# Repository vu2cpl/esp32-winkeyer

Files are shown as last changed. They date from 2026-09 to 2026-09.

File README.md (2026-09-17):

# VUKEYER

VUKEYER is a WinKeyer-protocol compatible CW keyer on an ESP32, reachable over WiFi. Iambic
paddle keying with local element generation, a K1EL-compatible host
protocol so logging software talks to it as a WinKeyer, and an optional
FlexRadio backend that keys a 6000/8000-series radio over the network.
Settings are edited from a front-panel OLED's companion web page at
`vukeyer.local` and persist across power cycles.

WinKeyer protocol by Steve K1EL. K3ng CW keyer by Anthony Good K3NG used
as a behavioural reference; the implementation here is original.

Formerly "ESP32 WinKeyer". Renamed 2026-09-17, because WinKeyer is K1EL's
product name: this is a compatible keyer, not a WinKeyer.

## Status

| Piece | State |
|---|---|
| Keyer core — iambic A/B, sidetone, PTT, pot, break-in | working, bench-verified |
| Speed pot on GPIO 34 | working, wired and tracking on hardware |
| WinKeyer protocol engine (WK 2.3 host mode) | working with RUMlogNG; **audited against a genuine K1EL WK3.1 on 2026-09-13; status byte, load-defaults order, admin table and pot byte fixed and re-verified the same night; echo now paced per letter on both backends, within ~60 ms (local) / ~150 ms (Flex) of the K1EL**; admin 0 (Calibrate) argument byte fixed the following morning — it had desynced RUMlogNG's session setup ([findings](docs/k1el-probe-2026-09-13/README.md)) |
| WiFi TCP transport + mDNS `vukeyer.local` | working, verified over WiFi |
| FlexRadio backend — **paddle keying over the network** | working, verified on a 6600. **Fixed 2026-09-17:** CW went out at 0 W after a GUI client (SmartSDR/Maestro/AetherSDR) restarted or changed; the keyer now follows the GUI client and no longer sends `client bind` |
| RUMlogNG over USB serial (1200 8N2) | working — memories, typed text, echo |
| Host bridge (`tools/wk-bridge.py`) | implemented, never driven by a real logger; macOS will not let a PTY appear as `/dev/cu.*`, so a logger cannot select it there |
| OLED status panel (SH1106/SSD1306 128x64) | working, SH1106 at 0x3C on hardware; sent CW scrolls on the bottom band while sending (approved on hardware 2026-09-17) |
| HD44780 LCD 16x2 / 20x4 | working; the slice warning on it is untested |
| Settings web page at `vukeyer.local` | working; one screen without scrolling from ~880x1150 upwards |
| SEND / STOP as one button on the page | working; per control — text, tune, each memory, FSK |
| Persisted settings (NVS) | working, verified across a hard reset |
| Message memories (6) with `%C` expansion | working from the web page and a logger |
| Practice mode — sidetone only, nothing transmitted | working on hardware (2026-09-17), Flex backend |
| RTTY FSK on GPIO27 | implemented, polarity unverified on air |
| MQTT status + heartbeat | working against the shack broker |
| Arduino core | **3.3.11 / IDF 5.5.5** (pioarduino); 2.0.17 crashes under load |

**Bluetooth keyboard: built in, off by default, parked — it does not fit
on a classic ESP32.** A BLE keyboard (Amkette Optimus) pairs and types
reliably in a standalone probe (`src/probes/ble_kbd_probe.cpp`,
`ENV=ble-kbd-probe ./flash.sh`), and the keyer has the full feature: a
BT KEYBOARD card with scan/pair/forget, F1–F6 memories, Esc, PgUp/PgDn
speed, `/bt` on the CLI. But with the whole keyer running, Bluedroid leaves
only ~26 KB of heap — too little for WiFi, so the board drops off the
network. A boot-time check now switches Bluetooth back off and restarts
when free heap is under 60 KB, and the page says why. Realistic routes are
an ESP32-S3 (lighter NimBLE stack) or a PSRAM board — see `HANDOVER.md`.
Classic-Bluetooth-only keyboards are not supported by the core either way.

**Enclosure:** a two-part 3D-printable case with OLED window, pot, KEY LED,
five RCA sockets for KEY/PTT/FSK, a 3.5 mm paddle jack, 5 V and USB-C, and
a bay for the opto board (5 × PC817, or an LTV847 quad + LTV817) —
parametric OpenSCAD with built-in fit checks, in
[`enclosure/`](enclosure/README.md). Dimensioned from measured
parts; not yet printed. Measure yours if they are a different make.

**One hardware caveat on a devkit.** The USB-serial chip's DTR/RTS lines
reach the ESP32's reset pin, so a logger holding that port can reset the
board or hold it in reset — mid-over, which leaves a networked radio
transmitting. Measured: `RTS` asserted with `DTR` not asserted holds it
down indefinitely. Either drive the keyer through a separate USB-serial
adapter wired to TX/RX/GND only, or cut the auto-reset link to EN. See
"Serial / USB" below.

## Quick start

```bash
python3 install.py     # detects the host, prompts for local settings, verifies the build
./flash.sh             # build + upload (picks the serial port)
./monitor.sh           # serial monitor, 1200 baud
```

**PlatformIO must run on Python 3.10 or newer.** This firmware builds
against Arduino core 3.x (the pioarduino platform), which refuses older
Python with a bare `ERROR: Python version must be 3.10 ...` that never says
which PlatformIO it means. `install.py` checks first and offers to create
one in `~/.pio-venv313`, leaving any existing install alone; `flash.sh` and
`monitor.sh` find it the same way (`PIO=/path/to/pio` overrides). Why the
newer core: 2.0.17's `WiFiClient` double-frees an lwIP buffer under heavy
inbound traffic, which crashed this keyer within minutes of sending
memories to a FlexRadio — see `HANDOVER.md`.

The app partition is the single 3 MB `huge_app` layout, because the newer
core filled 94.8% of the default one. Nothing here uses OTA. Flashing
rewrites the partition table, so an older board needs no special steps.

`install.py` detects macOS, Raspberry Pi, Linux or Windows (with a manual
override), then asks for your MQTT broker, mDNS name and setup-AP details.
Answers go to **`include/secrets.h`**, which is git-ignored and overrides
the defaults in `config.h` — so a clone stays clean and an upgrade never
collides with your local edits. Press Enter through it all to accept the
defaults; nothing here is required to key CW.

**If the first build fails with "Failed to install Python dependencies
into penv"**, the ESP32 platform could not build its own Python
environment — PlatformIO's problem, not this firmware's. In order: update
the core (`pip install -U platformio`); delete the half-installed
`~/.platformio/platforms/espressif32*` and
`~/.platformio/packages/tool-esp_install*` and re-run, because a partial
install never repairs itself; on Windows use Python from python.org rather
than the Microsoft Store build, whose sandboxed paths break virtualenv
creation; and check that antivirus or a proxy is not blocking pip. `pio run
-e esp32-vukeyer -v` shows the underlying pip error.

**On Windows** `flash.sh` / `monitor.sh` cannot run, so use the
cross-platform equivalents, which pick the port the same way:

```bash
python install.py flash            # build + upload
python install.py monitor          # 1200 baud
python install.py monitor 115200   # after /baud 115200
```

The port is never guessed when several boards are attached — some CP2102s
share factory serial `0001`, so the wrong board would be flashed silently.

1. First boot opens WiFi AP **`vu2cpl-vukeyer-setup`** (password
   `vu2cpl1234`). Join it from a laptop or phone; a captive portal opens
   where you pick **your own network** and enter its password. Creds
   persist in NVS. The portal does not time out, and the keyer keys
   normally while it is open — onboarding is non-blocking by design.

   Put the keyer on the **same subnet as the logging computer** (and the
   radio, if using the Flex backend): `vukeyer.local` and Flex discovery
   are both broadcast-based and do not cross subnets or VLANs. For the
   radio there is a way round it — **Find radio** on the web page (see
   FlexRadio below).

   `/wifi` shows the current network, `/wifi portal` reopens the portal,
   `/wifi reset` clears the saved credentials and reboots.

   **Security note:** the WinKeyer TCP port is unauthenticated — anyone on
   that network can key the transmitter. Use a trusted LAN, not a guest or
   open network.
2. Copy `include/secrets.h.example` → `include/secrets.h` and set
   `MQTT_HOST` plus the MQTT role account and password. `secrets.h` is
   git-ignored. Leave `MQTT_HOST` out and the build uses the placeholder
   in `config.h`, which is almost certainly not your broker.

## Wiring

**Schematic: [`docs/wiring.svg`](docs/wiring.svg)** — the whole station on
one page, including the second USB-serial adapter used as a listen-only
debug console and why it exists.

| Signal | GPIO | Notes |
|---|---|---|
| Paddle dit (tip) | 25 | internal pullup, paddle closes to GND |
| Paddle dah (ring) | 26 | internal pullup, paddle closes to GND |
| Key out | 33 | active high → opto (PC817 + 330 Ω, or LTV847 + 220 Ω) or NPN → rig KEY |
| PTT out | 32 | active high → opto (PC817 + 330 Ω, or LTV847 + 220 Ω) or NPN → rig PTT |
| Sidetone | 4 | passive piezo to GND |
| Speed pot | 34 | ADC1, 10 k **linear** pot across 3V3–GND, wiper to 34; **enable with `/pot on`** |
| Status LED | 2 | onboard — lit while the key is down |
| OLED SDA | 21 | 128x64 I²C panel, optional |
| OLED SCL | 22 | |
| KEY out 2 | 18 | radio 2 KEY, same drive as radio 1 |
| PTT out 2 | 19 | radio 2 PTT |
| FSK out | 27 | RTTY keying line, mark = idle (invertible) |

Paddles need no external parts.

**Debug console (optional, and very useful).** A second USB-serial adapter,
3.3 V, wired **RX ← GPIO1 (TXD)** and **GND ← GND**, with its **TX left
disconnected**. That last point matters twice: two transmitters on one RXD
line would fight, and with no TX wire nothing can be injected into a
logger's session. It gives a console to watch while a logger owns the
board's own USB port — which is how the crash backtrace that ended a day of
mystery resets was finally captured. The console is muted at 1200 baud, so
set `/baud 115200` from the web page when you want it to talk.

**Speed pot.** CW end to 3V3, wiper to GPIO 34, CCW end to GND, plus a
100 nF ceramic from wiper to GND at the pot — GPIO 34 is an unbuffered
ADC input and picks up sidetone PWM hash without it. Reversing the ends
just reverses the knob. Linear taper: a log pot wastes most of its travel.
Default range is 10–35 WPM (`/pot 10 35` to change). The knob is disabled
in firmware until `/pot on` is given, because GPIO 34 floats on a board
with no pot wired; that setting then persists.

Expect the top of the knob's travel to be a small dead zone: ADC_11db
saturates near 3.1 V rather than 3.3 V. Normal ESP32 behaviour.

The speed follows the knob through a **0.6 WPM hysteresis band**. A pot
parked on a step boundary otherwise alternates between two speeds forever,
and each flip is both a speed change and an unsolicited WinKeyer pot byte —
a stream that saturates a 1200-baud host link. Hysteresis is the right cure
rather than heavier smoothing or a settle delay: those fix the dither by
adding lag to every deliberate turn as well, which the operator feels at
once as a sluggish knob.

**OLED (optional).** VCC→3V3, GND→GND, SDA→21, SCL→22. Most breakouts
carry their own pull-ups; if yours does not, add 4.7 kΩ from each line to
3V3. The firmware probes 0x3C then 0x3D at boot and stays off if nothing
answers, so an un-wired board is unaffected.

**The I²C bus runs at 100 kHz by default**, and that is deliberate. An
earlier version tried 400 kHz and kept it if the panel answered its address
there — which proves nothing, because an address probe is one byte and a
frame is a thousand. A panel on breadboard leads passes the probe and
renders nothing, giving a display the firmware reports as present and
enabled while the glass stays dark. `/disp fast` opts into 400 kHz on
wiring that deserves it (~25 ms a frame against ~100 ms); the choice
persists, and `/disp slow` goes back.

**If the panel stays dark, run `/i2c`.** It scans the whole bus and prints
every address that answers, so "wired wrong" and "wrong address" stop
looking alike. It also adopts a panel wired up after boot — no reset
needed. Detection runs at 100 kHz on purpose: a panel on breadboard leads
answers reliably at 100 kHz but only intermittently at 400 kHz, which
otherwise shows up as a display that works on some boots and not others.
Rendering then moves to 400 kHz only after the panel proves it answers
there (a 128x64 frame is 1 KB — ~25 ms at 400 kHz, ~100 ms at 100 kHz, all
of it inside a blocking transaction). The boot line reports which speed
won; a 100 kHz fallback is your cue to add pull-ups or shorten leads.

**Four panel types are supported, all I²C on the same two pins:**

| Type | Address | Layout |
|---|---|---|
| OLED SH1106 128x64 (1.3") | 0x3C / 0x3D | large WPM digits, activity box, sent CW scrolling |
| OLED SSD1306 128x64 (0.96") | 0x3C / 0x3D | as above |
| LCD 20x4 via PCF8574 backpack | 0x27 / 0x3F | four text rows |
| LCD 16x2 via PCF8574 backpack | 0x27 / 0x3F | speed + one status row |

The **family is auto-detected** — OLEDs and LCD backpacks live at different
addresses — so one firmware runs whichever panel is plugged in. Swap the
panel and pick **Auto-detect** on the web page (or `/disp auto`) to re-probe;
no reflash.

What *cannot* be detected, because each pair shares an address:

- **SH1106 vs SSD1306** — wrong choice puts the image 2 px right with a
  garbage sliver down the left edge (SH1106 has 132 columns of RAM to the
  SSD1306's 128). Fix with `/disp ssd1306`.
- **16x2 vs 20x4** — same chip, so a wrong choice just truncates or leaves
  rows blank. Fix with `/disp lcd16x2`.

### Reading the display

**OLED, 128x64:**

```
VUKEYER             -52dBm     link quality, or "no wifi"
--------------------------
 28 WPM  POT        [ KEY ]    speed, where it came from, activity
--------------------------
FLX1   B  HOST+NET             backend+radio, iambic mode, host links
192.168.1.20                   address, or "join <setup AP>"
```

**While sending, the bottom two lines become the CW itself**, in large
letters (12 characters), newest on the right and scrolling left: paddle
and memories, typed text and a logger's text alike. They go back to the
backend line and the address once sending has stopped: no key-down in the
last 150 ms, no tune carrier, PTT off, and 3 s since the last character.
PTT counts, so on a long PTT tail the text stays up until the tail ends.
The LCDs switch back on the same rule.

```
VUKEYER             -52dBm
--------------------------
 28 WPM  POT        [ KEY ]
--------------------------
    CQ CQ VU2CPL               what is being sent, large
```

Paddle text is the keyer's own decode of your sending, so an odd letter
there means the decoder read your spacing differently, not a fault in the
radio. Buffered text appears as the keyer's sidetone copy finishes each
character, which on the Flex is held back to match the air.

In practice mode the title reads `PRACTICE NO TX`, ahead of any slice
warning.

**LCD 20x4** carries the same fields as text. Row 3 shows the last 20
characters sent while sending, and the address otherwise. Row 4 gives way
to `PRACTICE NO TX` or a slice warning:

```
28 WPM POT   KEY
FLX1   B HOST+NET
192.168.1.20
-52dBm  tail 400ms
```

**LCD 16x2** has room for two rows, so the iambic mode letter is dropped —
it changes once a year, whereas the live radio can change between overs.
Row 2 shows the last 16 characters sent while sending:

```
28WPM POT FLX1
192.168.1.20
```

Every indicator:

| Shown | Meaning |
|---|---|
| `28 WPM` | current speed |
| `POT` | speed is following the knob |
| `FIX` | speed was set by host, CLI or web — the knob is off |
| `KEY` | key is down right now |
| `TUNE` | continuous carrier, latched until you stop it |
| empty box | idle |
| `LOCAL` | keying the wire: KEY on GPIO33, PTT on GPIO32 |
| `FLX` | keying the radio over the network, slice ready |
| `FLX!` | radio connected but **the slice is not in CW mode** — it will transmit nothing |
| `FLX?` | **not connected** to the radio at all |
| `…1` `…2` `…B` | which radio the key line drives — 1, 2, or **both** |
| `A` / `B` | iambic mode (not shown on 16x2) |
| `HOST` | a WinKeyer host session is open (a logger is attached) |
| `----` | no host session — placeholder, so the field keeps its width |
| `+NET` | a TCP client is connected over WiFi as well |
| `-52dBm` | WiFi signal; `no wifi` if the link is down |
| `SLICE USB, NOT CW` | the Flex's slice is in another mode; `NO SLICE IN USE` if there is none. OLED: replaces the `VUKEYER` title. 20x4: replaces row 4 (dBm/tail). 16x2: alternates with the IP every 2 s when not sending, as `SLICE USB NOT CW` (`DIGU: NOT CW` for 4-letter modes) |

The radio number is attached to the backend as one token — `LOCAL1`,
`FLX2`, `FLXB` — rather than spaced, because the "both" letter `B` would
otherwise sit beside the iambic mode letter, which is also `A` or `B`.

`FLX!` is the one worth knowing on sight: everything looks connected and
the keyer reports no error, but SmartSDR has no slice in CW mode so nothing
reaches the air. Every panel also spells it out with the slice's mode (see
the table), and the web page shows an amber banner. Memories go to the
radio as `cwx` text, which it sends only
on a CW slice. The paddle's PTT still keys the radio in other modes, so
this can look like "paddle works, memories don't".

### LCD power — read this before blaming the firmware

**HD44780 LCDs want 5V, and the ESP32 is a 3.3V part.** Run one from 3V3
and the characters come out so faint they look absent, at any setting of
the contrast trimmer, with a dim backlight to match. Nothing in software
can help: contrast on an HD44780 is the analogue Vo pin, not a driver
setting. This is why the OLEDs are trouble-free — SSD1306 and SH1106
modules are native 3.3V.

Feed the LCD's **VCC from the devkit's 5V / VIN pin** (USB 5V). But note
the trap: the PCF8574 backpack's onboard pull-ups then tie SDA and SCL to
5V, and **ESP32 GPIOs are not 5V tolerant** — that is how GPIO21/22 get
damaged. Two safe ways:

1. **Move the pull-ups.** Remove the backpack's two pull-up resistors and
   fit 4.7 kΩ from SDA and SCL to **3V3** instead. I²C is open-drain — the
   chip only ever pulls the line low — so with the pull-ups on 3.3V the bus
   never exceeds 3.3V while the LCD still runs at 5V. Tidiest answer.
2. **A bidirectional level shifter** (BSS138-type) between the ESP32 and
   the backpack. No soldering on the module.

Before either, sweep the contrast trimmer through its full range with the
panel powered. Faint ghosting at one end confirms the voltage diagnosis; a
completely dead panel at every setting points at wiring or the address
instead — run `/i2c`.

See `include/pins.h`.

## Serial / USB — baud matters

**The firmware defaults to 1200 baud, 8N2.** That is the K1EL WinKeyer
serial standard, and loggers open the port that way without asking —
RUMlogNG was observed doing exactly this (`stty` reported
`speed 1200 baud; cs8 cstopb`). At any other rate a logger's handshake
arrives as noise and no session ever opens, which looks exactly like a
dead keyer.

The console shares that port, so at 1200 baud the boot log is trimmed to
one line and WiFiManager's chatter is silenced — every character printed
is one the host waits through before its Host Open is answered. Use the
web page or `/status` for detail.

```bash
/baud 115200     # readable console; a logger will NOT talk to it here
/baud 1200       # WinKeyer standard; what loggers expect
./monitor.sh          # defaults to 1200
./monitor.sh 115200   # when you have set the console rate
```

The **USB / WIFI** section of the SYSTEM card on the web page sets the same thing, and is the
escape hatch if you pick a rate you cannot monitor at — WiFi is unaffected
by the serial rate.

**Known limitation of this board, and it is worse than noise.** The USB
chip's DTR and RTS lines drive the ESP32's EN (reset) and GPIO0 through the
devkit's auto-reset transistors. Two consequences, both measured here:

- **Opening or closing the port resets the board.** The ROM then prints its
  banner at 115200 whatever the firmware's rate is, so a logger sitting at
  1200 sees a burst of garbage before the handshake. Noise, not a fault.
- **`RTS` asserted while `DTR` is not holds EN low — the board stays dead**
  until the lines change. Silent: no boot banner, no WiFi, no app. A logger
  that parks the lines that way stops the keyer mid-over, and on the Flex
  backend the radio is left transmitting because the key-up never goes out.
  Measured 2026-09-12 with all four combinations; only that one kills it.

A real K1EL WinKeyer ignores DTR/RTS, so loggers drive them freely — this
is a devkit problem, not a logger bug, and no firmware can defend against
its own reset pin. Fixes, in order of preference:

1. **Disable the auto-reset link to EN.** Find the two `J3Y` transistors by
   the USB chip, identify by continuity which one's top leg (collector)
   reaches the `EN` header pin, and lift that leg. Flashing then needs
   BOOT held while EN is tapped. Bring the cut ends to a jumper if you want
   auto-flash back for development.
2. **Give the logger a serial adapter with only TX/RX/GND wired** to the
   keyer, DTR/RTS unconnected. No soldering on the devkit, but a second lead.
3. **Move to the ESP32-S3 env**, whose native USB has no DTR-driven reset.
   The env builds (fixed 2026-09-13) but has not yet been run on an S3
   board, and a logger opening its native USB port is untested.

## Sharing the port with a logger

**At 1200 baud the console is silent by default**, because that rate means
a logger owns the port: every character the keyer prints lands in the
logger's CW window as text. That covers the boot log, the reset reason, the
watchdog line and the ESP core's own logger (`E (1816) task_wdt: ...`),
which writes to the UART without passing through `Log::` — muting one and
not the other is why an early attempt still leaked. `/log on` turns it back
on; `/baud 115200` means "a human is here" and leaves it on. One thing
firmware cannot suppress: the ROM's own boot banner is printed at 115200
before any of our code runs, so a port opened at 1200 sees a character or
two of noise after every reset.

The console and the WinKeyer protocol share one serial port, so **while a
host session is open the console goes silent** (`src/log.cpp`). A `[FLEX]`
line written during a session is not a log message to the logger — it is
protocol data, and it appears in the logger's CW window as garbage text.
The web page and MQTT report the same state and do not touch serial, so
use those while a logger is connected.

### Sidetone while the radio is keying

On the Flex backend the radio generates buffered CW itself, so the keyer
has no elements of its own to sound and is silent while the rig transmits.
The same text is therefore also run through the local keyer purely for
**monitor sidetone** at the same WPM (`/monitor on|off`, or the checkbox on
the web page).

Those monitored elements are withheld from the key hook
(`Keyer::setHookPaddleOnly`) — otherwise they would key the radio a second
time on top of `cwx send`. Paddle elements and `tune` still reach the hook.

### Echo

WinKeyer character echo is **host-controlled**: mode-register bit 2. If a
logger never sets it there is no echo, and that is the protocol, not a
fault. `/api/state` reports `echo` and `modereg` so you can see what the
host actually asked for rather than guessing — RUMlogNG sets `0x07`, so it
does want echo.

Echo exists so the host can highlight the character being **sent**, which
makes it a timing signal, not just a copy. On the Flex backend the whole
buffer is handed to the radio in one batch, so echoing as characters are
queued dumps the entire message instantly: the host's highlight runs ahead
of the air and desynchronises, and after the first message later echoes are
discarded. Echo is therefore paced against the radio's own `cwx sent=`
progress reports. Measured at 20 WPM, `TEST DE VU2CPL` echoes over 5.5 s
with the gaps matching each character's length.

### Paddle echo — capturing hand-sent text

Separate from character echo, and separate in the protocol too: **mode
register bit 6**. When active, characters you send on the paddle are echoed
to the host so a logger can capture what was keyed by hand.

RUMlogNG sets `0x07` — it asks for character echo but **not** this — so
`auto` leaves it silent. Force it if you want hand-sent text logged:

```bash
/pecho on      # regardless of what the host asks for
/pecho auto    # follow the mode register (default)
/pecho off
```

The web page has the same control with a live `active`/`inactive` readout.

The decode is exact rather than signal decoding: the keyer generated those
elements itself, so it knows precisely what they were and only has to judge
where a character ends — 2 dit-times of silence for a character, 5 for a
word, both scaling with WPM automatically. Buffered text is excluded; the
host already knows what it asked for.

Two limits worth knowing: characters not in the Morse table decode to
nothing and are dropped, and a prosign keyed as merged elements comes back
as whatever single pattern it forms, not as the letters you had in mind.
Forcing echo on when the host did not request it may also confuse a logger
that is not expecting unsolicited characters — hence the switch.

## Two radios

`/radio 1|2|both` selects which KEY/PTT pair the keyer drives — radio 1 on
GPIO33/32, radio 2 on GPIO18/19 — and persists. `both` is deliberate, for a
rig plus an amp or monitor, but it keys two transmitters at once so it is
never the default. Switching radios drops every line first, so a
transmission can never strand the outgoing radio keyed.

## Practice mode

Tick **Practice** at the top of the KEYER box on the web page, or
`/practice on|off`. The keyer then makes sidetone for everything (paddle,
memories, typed text, a logger's text, TUNE) but transmits nothing:
- no KEY or PTT line is driven, and the PTT lead-in is skipped;
- nothing goes to a FlexRadio, neither `cw key` nor `cwx send`;
- a logger's PTT command is ignored, and RTTY SEND is refused.

Text plays with your own weighting and Farnsworth, as on the local backend.

An amber banner on the web page says so, and the OLED title, row 4 of the
20x4 LCD and row 2 of the 16x2 LCD (taking turns with the address) read
`PRACTICE NO TX`. Switching on or off stops whatever is being sent. The
keyer task makes the switch between elements, so a key-down sent to the
radio is always followed by its key-up.

**Practice is not saved.** The keyer always boots ready to transmit, so a
practice session can't carry through a power cycle into a contest.
`practice` in `/api/state` shows the current state.

## Message memories

Six slots of canned text in flash, played through whichever backend is
current. `%C` expands to your callsign, so a memory survives a contest call
change.

```bash
/call VU2CPL
/mem 1 CQ TEST %C %C K
/mem 1              # play it
/mem                # list all six
```

The web page has a MEMORIES card with SAVE and PLAY per slot (Send and FSK / RTTY sit below them in the same card); the PLAY of
the slot that is going out turns into a red STOP, so the stop is on the row
you pressed rather than somewhere else on the page. No GPIO cost —
front-panel buttons can be wired to these later.

**Anything that originates text must go through `HostLink::sendText()`**,
not `Keyer::sendChar()`. On the Flex backend the radio generates the CW and
those local elements are deliberately withheld from the key hook, so a
direct send produces sidetone and no RF.

## RTTY / FSK

An FSK keying line on **GPIO27** for a rig's FSK input: Baudot (ITA2) at
45.45 baud, 1 start bit, 5 data bits LSB first, 1.5 stop bits, mark idle.

```bash
/fsk RYRY DE VU2CPL     # send
/fsk baud 45.45         # or 50, 75
/fsk invert on          # if the rig wants mark low
/fsk diddle on          # LTRS while idle, keeps the far end synchronised
/fsk stop
/fsk                    # status
```

The web page has an FSK panel with its own send box. Its button is SEND
while the line is idle and turns into a red STOP for as long as the over is
going out — the same one button, not two.

**Polarity is the one thing you must confirm on air.** Getting `invert`
wrong prints reversed-case gibberish at the far end rather than nothing, so
silence means a wiring fault and garbage means the wrong polarity.

Two implementation notes that matter if you touch this code. The bit timer
runs at the **half-bit** period, because the 1.5-bit stop is three
half-bits and a 22 ms bit cannot be timed from the 1 ms FreeRTOS tick
without ~4% jitter. And the far end's **LTRS/FIGS shift state is tracked
explicitly**: `Q` and `1` are the same five bits, so losing the shift
prints digits as letters for the rest of the over. Shift characters are
injected only when a character actually needs the other case, and space,
CR and LF are treated as neutral so they never force one.

Verified by timing, not by scope: `RYRY DE VU2CPL` takes 2.87 s at 45.45
baud against a theoretical 2.81 s, and 1.77 s at 75 baud against 1.70 s.
The 14-character message occupies 17 code times, which is the two shift
characters `2` forces.

## Power — read this if the keyer resets while you key

The ESP32 draws its heaviest current in short WiFi transmit bursts, and
paddle keying on the Flex backend sends a packet per key edge — roughly
twenty bursts a second at 25 WPM. On a marginal supply the 3.3 V rail sags
through those and the chip **browns out and restarts**.

It is **intermittent**, which is what makes it hard to pin: in testing the
same board and cable browned out within two characters of keying on one
run and survived minutes of heavy paddling on the next. It does not track
any one cable or power setting reliably — it tips over when several small
things happen to line up (connector contact resistance, other load on the
same USB bus or hub, how the cable is seated).

How to recognise it: **the web page footer, or `/api/state`, reports
`last reset: BROWNOUT (power)`.** That comes from the chip's own brownout
detector, so it is conclusive. (A plain `power-on` is not — opening the
serial port pulls EN on this devkit and reports the same.)

What to do about it, in order of robustness:

1. **Fit a 470–1000 µF capacitor across 3V3 and GND**, short leads, at the
   board. This is the real fix: it adds margin without needing to know
   which factor is marginal on a given day.
2. **Power from a decent 5 V supply on VIN** rather than USB. An external
   supply held full power through heavy keying in testing.
3. **Lower the WiFi transmit power** — `/txpower 11`, or *WiFi power* on the
   web page. That roughly halves the burst current. It costs range (it
   affects how well the access point hears you, not how well you hear it),
   so treat it as a workaround rather than a cure.

## Bench-testing the key and PTT lines

The four outputs are plain active-high 3.3 V GPIOs, so an LED and a
resistor to GND is enough to watch them:

| Line | GPIO |
|---|---|
| KEY / PTT, radio 1 | 33 / 32 |
| KEY / PTT, radio 2 | 18 / 19 |

Anode to the GPIO, cathode through **330 Ω** to GND — about 4 mA, bright
enough and well inside what an ESP32 pin should source. Do not go below
~150 Ω.

**On the Flex backend the KEY line is deliberately idle** (the radio is
keyed over the network instead, so the rig is not keyed twice) — a KEY LED
will stay dark however much you send. Use `/backend local` to test it. PTT
is live on both backends.

`/tune` is the easiest test: a continuous key-down with PTT asserted, so
both LEDs sit steady rather than flickering through elements. Sending text
afterwards shows the sequencing — PTT leads the first element by the
lead-in and holds for the tail after the last.

`/radio 2` moves keying to the second pair and `/radio both` drives all
four, which is also the quickest way to confirm the `LOCALB` / `FLXB`
indicator on the display.

**A PTT line that is up for 10 s with nothing keying it is forced down**
by a safety backstop, and the console says so
(`PTT was stuck with no keying`). That is deliberate — a lost transition
must never leave a transmitter keyed — and it does not apply to `/tune`,
which is a key-down, or to RTTY, which holds the line for a whole over on
purpose. If you see it during ordinary sending, it is a bug: report it
with what you were sending and how long the keyer had been quiet
beforehand.

## Connecting logging software

The keyer speaks the WinKeyer protocol over a TCP socket. Loggers want a
serial port, so run the bridge:

```bash
./tools/wk-bridge.py
```

That creates `/tmp/vukeyer` (a symlink to a PTY) and shuttles bytes to
`vukeyer.local:8088`. Point the logger at that path and choose WinKeyer
as the keyer type. Verified hosts: anything speaking WK2 — N1MM+, DXLog,
RUMlogNG, MacLoggerDX, SkookumLogger, fldigi.

**RUMlogNG: set the keyer type to K3NG, not K1EL.** Both send the same
set-up. With K1EL, RUMlogNG keeps repeating host-open and ignores the
keyer's version-23 reply for 18 s to 2 minutes. At 1200 baud the queued
opens take that long to drain, and the keyer has to answer every one.
K3NG's keyer also reports 23, and with that setting the session opens at
once (measured 2026-09-17). The one exception is the **first open after
flashing the keyer**: even on K3NG, RUMlogNG floods host-open and then
shows the wrong speed. Close and reopen the port once after a flash. A
power cycle or restart does not cause it.

For **N1MM+ in a VM**, map the VM's COM port to the host TCP socket with
the VM's serial-over-TCP option instead of using the bridge.

Network latency does not affect CW: every element is timed on the keyer
(or on the radio, in Flex mode). The socket only carries text and status.

Wired fallback: the USB serial port is a text CLI at 115200 that switches
itself into the WinKeyer binary protocol as soon as a host-open command
arrives, and back to the CLI on host close.

## FlexRadio

```
/flex on                 # enable the backend (off by default, persists in NVS)
/flex ip 192.168.1.50   # pin the radio's address
/flex auto               # or rely on discovery (same subnet only)
/backend flex            # route buffered text to the radio — this transmits
```

**Discovery only works on the radio's own subnet** — it is a raw UDP
broadcast, unlike mDNS. If the radio is on another segment, pin the IP.

**Find radio** on the web page does that for you. It tries every address
in one /24 for the SmartSDR API port (TCP 4992) — a plain TCP connection,
which a router forwards where a broadcast is dropped — and lists what
answers as `IP · model · nickname` buttons; click one to set Radio IP.
Leave its box blank to scan the keyer's own subnet, or type the radio's
first three octets (`192.168.1`). About 15 s per /24, in a background
task so keying is unaffected. It is read-only on the radio: connect, read
the `V<version>` greeting that marks a Flex, ask `info`, disconnect.
`POST /api/flexscan?net=192.168.1` starts one; `GET /api/flexscan`
reports progress and results.

**In Flex mode the paddle keys the radio over WiFi — no KEY or PTT wire.**
The keyer asserts PTT (`xmit 1`), sends each element as `cw key 1/0` with
a `time=` timestamp so the radio *schedules* the edge rather than keying
on arrival, and releases PTT after a tail. That timestamp is what keeps
the CW readable across a jittery link; it is the same mechanism Maestro
and MORCONI use.

Sidetone stays local and follows your own paddle timing, so your fist
sounds right in the ear whatever the network is doing. The local key
output is disabled in this mode so the rig is not keyed twice.

**Requirements — both fail silently, with no error from the radio:**

- SmartSDR must have **a slice in use, in CW mode**. With no slice the
  radio simply transmits nothing. `/status` reports readiness, the web
  page and OLED show a warning naming the slice's mode, and the console
  warns when you key without it. The keyer follows the last slice the
  radio reports, not specifically the TX slice, so with two slices open
  the warning can be wrong.
- SmartSDR (a GUI client) must be connected — with none the radio reports
  `tx_allowed=0` and nothing may transmit at all.

**The keyer keys on behalf of that GUI client** by putting the client's
handle on every `cw key`. It follows the client: when SmartSDR, Maestro or
AetherSDR restarts it comes back under a new handle, and the keyer picks
that up by itself (`flex.guihandle` in `/api/state` shows the one in use).
A `cw key` under a handle that has gone is accepted with no error and
silently dropped, so that is the first thing to compare when paddle keying
raises PTT but makes no power.

**`client bind` is off by default** (`/flex bind on|off`, web page "bind
GUI"). On a 6600 in September 2026, binding to a GUI client that had just
connected left the radio's CW generator stuck: paddle keying and memories
both keyed the transmitter at 0 W until a stalled `cwx clear` released it.
Unbound, both work. If a keyer upgraded from an older build still has bind
switched on in its saved settings, switch it off.

**Sidetone delay (`/mondelay`, default auto).** The radio generates
buffered CW itself, so it starts a few hundred ms after being handed the
text — the network hop plus its own CW start — while the local monitor copy
starts at once. The sidetone therefore runs AHEAD of the air, which sounds
like the radio unkeying early. The keyer times that gap itself (from
`cwx send` to the interlock reporting TRANSMITTING, smoothed, and only when
the radio was idle first) and holds the monitor copy by it: measured 229 ms
on a 6600 over WiFi here. `/mondelay 250` pins a value instead, `/mondelay 0`
disables it. The first transmission after a reset has nothing measured yet.
Auto lines the copy up with the **radio**. A client that plays the radio's
sidetone back as audio (AetherSDR here) adds its own network and audio delay
on top, which the keyer cannot measure. Matching that by ear took a manual
245 ms here, against 87 ms measured. To keep following the measurement and
still cover the client, leave it on auto and add an **extra** (`/monextra N`,
0–1000 ms, **Delay extra** on the web page, saved): about 160 for AetherSDR
here. The extra is ignored for a manual value.

**The sidetone copy also follows the radio's real timing, per speed.** A
Flex sends each CWX dit unit a little long: about 0.7–0.8 ms more than
1200/WPM at every speed (735 µs at 10 WPM, 779 µs at 35 WPM here). A copy
at the exact rate drifts ahead through a long message. Because the extra is
roughly fixed in milliseconds, a percentage learned at one speed is wrong at
others. So the keyer learns it **per WPM, 5–50**: it times the radio's
`cwx sent=` reports over any run of 40+ units of its own text sent without a
pause (a run stops where the radio may have waited for typed text), refines that
speed's entry (smoothed, weighted by run length: a 234-unit CQ moves it a
quarter, a short typed word far less, because the radio's reports wobble by
up to ~100 ms), interpolates for speeds not played yet (700 µs
before anything is learned), and adds it to each unit of the copy, carrying
the sub-millisecond remainder. The table and the start delay are kept in
flash (written when an entry is first learned or has moved more than 50 µs
from the saved value, at most once a minute), so they survive a reboot. `cwextra` in `/api/state` is the value in use at the current speed.
`GET /api/cwtable` lists all 46 speeds (`runs` 0 = interpolated), and
`POST /api/cwtable?reset=1` forgets it. In step from 10 to 50 WPM on
hardware.

The monitor copy also ignores weighting and Farnsworth, because the radio
has neither — it exposes speed, iambic, break_in and qsk, nothing else. A
logger that sets Farnsworth (RUMlogNG sets 20 every session) would otherwise
stretch the sidetone against an unstretched transmission.

**The radio's CWX speed is kept equal to the keyer's.** Anything else on the
API — SmartSDR's own CWX speed control, for one — can change it, and then
the radio sends at its speed while the sidetone runs at ours: PTT drops with
the radio while the sidetone carries on for seconds. The keyer reads the
radio's reported `cwx wpm=` and, whenever the radio is idle and differs,
sets it back (at most every 2 s; never mid-message, where a logger's
buffered speed change is allowed to differ).

Tuning knobs, should keying misbehave on a different radio or firmware:
`/flex cmd key|ptt` (which keying command), `/flex bind on|off` (default
off, see above),
`/flex ptt on|off` (whether we assert `xmit`). Defaults are what works on
a 6600 running SmartSDR 4.2.20.

The `backend` setting persists in NVS, so it survives a reboot.

Not used: `cwx send`. It sends *text* for the radio to key itself, which
cannot carry a fist, and this radio refuses CWX to a second client
anyway. Wiring GPIO 33 to the KEY jack still works and is the
lowest-latency option, but is no longer necessary.

Paddle keying deliberately stays on the local key output — real-time
element timing over WiFi would carry the jitter. For a Flex in the same
shack, wire the key output to the radio's KEY jack and use the network for
buffered text.

## Tools

```bash
./tools/wk-test.py --serial /dev/cu.usbserial-0001   # exercise the protocol
./tools/wk-test.py --host vukeyer.local             # ...over WiFi
./tools/wk-bridge.py                                 # TCP → serial port
./tools/wk-timing.py --text "CQ TEST"                # timestamped status
./tools/flex-check.py                                # why isn't it keying?
./tools/uptime-watch.py                              # restarts, outages, stalls
./tools/console-capture.py /dev/cu.usbserial-0001    # console, without resetting it
./tools/flex-check.py --key                          # ...and key it (TRANSMITS)
./tools/flex-ptt-watch.py --keyer <ip> --radio <ip>  # keyer + radio PTT on one clock
./tools/boot-listen.py /dev/cu.usbserial-0001        # is it boot-looping?
./tools/ptt-check.py --ip <ip>                       # PTT sequencing + every STOP
./tools/host-watch.py --ip <ip>                      # what is a logger changing?
KEYER=<ip> ./tools/wk-trace-view.py                  # logger bytes, open floods folded
KEYER=<ip> ./tools/wk-open-timing.py                 # time the logger open handshake
KEYER=<ip> ./tools/flex-trace-record.py out.log      # record radio trace + CW table
./tools/cw-runs.py out.log                           # time each CW run in a recording
```

**`wk-open-timing.py` answers "is the keyer slow to connect?"** It opens
the USB port as a logger does (1200 8N2), times one host-open at a time,
then floods opens without waiting and measures how long the backlog takes
to drain. Close the logger's port first. On 2026-09-17 it showed the keyer
answers within ~8 ms, and that a flood of 5224 opens takes 95.7 s to drain
at 1200 baud: the slow RUMlogNG open is a backlog, not the keyer.

**`flex-trace-record.py` + `cw-runs.py` check the sidetone timing
learner.** Record while operating, then `cw-runs.py` splits the radio's
`cwx sent=` reports into runs the same way the firmware does and prints
each run's µs-per-unit. Compare those with the table steps in the
recording. That is how short typed words were found to pull the 25 WPM
entry up.

**`ptt-check.py` needs no paddle, no logger and no radio.** It drives the
keyer through its own API on the local backend and polls `/api/state` at
10 Hz, which is the only way to see faults like a PTT line that comes up
and drops one millisecond into the lead-in. It restores the backend it
found, but it does key GPIO33/32 — run it into a dummy load or with
nothing attached.

**`host-watch.py` answers "what is my logger doing to my settings?"** —
including `pincfg` and `hostdef`, the raw bytes of the two host commands
whose bit layout is not obvious from outside. A logger sends its defaults
at session OPEN, so close and re-open the session before concluding
anything: a mid-session toggle of RUMlogNG's own PTT boxes sends nothing
at all.

**`flex-check.py` is the first thing to run when the Flex will not key.**
Every prerequisite fails silently — the radio reports no error for a
missing slice, a slice in the wrong mode, or a missing GUI client — so it
checks all of them at once.

**`wk-timing.py` timestamps every status byte** and times the BUSY span
against the text's predicted duration. It also checks that no KEYDOWN
arrives for text: a genuine K1EL reports KEYDOWN for tune only. Counting status bytes in fixed windows
gives false negatives when a delayed burst lands outside its window; this
tells "not sent" from "reported late".

## Serial CLI

`/wpm N` `/mode a|b` `/swap` `/tune` `/pot on|off` `/pot <min> <max>`
`/ptt on|off` `/st N|on|off` (pitch 300-1000 Hz, default 600)
`/disp on|off` `/disp sh1106|ssd1306`
`/weight N` `/ratio N` `/farns N` `/lead N` `/tail N`
`/mondelay auto|N` `/monextra N` (sidetone delay; extra ms on top of auto)
`/practice on|off` (sidetone only, no TX; not saved)
`/backend local|flex` `/flex on|off|ip <addr>|auto` `/wifi [portal|reset]`
`/bt on|off|scan|forget` (on/off takes a restart) `/i2c` `/net` `/status`.
Any other line is sent as CW.

## Settings web page

`http://vukeyer.local/` (or the IP — `/net` prints it). Every label with a
dotted underline carries **hover help** — ranges, what a setting actually
does, and which GPIO it drives — so the panel stays scannable. Speed, mode,
paddle swap, sidetone, **weighting, dah ratio, Farnsworth, PTT lead and
tail**, pot enable and range, display, backend (with a **Find radio**
LAN scan for the Flex), plus a send box and tune. The page is four cards: **KEYER** (with Timing, Speed pot and
PTT sections), **MEMORIES** (with Send and FSK / RTTY), **BACKEND** and
**SYSTEM** (Display, USB / WIFI, BT keyboard). The Flex keying internals
(key verb, bind GUI, xmit) sit in a collapsed **Advanced keying** section with
a warning, because a wrong value leaves the radio silent with no error. Its
**DEFAULTS** button puts back the working set: `cw key`, bind GUI off, xmit
on. Live status LEDs for
host, TCP, key, tune, pot, Flex, OLED and KBD, polled once a second.

The **BT KEYBOARD** section of the SYSTEM card (off by default) enables Bluetooth — with a RESTART
button, since the switch applies at boot — then SCAN lists keyboards in
pairing mode, one click pairs, and a passkey is shown large if the keyboard
asks for one. One keyboard is kept; FORGET drops it. `GET /api/bt` carries
the detail and scan list; `POST /api/bt?scan=1|connect=<addr>&type=<n>|
forget=1|restart=1` does the rest (restart is refused while transmitting).
**On a classic ESP32 it switches itself back off at boot** for want of heap —
see Status above.

**Every button that starts something is its own STOP.** SEND, TUNE, a
memory's PLAY and the FSK send all turn into a red STOP while that thing is
transmitting, and go back when it ends — so exactly one STOP is on screen at
a time, on the thing you started. Stopping text or a memory clears the
radio's buffer as well as the keyer's.

Timing settings, all persisted and all validated the same way from the
CLI and the page:

| Setting | Range | Nominal | What it does |
|---|---|---|---|
| Weight | 10–90 | 50 | mark/space balance, **without** changing WPM |
| Dah ratio | 33–66 | 50 | dah length (50 = the standard 3 dits) |
| Farnsworth | 0, or 5–60 | 0 (off) | stretches only the gaps, to this WPM |
| PTT lead-in | 0–2000 ms | 50 | delay before the first element (GPIO32) |
| PTT tail | 0–2000 ms | 250 | hold after the last element |

**The tail releases two transmitters.** It sets both the local PTT line
and, on the Flex backend, the radio itself (`xmit 0`) — these are separate
timers and setting only one makes the control appear dead on whichever you
are listening to. `/api/state` reports `flextail` next to `tail` so you can
see they agree.

On the Flex backend the **KEY line (GPIO33) is idle** so the rig is not
keyed twice, but the **PTT line (GPIO32) stays live** for an amp or
sequencer — that is what lead-in still drives. The radio handles its own
T/R, so there is no Flex lead-in.

Out-of-range values are refused with the accepted range and nothing is
changed — `farns 3` answers `farnsworth: 0 (off) or 5..60`.

Number boxes step with **↑/↓ by 1, Shift+↑/↓ by 10**, clamped to the
setting's range. The value is written once you pause, so holding a key
costs one save rather than one per key repeat — these go to NVS. A field
you are editing is also exempt from the 1 Hz status poll, which would
otherwise overwrite what you are part-way through typing.

Same trust posture as the WinKeyer TCP port: **no authentication**, so
keep it on a trusted LAN. Visual style is borrowed from soft-MORCONI
(`~/projects/Morconi`) — that project is a browser UI plus a Node bridge,
so the look carried over and none of the code did.

### Host overrides end with the session

A WinKeyer host may set speed, mode, weighting and PTT lead/tail for the
length of its session — that is the protocol working as intended. RUMlogNG,
for instance, sets lead and tail to zero. Those values are **restored from
NVS when the host closes or the transport drops**, so a logger can never
leave the keyer reconfigured: without that, a session that set the tail to
zero left it there until the next reboot.

The web page shows the *effective* values, so while a logger is connected
you are seeing the host's numbers, not your saved ones.

### FlexRadio and where keying goes

Enabling the FlexRadio backend switches keying **to the radio**; disabling
it hands keying back to the **local key line**. Either is overridable from
the Keying selector afterwards. The coupling exists because the two
half-states are traps: keying a switched-off backend sends CW nowhere
while the page still claims the radio.

With Flex disabled the page hides its settings and drops it from the
Keying choices altogether, so an unreachable backend cannot be selected.

### Checking the settings page without flashing

The page is a PROGMEM string inside the firmware, so it normally takes a
flash to look at. It doesn't have to:

```bash
python3 tools/web-preview.py     # http://127.0.0.1:8791/
```

That serves the real page out of `src/web.cpp` against a stubbed API — edit
and reload, no board involved. **Use it before flashing UI changes.** A
clean build says nothing about whether the JavaScript runs: one session put
three faults on hardware that a single page load would have caught — a line
in the wrong scope that blanked the page entirely, `hidden` on a `.row`
doing nothing because `.row{display:flex}` outranks it, and `hidden` on an
`<option>`, which Safari ignores.

### Which settings stick

The **operator's** panel settings persist in NVS: speed, mode, swap,
sidetone, PTT, weighting/ratio/Farnsworth, pot enable and range, display,
backend. **Practice mode is the exception** and is never saved: every boot
is ready to transmit. The **host's** session settings do not — a speed N1MM sets over
the WinKeyer protocol is gone at the next boot, so a contest never leaves
the keyer permanently reconfigured.

### What a logger may change, and what it may not

The line is: **anything that shapes the fist or the local monitor is the
operator's; anything the logger needs to drive a QSO or read back is the
host's.**

| The host still sets | The operator keeps |
|---|---|
| Speed (`0x02`, `0x1C`, `0x0F` b1) | Sidetone pitch (`0x01`, `0x0F` b2) |
| Serial echo, paddle echo (`0x0E` bits 2, 6; `0x0F` b0) | PTT lead-in and tail (`0x04`, `0x0F` b4/b5) |
| Speed pot range (`0x05`, `0x0F` b6/b7) | Farnsworth (`0x0D`, `0x0F` b10) |
| | PTT line enable (`0x09` bit 0, `0x0F` b13) |
| | Weighting (`0x03`, `0x0F` b3) |
| | Dit/dah ratio (`0x17`, `0x0F` b12) |
| | Iambic A/B and paddle swap (`0x0E` bits 5:4, 3) |

The right-hand column is parsed and **recorded** — the status dump still
reports what the host asked for, so nothing in the protocol breaks — and
then not applied. Speed stays the host's because a logger changes it per
QSO and per F-key, and the speed knob already overrides it the moment you
turn it. Speed **0** means "use the knob", as on a K1EL: the keyer takes
the knob's speed at once. RUMlogNG sends it at every session open, just
after asking for the knob position, so the two show the same speed.

This is not what a real K1EL WinKeyer does; it is a deliberate difference.
RUMlogNG sets PTT lead/tail to 0, Farnsworth to 20, the sidetone to 1000 Hz
and the pin configuration to 0x00 on every session open, which on this
station meant no PTT sequencing, stretched spacing, the wrong pitch and the
PTT output switched off for as long as the logger was attached. Its own PTT
and key-out checkboxes never reach the keyer at all — they drive its rig
control. `/api/state` carries `pincfg` and `hostdef` if you want to see what
your own logger sends. To hand any of it back, restore the setter named in the
comment on that case in `src/hostlink.cpp`. CLI and web page both go through
`Settings::apply()`, so they cannot disagree about ranges or names.

**`GET /api/wktrace` shows the wire itself** — the last 1024 bytes between
the logger and the keyer, both directions, millisecond-stamped
(`ms H>K|K>H hex char`; `?clear=1` empties it). The serial port cannot be
sniffed while a logger holds it, and "the logger did not show it" looks
exactly like "the keyer did not send it". `tools/wk-trace-check.py` reads
it and lists any character the logger sent that was never echoed. `tools/wk-trace-collect.py`
keeps a whole session (the trace is a ring), flagging drops as they happen;
`tools/wk-echo-repro.py` sends a message repeatedly over TCP and checks each
echo — it keys the radio and needs the logger closed.

**`GET /api/flextrace` does the same for the radio link on the Flex
backend.** It holds the last 128 lines, millisecond-stamped: `>` is every
command the keyer sent (`xmit`, `cw key` with its `time`, `index` and
`client_handle`, `cwx …`), and `<` is the radio's replies, messages and
interlock/cwx/client statuses. A reply other than `0` or `50001000` means
the radio refused the command. Every `cwx clear` is preceded by a `#` line
naming what asked for it (`web STOP`, `paddle break-in (dit|dah|element)`,
`host 0x0A clear buffer`, `Bluetooth keyboard Esc`, or one of the keyer's own
backstops), so a message cut short can be traced to its cause. `?clear=1`
empties it. Read it when the radio
keys up but sends nothing: that traffic goes over WiFi straight to the
radio, where no other machine can watch it.

## MQTT

- Broker: `MQTT_HOST` in `secrets.h` (`config.h` default `192.168.1.10` is a
  placeholder); auth required — role account in `secrets.h`. The account
  needs **write** on `shack/esp32-vukeyer/#`, or the broker accepts the
  login and silently drops every publish.
- A broker that is down or unreachable costs nothing: the connect is capped
  at 500 ms and never attempted while CW or PTT is active.
- Status: `shack/vukeyer/status` (retained; LWT `{"event":"offline"}`),
  heartbeat carries WPM, busy, backend, host/TCP/Flex connection state.

## Layout

```
platformio.ini        env:esp32-vukeyer (esp32dev) + env:esp32s3-vukeyer
include/config.h       broker, topics, ports, AP name (+ git-ignored secrets.h)
include/pins.h         GPIO map (I²C + OTRSP pins reserved)
src/keyer.cpp          iambic keyer engine (1 kHz task, core 1)
src/hostlink.cpp       K1EL WinKeyer protocol engine
src/flex.cpp           FlexRadio discovery + SmartSDR command API
src/net.cpp            WinKeyer-over-TCP server + mDNS
src/settings.cpp       validation + NVS, shared by the CLI and the web page
src/display.cpp        SH1106/SSD1306 status panel (own task, core 0)
src/web.cpp            settings web server (port 80)
src/main.cpp           wiring, WiFi, MQTT, serial CLI
src/bt.cpp             BLE keyboard host (off by default; S3 build = stubs)
src/probes/ble_kbd_probe.cpp  standalone BLE keyboard test (env ble-kbd-probe)
tools/wk-bridge.py     TCP → PTY bridge for logging software
tools/wk-test.py       protocol test harness
tools/wk-timing.py     timestamped status — "not sent" vs "reported late"
tools/flex-check.py    Flex prerequisite diagnostic + keying test
tools/web-preview.py   serve the settings page locally, before flashing
tools/flex-ptt-watch.py  keyer state + radio interlock/cwx, one timeline
tools/boot-listen.py   count ROM resets on the serial port (needs pyserial)
enclosure/             3D-printable case: OpenSCAD source, STLs, fit checks
flash.sh / monitor.sh  serial-port pickers (never pin the port)
install.py             toolchain bootstrap, macOS/Pi branch
```

See `HANDOVER.md` for design decisions and open items.

## Licence

MIT — see [LICENSE](LICENSE). Use it, change it, build one; just keep the
copyright notice.

The WinKeyer protocol is Steve K1EL's, and the K3ng CW keyer by Anthony
Good K3NG was used as a behavioural reference. The implementation here is
original and carries no upstream licence obligations.

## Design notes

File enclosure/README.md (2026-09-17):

# Enclosure — 3D-printable case

A two-part FDM case for the keyer: **tray** (floor + walls) and **lid**,
both printable without supports. Parametric OpenSCAD source in
[`vukeyer-case.scad`](vukeyer-case.scad); STLs in [`stl/`](stl/).

Outside about **145 × 89 × 45 mm**.

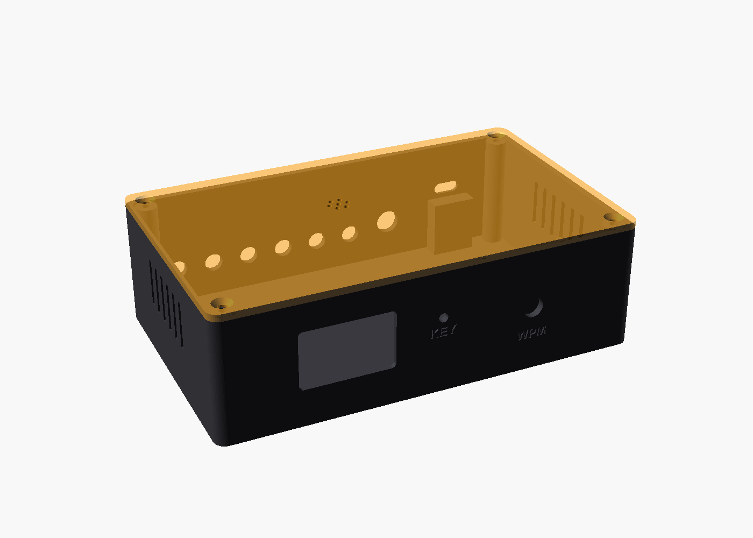
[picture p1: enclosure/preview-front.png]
Front: OLED window, key LED, speed pot

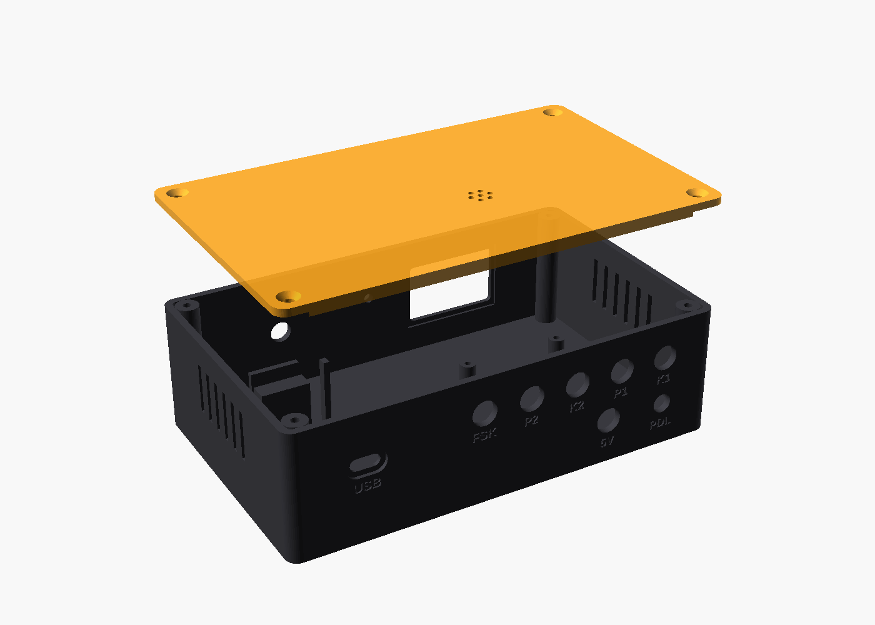
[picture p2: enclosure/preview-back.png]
Back, lid lifted: RCA row K1 P1 K2 P2 FSK, paddle and 5 V below, USB-C


| Panel | What is on it |
|---|---|
| Front | 1.3" OLED window, speed pot (engraved WPM), 3 mm key LED (KEY) |
| Back | upper row: 5 × RCA — K1, P1, K2, P2, FSK; lower row: PDL (3.5 mm stereo), 5 V DC; USB-C |
| Lid | sound holes over the piezo, which clips into a ring underneath |
| Sides | vent slots near the top |
| Inside | 30 × 40 mm opto perfboard on four posts, back-left, behind the RCA sockets |

## Measure before you print

Every part dimension is a named parameter at the top of the `.scad` file,
and the ones below vary between vendors — a jack hole 0.5 mm off wastes the
print. **For VU2CPL's build all of them were measured or confirmed on
2026-09-13** (marked below); if your parts differ, measure yours and re-run
the fit checks:

| Parameter | Default | Part |
|---|---|---|
| `jack_hole` | 6.3 mm | paddle 3.5 mm jack thread — **measured 6 mm** |
| `rca_hole` | 8.3 mm | RCA socket thread (KEY/PTT/FSK) — **measured 8 mm** |
| `dc_hole` | 8.3 mm | DC jack thread — **measured 8 mm** |
| `pot_hole` | 7.0 mm | pot bushing — **measured 6.7 mm** |
| `pot_tab_dz` | 8.0 mm | pot anti-rotation tab from the shaft — **measured ~8 mm**; recess is 3.6 mm so ±0.5 mm still seats |
| `oled_pcb_w/h` | 35 × 33 mm | OLED board — **measured** |
| `oled_glass_w/h` | 34 × 23 mm | OLED glass — **measured**; sits in a 0.8 mm pocket that lines the window up |
| `oled_win_w/h` | 32 × 20 mm | OLED window — **chosen** against that glass |
| `oled_hole_dx/dz` | 30.4 × 28.4 mm | only if you turn `oled_posts` on — not measured |
| `kit_l`, `kit_w`, `usb_dz` | 55.3 × 28.3, 1.6 mm | devkit PCB, USB-C centre above the PCB — **confirmed** |
| `piezo_d` | 12.4 mm | passive piezo body — **measured 12 mm** |

A quick check before the full print: set `part="tray"`, add a
`projection(cut=true)` or just print the back wall alone at 100% as a thin
test strip, and try the jacks and USB plug in it.

## Print

- PETG or PLA, 0.2 mm layers, 3 perimeters, 20% infill.
- **Tray**: open side up. **Lid**: outside face down (the STL is already
  oriented that way).
- No supports. The OLED window's top edge is a 30 mm bridge; the round
  holes in the walls are small enough to print without teardrops.

```bash
cd enclosure
openscad -o stl/tray.stl -D 'part="tray"' --backend Manifold vukeyer-case.scad
openscad -o stl/lid.stl  -D 'part="lid"'  --backend Manifold vukeyer-case.scad
```

## Fit checks — run these after changing any dimension

The `.scad` carries stand-ins for the real parts (devkit with its pin rows
and Dupont leads, OLED glass/PCB/header, pot, the paddle jack, RCA sockets and DC jack with
their nuts, the opto board, piezo). Three modes intersect them, and **each must render
empty** — OpenSCAD prints `Current top level object is empty.`:

```bash
for c in check_tray_lid check_parts_tray check_parts_lid; do
  openscad -o /tmp/$c.stl -D "part=\"$c\"" --backend Manifold vukeyer-case.scad 2>&1 | grep -E "empty|Vertices"
done
```

A `Vertices:` line instead means a collision. `part="ghost"` renders the
tray see-through with the stand-ins in green to find it. The first draft
failed all three: the paddle jack ran into a corner boss, the devkit's
corner into another, and the lid lip into the tray's rounded inside
corners — which is why the box is 140 mm inside rather than 130.

The stand-ins use typical part sizes. They catch layout mistakes; they do
not replace measuring your own parts.

## Hardware

- 4 × M3 × 10 countersunk screws. Default bosses (`boss_hole = 2.6`) take
  self-tapping M3 straight into the plastic; for repeated opening set
  `boss_hole = 4.0` and fit M3 heat-set inserts.
- 4 × 10 mm rubber feet (recesses on the underside).
- A small square of foam tape on the lid's hold-down post.
- 5 × panel RCA sockets (8 mm thread) for K1, P1, K2, P2, FSK; 1 × 3.5 mm
  stereo panel jack for the paddle; a 5.5/2.1 mm panel DC jack; a 3 mm LED
  + 330 Ω.
- 30 × 40 mm perfboard, 5 × PC817, 5 × 330 Ω, 4 × M2.5 × 6 self-tapping
  screws. Drill the board's corners 2.5 mm in from each edge to meet the
  posts. **Alternative:** 1 × LTV847 (quad) + 1 × LTV817 with 5 × 220 Ω —
  same circuit, two chips instead of five, more drive. See the opto board
  note under Assembly notes.

## Assembly notes

- **The devkit rests on two shelves under its short ends**, 20 mm off the
  floor so Dupont leads on the header pins fit underneath. The pin rows run
  along the long edges, which are left clear. It is held by its USB-C port
  in the back wall, fences at the antenna end, and the lid's post pressing
  on the WROOM shield through the foam. Lower it in, then slide it back so
  the USB-C shell enters the wall.
- **OLED**: drop the glass into its pocket on the inside of the front wall —
  that lines the window up — and hold the PCB with a few dots of hot glue
  on its edges (keep glue off the glass). The mounting posts are off
  (`oled_posts = false`): the hole spacing was never measured, and with
  23 mm glass their shoulders crowd it.
- **Opto board** (back-left, four posts): one PC817 per RCA socket.
  GPIO → 330 Ω → PC817 pin 1 (anode); pin 2 (cathode) → keyer GND; pin 4
  (collector) → RCA centre; pin 3 (emitter) → RCA shell. Keep every RCA
  shell off the keyer's ground — that isolation is the reason for the opto.
  GPIOs: K1 33, P1 32, K2 18, P2 19, FSK 27.
- **Opto board, LTV847 option** (undecided as of 2026-09-16; either build
  works). One **LTV847** quad optocoupler carries K1/P1/K2/P2 and one
  **LTV817** carries FSK — two chips instead of five, and with **220 Ω**
  input resistors about 9 mA per LED (≥4.5 mA out at the worst-case 50 %
  CTR, typically far more) against ~3 mA from PC817 + 330 Ω. Circuit is
  otherwise identical: GPIO → 220 Ω → anode, cathode → keyer GND, collector
  → RCA centre, emitter → that socket's shell, every shell still off keyer
  ground. LTV847 is a 16-pin DIP (~20 × 7.6 mm); channels 3 and 4 are
  mirrored, so check the pins:

  | Line | GPIO | 220 Ω → anode | Cathode → GND | Collector → RCA centre | Emitter → RCA shell |
  |---|---|---|---|---|---|
  | K1 | 33 | 1 | 2 | 4 | 3 |
  | P1 | 32 | 5 | 6 | 8 | 7 |
  | K2 | 18 | 12 | 11 | 9 | 10 |
  | P2 | 19 | 16 | 15 | 13 | 14 |
  | FSK | 27 | LTV817 1 | LTV817 2 | LTV817 4 | LTV817 3 |

  PC847 or EL847 substitute for the LTV847 pin for pin; confirm against the
  datasheet of the part that actually arrives before soldering. Ready-made
  opto modules (7Semi/SmartElex ILD213T breakouts, HW-399 TLP281-4, the
  generic green 4-channel PC817 boards) were all rejected: each buffers its
  outputs and needs a supply on the rig side (HV/HVCC), so no channel is the
  plain switch-to-ground a rig's KEY line wants.
- **Key LED**: 3 mm LED + 330 Ω from GPIO2 to GND, in parallel with the
  onboard LED. GPIO2 is a strapping pin, but an LED to GND keeps it low at
  boot, which is the state it needs.
- **DC jack: 5 V only**, into the devkit's 5V/VIN pin. The devkit's
  regulator runs hot well before 12 V, and the schematic notes a
  470–1000 µF capacitor at the board if it browns out on keying.
- The antenna end faces the front. Keep the jacks' metal and wiring from
  bunching over the WROOM antenna.

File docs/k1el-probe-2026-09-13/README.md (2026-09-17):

# Genuine K1EL WinKeyer probe — 2026-09-13

Device: K1EL WKUSB-type keyer, FT232R `usbserial-AI02BVHE`, 1200 8N2.
Admin host open returns **31 (0x1F) = WK3.1**. Reference: K1EL "WinKeyer3 IC
Interface & Operation Manual" Rev 1.3 (3/19/2019). Raw logs and the scripts that produced them: `k1el-probe1..6.{log,py}`
(probe 5 had Manoj on the pot and paddle).
The WinKeyer protocol and datasheet are Steve K1EL's; the datasheet is not
redistributed here — fetch it from k1elsystems.com (`WK3_Datasheet_v1.3.pdf`).
Every item below was measured on the hardware AND agrees with the datasheet
unless marked otherwise.

## Firmware defects found (src/hostlink.cpp)

1. **Status flags are all one bit too high** (`ST_*`, lines 33-37).
   Real: XOFF 0x01, BREAKIN 0x02, BUSY 0x04, KEYDOWN 0x08 (WK1 mode; in WK2
   mode bit 3 = pushbutton tag), WAIT 0x10. Ours: 0x02/0x04/0x08/0x10/0x20.
   Our WAIT gives 0xE0, not a status byte at all. A logger reads our BUSY as
   KEYDOWN/pushbutton and our BREAKIN as BUSY. `tools/wk-test.py` decode()
   carries the same wrong map, which is why self-tests passed.
2. **0x0F load-defaults field order wrong from byte 3.** Datasheet Table 13:
   mode, speed, sidetone, weight, lead, tail, minWPM, WPMrange, X2MODE,
   keycomp, farnsworth, paddle setpoint, ratio, pincfg, X1MODE.
   Ours: mode, speed, setpoint, potmin, range, farns, weight, lead, tail, -,
   ratio, comp, firstext — so the pot range is taken from weight/lead-in.
   (No hardware round-trip possible: admin 7 is unsupported in WK3.)
3. **Pot byte scaled wrong.** Real = WPM − MINWPM, unscaled (min 10 / range
   30 swept 0..30). Ours = (wpm−min)·31/range. Real sends one unsolicited
   byte per step.
4. **Admin parameter counts desync the parser** (`adminParams`). *Missed
   here and found on air the next morning:* 0x00 Calibrate takes 1 byte
   (`<00><00><nn>`); counted as 0 it turned RUMlogNG's `00 00 02 00 0B 00 0F
   00 01 08 …` into speed 0 plus a bogus 0x0F load-defaults, setting the pot
   range to 71..80 and the keyer to 60 WPM. Not probed on the K1EL — the
   framing of RUMlogNG's own setup is the evidence. 0x0D load
   EEPROM takes 256 bytes (ours 15); 0x13 set RTTY registers takes 2 (ours
   0, treated as mode select); 0x14 is Set WK3 Mode, 0 params (ours 1, as
   sidetone volume); 0x16 load X2MODE takes 1 (ours 0); 0x19 sidetone volume
   takes 1. Datasheet text for 25 says `<00><24><n>` — ambiguous, verify.
5. **Admin replies missing/wrong:** 0x09 = Get FW major rev (ours "get
   calibration", emits 0); 0x15 Vcc, 0x17 FW minor, 0x18 IC type each return
   one byte (ours nothing). Measured: 0x09 → 31, 0x17 → 2 (fw 31.02),
   0x18 → 1 (SMT), 0x15 → 62 (26214/62 = 4.22 V); echo test after each
   stayed in sync. Admin 7 Get Values: WK3 datasheet says "always
   returns 0"; this unit returned **nothing** (5 s, open and closed). Ours
   returns 15 bytes — correct for the WK2 we claim to be.
6. **Pause does not set WAIT** on the real keyer (status stayed 0xC4).
   Ours sets WAIT while paused. Real pause finishes the current character;
   Clear Buffer cancels pause (measured: text sent after 0x0A went out with
   pause never lifted). Ours does not clear `paused` on 0x0A.
7. **BREAKIN is a level, not a pulse.** Real: set at the first paddle
   element (0xC6) and held until paddle hang ends (word space after the last
   paddled letter, whose echo is a space sent with BREAKIN still high), then
   0xC4 → 0xC0 within ~16 ms. Ours (`Keyer::paddleBreakIn()`) is sticky-
   until-read, so the host sees it for one status byte only.
8. **Break-in discards serial text** — the buffer is cleared at break-in and
   text arriving while paddling is ignored (only immediate commands are
   processed). Measured twice (TEST sent at 126.1 s and 192.7 s, never
   echoed). Datasheet p.4 "Paddle Input Priority".
9. **XOFF threshold** = buffer > 2/3 full of a 160-character buffer
   (datasheet p.1), i.e. ~107; measured at ~120-128 queued with a few
   already sent. Ours: > 480 of 512.

10. **No WK2 status mode.** Admin 11 (Set WK2 Mode) — accepted while the
   host is OPEN — answers at once with 0xC8 (a pushbutton status byte, none
   pressed). From then on bit 3 tags pushbutton bytes and KEYDOWN is no
   longer reported: key immediate gives 0xD0, 0xD4 instead of 0xD8, 0xDC.
   Host open always returns to WK1 mode. Ours ignores 0x0A/0x0B.
11. **KEYDOWN is tune only.** Sending text (PARIS, EEE, TEST at 12-20 WPM)
   produced BUSY and idle bytes only — never a KEYDOWN per element. KEYDOWN
   appeared solely for key immediate (0x0B). Ours reports every key
   transition (`Keyer::keyIsDown()`), roughly two status bytes per element on
   a 1200-baud link; `tools/wk-timing.py` treats one KEYDOWN per element as
   correct and needs the same correction.

12. **Nothing after the version byte.** Host open returns the version and
   no status or pot byte (probe 1: 1 s of silence). Ours followed the version
   with a forced status byte and, on the next poll, a pot byte.

## Behaviour confirmed (reference for 12a echo work)

- Host speed commands (0x02) do not produce a pot byte; pot bytes report the
  knob only, one per step, 0..WPMrange.

- Echo is sent after the letter has been completely sent (end of its last
  element), for serial and paddle alike. Source is told apart by BREAKIN.
- Status is sent unsolicited on every change (idle→BUSY on text arrival,
  BUSY→idle ~110 ms after the last echo at 20 WPM, lead/tail 0).
- Key immediate: 0xD8 then 0xDC (WAIT|KEYDOWN(|BUSY)), 0xC0 on release.
- Clear buffer: 0xC0 at once, then one late echo for the character that
  was in progress.
- PTT on (0x18) sets no status bit.
- Paddle break-in: 0xC6 (BUSY|BREAKIN); after release 0xC4 then 0xC0 at the
  end of the word space.
- 0x04 lead/tail units are 10 ms; tail delay = 3 dits + tail×10 ms.
- 0x09 PINCFG: bit0 PTT enable, bit1 sidetone enable, bit2 KeyOut2,
  bit3 KeyOut1; bits 7-6 ultimatic priority, 5-4 paddle hang time.
- 0x01 sidetone: WK2 = low-nibble N table (4000/N); WK3 mode = 62500/Hz.

## After the fixes — our keyer, same probes (2026-09-13, 01:15)

`run-tcp.py` replays each probe unchanged against our keyer over WinKeyer
TCP 8088; results in `ours-probe{1,2,3,4,6}.log` (backend **flex**, radio
into a dummy load). Probe 5 needs an operator on our pot and paddle and has
not been run yet.

**Now matching the K1EL:** status bit layout; nothing after the version
byte; KEYDOWN (with WAIT) for key immediate only, none for text; Set WK2
Mode answers 0xC8 and switches bit 3; host open returns to WK1 mode; admin
9/21/23/24 answer (23, 79, 0, 1) and an echo test after each stays in sync;
Clear Buffer cancels pause. Get Values now answers in load-defaults order
(ours reports WK2, which has the command; the WK3.1 does not).

**Still different — all on the Flex backend**, where text is handed to the
radio in batches rather than keyed here:

- Echo arrives in bursts, not at the end of each letter: PARIS E echoed as
  seven bytes at once; 150 bytes of TEST echoed in 1.5 s; EE echoed before
  BUSY rose. This is HANDOVER 12a's echo-pacing problem, now with a
  reference for correct behaviour.
- Pause does not hold: the text is already on the radio.
- XOFF never asserts: the buffer drains straight to the radio.
- Clear Buffer: 0xC0, then a spurious 0xC4 for ~1 s, then 0xC0. The K1EL
  sends 0xC0 once.
- Key immediate goes straight to 0xDC (K1EL: 0xD8 then 0xDC) — cosmetic.

## Round 2 — probe 5 on ours, Flex echo fixed, local backend compared

**Probe 5 on our keyer** (`ours-probe5.log`, Manoj on our pot and paddle;
radio view in `ours-probe5-flex-watch.log`): pot bytes one per step 0..29,
none for host speed commands; BREAKIN held as a level through each paddle
session, closing space echoed, then idle — as the K1EL. The watcher shows
break-in erasing the radio's remaining text (`cwx erase=6830,6833`).

**Flex echo pacing — fixed in `flex.cpp`** (`flex-probe{3,4,6}.log`, radio
view `flex-probe-watch.log`). Two causes:
1. The `cwx send` reply gives the index of the block's FIRST character and
   `cwx sent=` counts one per character (TEST -> 6799..6803), so pending
   must run to index + length - 1. Taking the bare index as the end released
   every echo the moment the reply landed.
2. After a clear, a late `erase`/`sent=` report leaves `sentIdx` at the
   radio's absolute index while `queuedIdx` restarted at 0, so the next send
   read as already sent. The provisional count now starts from `sentIdx`.
Replies to sends made before a `cwx clear` are ignored (matched by sequence
number), which removed the ~1 s BUSY after Clear Buffer and break-in.
Result: PARIS E echoed per letter (ours P 4.51, A 5.00, R 5.59, I 5.98;
K1EL 4.37, 4.85, 5.46, 5.81 — ours trails by the radio's ~150 ms start),
and EEE / MMMM / E after clears arrive paced with BUSY first.

**Local backend** (`local-probe{3,4,6}.log`, backend switched over HTTP and
restored): status, clear and XOFF correct (XOFF at our 2/3-of-512).

**Local echo — fixed** (logs above are after the fix). Echo used to be sent
when a character entered the keyer's 3-character look-ahead, i.e. before it
was keyed. The keyer now reports each buffered character as it FINISHES
(`Keyer::sentRead()`, a space when a word gap ends) and the engine echoes a
host character only then. PARIS E, local vs K1EL: P 4.31/4.37, A 4.79/4.85,
R 5.39/5.46, I 5.76/5.81, S 6.23/6.30, space 6.60/6.65, E 6.72/6.78 — within
~60 ms, which is the USB/TCP difference. `flex-probe3.log` re-run afterwards:
the Flex path is unaffected.

**Remaining differences:** pause on the local backend still lets the
characters already in the keyer's look-ahead go out (the K1EL finishes only
the current one); on Flex, pause cannot hold what the radio already has and
XOFF never asserts; key immediate goes straight to 0xDC. Pin configuration
was never observed on hardware.

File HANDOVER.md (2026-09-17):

# VUKEYER — Project Handover
*For continuation in a new Claude session*

**Created:** 2026-08-26 · **Updated:** 2026-09-17 · **Type:** ESP firmware
(esp32dev, S3 env reserved) · **Status:** working keyer, **public repo**
(MIT). RUMlogNG drives it over USB and keys the Flex; OLED/LCD panel,
speed pot, settings web page, memories, second radio and RTTY FSK all on
hardware.

**Read this first if you are picking the project up after 2026-09-12:**

- **RENAMED 2026-09-17 (22:20): ESP32 WinKeyer → VUKEYER.** WinKeyer is
  K1EL's product name, and the repo is public. What changed:
  - GitHub repo `vu2cpl/vukeyer` (old URL redirects); local folder
    `~/projects/esp32-vukeyer`.
  - mDNS `vukeyer.local` (service `_vukeyer._tcp`); setup AP
    `vu2cpl-vukeyer-setup`; MQTT client `esp32-vukeyer` and topic
    `shack/vukeyer/status` (MQTT is not in use).
  - PlatformIO envs `esp32-vukeyer` / `esp32s3-vukeyer`.
  - The protocol engine is `src/hostlink.cpp` / `include/hostlink.h`,
    namespace `HostLink`.
  - The enclosure is `enclosure/vukeyer-case.scad`. OLED/LCD titles and
    the web page say VUKEYER.
  - Diagnostics from this session are now in `tools/`: `wk-open-timing.py`,
    `wk-trace-view.py`, `flex-trace-record.py` and `cw-runs.py`. Pass the
    keyer as `KEYER=<ip>` (default `vukeyer.local`); no shack IPs are in
    the repo. README "Tools" explains them.
  - Unchanged on purpose: wording that describes the **K1EL WinKeyer
    protocol** (loggers still pick "WinKeyer"), the `WK_` constants, and
    the K1EL / K3NG credits.
  - History entries below keep the old names where they describe what
    happened then.
- **Web page merged into cards (22:20):** KEYER (with Timing, Speed pot and
  PTT sections), MEMORIES (with Send and, since 22:40, FSK / RTTY),
  BACKEND and SYSTEM (Display, USB / WIFI, BT keyboard). Two columns:
  KEYER | MEMORIES, then BACKEND | SYSTEM. Three: KEYER | MEMORIES |
  SYSTEM, then BACKEND. Sections use `.sub` headings, and the
  old legend ids `legPtt` / `legSerial` moved onto them. At 3 columns the
  grid uses `grid-auto-flow: row dense`. Manoj reviewed it in the preview
  at 1024 px; flashed.

- **FIXED 2026-09-17: on the Flex backend, CW went out at 0 W after a GUI
  client restarted or changed.** There were two faults: the keyer kept a stale
  GUI client handle, and `client bind` wedged the radio's CW generator. The
  keyer now follows the GUI client, and `flexbind` defaults to off. Verified
  on hardware with an AetherSDR restart and no command: paddle first, then a
  memory, both 4.47 W. Open item 13 has the full investigation; the method
  (`/api/flextrace` + a meter watcher, one variable per test) is worth
  reusing.
- **Still open from 2026-09-17:** (a) the radio's CW got stuck at 0 W once
  more at ~15:06 with the keyer unbound, trigger unknown (index, reboot,
  `time=` jump and a Maestro restart all ruled out by meter). Recovery: let
  a memory stall, let the backstop or STOP clear it, then replay. (b) One
  memory at 14:44 was cut 233 ms in by a keyer-sent `cwx clear`, not
  reproduced; every clear now names its cause in `/api/flextrace`. (c) The
  Maestro gives no sidetone for paddle keying (by Flex design); the only
  route left is wiring KEY out into the Maestro's key jack. **Never judge CW
  working or dead without `flex_meters_watch.py` running.**
- **Fixed 2026-09-17 evening:** the learned sidetone timing had crept to
  1168 µs at 25 WPM (real ~760) and drifted behind the radio. See What
  changed 19:00. **RUMlogNG: use keyer type K3NG.** With K1EL it takes 18 s
  to ~2 min to open a session (it floods admin-open); with K3NG it opens at
  once (What changed 20:00), **except the first open after a flash: reopen
  the port once** (What changed 21:20). WK set-speed 0 now follows the knob.
- **New 2026-09-17 evening:** practice mode (sidetone only, no TX, not
  saved), `/practice on|off` or the web checkbox. Verified on hardware.
- **New 2026-09-17:** the sent CW scrolls on the display's bottom band while
  sending. `flexbind` now defaults to off.

- **Arduino core 3.3.11 / IDF 5.5.5** via the pioarduino platform, and
  **PlatformIO must run on Python 3.10+** — the Mac's system one is 3.9 and
  cannot build this. `~/.pio-venv313` holds a suitable one; `flash.sh`,
  `monitor.sh` and `install.py` find it themselves.
- **Wiring as of 2026-09-13 (this supersedes the 2026-09-12 two-adapter
  setup described further down):** the keyer's **own USB-C** is back in use
  (`usbserial-0001`, CP2102) and carries RUMlogNG. The FTDI
  `usbserial-A9M9DV3R` has **RX only** — a read-only console for
  monitoring; its TX was removed, so it **cannot flash**. Flash on the USB-C:
  `pio run -e esp32-vukeyer -t upload --upload-port /dev/cu.usbserial-0001`
  (auto-reset works). The devkit's USB chip can still hold the ESP32 in
  reset when a logger drives RTS/DTR — watch for it.
- **Hardware on order (2026-09-16):** 2 × ESP32-S3 N16R8 dual-USB-C
  boards and 2 × LTV-847. Nothing in firmware or the enclosure changes until
  a board is on the bench and measured — see open items 7, 9 and 10.
- Outstanding: FSK polarity and on-air fist quality unverified; the LCD
  slice warning never seen on a panel; the board mod that would end the
  reset problem for good is not done.
- **BLE keyboard: in the firmware, off by default, PARKED (2026-09-13
  evening)** — it does not fit a classic ESP32's heap with the full keyer
  (~26 KB left → no WiFi). A boot guard turns it back off automatically.
  Open item 9 has the routes forward (S3/NimBLE, PSRAM). If the console
  says `=== BLE keyboard probe`, the board is running the standalone probe:
  `./flash.sh` puts the keyer back.

---

## What this is

A WinKeyer-compatible CW keyer on ESP32, reachable over WiFi, with an
optional FlexRadio backend. WinKeyer protocol by Steve K1EL; K3ng keyer
(Anthony Good K3NG) used as a behavioural reference — implementation is
original.

**Hardware (decided 2026-08-26):** bench and likely final board is a classic
**ESP32-D0WD-V3** devkit behind a CP2102 (`env:esp32-vukeyer`, board
`esp32dev`) — dual core, WiFi + BT Classic. An **ESP32-S3** env
(`env:esp32s3-vukeyer`) is the upgrade path: native USB CDC with a custom
descriptor would fix the CP2102 `usbserial-0001` port-identity problem for
wired use. A friend of Manoj's is building one too, on a 38-pin DevKitC
clone — same chip family, same firmware, no changes needed.

**Why WiFi is the primary link:** every CW element is timed on the keyer
(or, in Flex mode, on the radio), so the network only carries text and
status. Link latency never reaches the air. The one exception is
real-time paddle keying over the network, which is deliberately not
implemented — see "Flex backend" below.

## Pin map (`include/pins.h`)

| Signal | GPIO | Notes |
|---|---|---|
| Paddle dit (tip) | 25 | INPUT_PULLUP, closes to GND |
| Paddle dah (ring) | 26 | INPUT_PULLUP, closes to GND |
| Key out | 33 | active high → opto (PC817 + 330 Ω, or LTV847 + 220 Ω) or NPN |
| PTT out | 32 | active high → opto (PC817 + 330 Ω, or LTV847 + 220 Ω) or NPN |
| Sidetone | 4 | LEDC PWM → passive piezo |
| Speed pot | 34 | ADC1_CH6 (input-only) — 10 k linear + 100 nF wiper→GND; **off until `/pot on`** (now persisted), pin floats otherwise |
| Display SDA / SCL | 21 / 22 | OLED (SH1106/SSD1306 0x3C-0x3D) or HD44780 LCD backpack (16x2/20x4, 0x27-0x3F); family auto-detected |
| Status LED | 2 | onboard — lit while the key is down |
| KEY / PTT out 2 | 18 / 19 | radio 2; `/radio 1\|2\|both` |
| FSK out | 27 | RTTY keying line, mark = idle, invertible |

**The OTRSP reservation is gone (2026-09-11).** Manoj: *"there is no plan
for so2r or otrsp"*. Six pins — 16, 17, 27, 14, 13, 5 — had been held
since the scaffold for a phase that was never going to start, and by the
time FSK, a second KEY/PTT pair and buttons were all wanted, that
reservation was the thing forcing real features onto a resistor ladder.
SO2R lives in `~/projects/SO2R box` as separate hardware.

Free now: **13, 14, 16, 17, 18, 19, 23**, plus 35/36/39 input-only (no
internal pull-ups there — a button needs an external one). Avoid 5, 12
and 15: strapping pins, pulsed at boot. 6-11 are the SPI flash.

Earlier in the same session `pins.h` was also found carrying a *stale*
reservation comment claiming 18/19/21/22/23, contradicting a 2026-09-10
revision that had moved OTRSP off the I²C pins for the display. Both are
now moot.

## Architecture

Seven modules, each transport- or backend-agnostic so they compose:

- **`src/keyer.cpp`** — 1 kHz FreeRTOS task, core 1, priority 10 (above
  loopTask; WiFi/BT live on core 0), so element timing is jitter-free
  regardless of network activity. Iambic A/B with Curtis semantics (both
  modes latch the opposite paddle during an element, B also during the
  space), squeeze alternation, 3 ms debounce, PARIS timing. Also:
  weighting, dit/dah ratio, Farnsworth, PTT lead/tail sequencing, tune,
  manual PTT hold, prosign merge (suppresses the inter-character gap),
  paddle break-in, 256-char queue, speed pot with WinKeyer override
  semantics (host speed rules until the pot moves).
- **`src/hostlink.cpp`** — K1EL host protocol, reports **version 23
  (WK 2.3)**. Every logger supports WK2; claiming WK3 buys nothing and
  narrows compatibility. Implements the command set loggers actually use;
  unknown commands still have their parameters consumed from a table, so
  an unrecognised command can never desync the stream. Emits unsolicited
  status (0xC0|flags) and pot (0x80|value) bytes on change.
- **`src/net.cpp`** — WinKeyer byte stream over TCP 8088, mDNS
  `vukeyer.local` (`_vukeyer._tcp`). One client at a time; a new
  connection displaces the old one and resets the host session.
- **`src/flex.cpp`** — FlexRadio discovery + SmartSDR command API.
- **`src/settings.cpp`** — validation + NVS (namespace `wk`), the single
  place that knows what a setting is called, what range it takes, and
  whether it persists. The CLI and the web page both call
  `Settings::apply()`, so they cannot drift apart. `applyBackend()` moved
  here from `main.cpp` because backend selection has three coupled side
  effects and every caller was at risk of doing two of them.
- **`src/display.cpp`** — optional SH1106/SSD1306 128x64 panel, rendered
  at 5 Hz from its own task at priority 1 on **core 0**. An I²C frame
  blocks ~25 ms, which must not sit in front of the keyer task (element
  timing) or `loop()` (the host link), so it gets neither.
- **`src/web.cpp`** — settings page + JSON API on port 80, serviced from
  `loop()`. Listening is deferred to `poll()` because WiFiManager is
  non-blocking and there is usually no IP at `setup()` time — same
  lazy-start pattern `net.cpp` already uses for mDNS.

Serial (115200) is a text CLI that **auto-switches** to the WinKeyer
binary protocol when a host-open arrives (0x00 is never valid CLI input)
and back to the CLI on host close.

## Flex backend

- Command API **TCP 4992**, line oriented: send `C<seq>|<cmd>`, receive
  `R<seq>|<hex>|<msg>` replies and `S<handle>|...` status.
- Discovery: firmware > v1.1.3 sends VITA-49 on **UDP 4991**, older sends
  a proprietary format on **UDP 4992**. Both carry the same ASCII
  `key=value` payload, so we listen on both and scan for fields rather
  than parsing two header formats.
- Keying is `cwx send <text>`; **a literal space does not survive the
  command parser — send ASCII 0x7F and the radio translates it back.**
  Also used: `cwx clear`, `cwx wpm <n>`. Subscribe with `sub cwx all`;
  progress arrives as `S<handle>|cwx sent=<index>`.
- In Flex mode the local key output is disabled (`Keyer::setKeyOutEnabled`)
  so the rig is not keyed twice; sidetone stays local. Slice must be in CW.
- **Deliberately not implemented:** real-time paddle keying over the
  network — element timing sent packet-by-packet inherits WiFi jitter.
  Paddles stay on the local key output.
- **Worth knowing:** SmartSDR CAT already provides a WinKeyer-emulation
  COM port, and N1MM+ uses that rather than CWX. So for a Flex owner this
  keyer's value is real paddles with local element generation, not
  replacing the built-in emulation. Prior art: the WKFlex community
  project.

### The radio in this shack (found 2026-09-10)

**Flex 6600 "6600", callsign VU2CPL, 192.168.1.50, SmartSDR API
1.4.0.0.** Connection and `sub cwx all` verified from the keyer.

#### On-air test 2026-09-10 (dummy load): blocked on the radio, twice

Keying could not be proven. Both blockers are on the radio side — the
keyer's commands reach it and are accepted at the protocol level.

1. **The slice must be in CW mode.** Slice A was `mode=LSB` on
   7.146 MHz. CWX cannot key CW on a non-CW slice: the command is
   accepted, nothing is transmitted, and no `cwx sent=` ever arrives.
   `slice set 0 mode=CW` works and was verified; the slice was restored
   to LSB afterwards.
2. **Something else holds the CW/CWX transmit path.** With the slice in
   CW, `cwx send` is still refused:

       R3|500000C2|Cannot transmit since another client is transmitting
                   or sending a CW/CWX message

   This happens from a **direct session on the Mac too**, not just from
   the keyer, so it is not the keyer's doing — and `interlock
   state=READY tx_allowed=1` at the same time, so the radio itself is
   not inhibited. Clearing the keyer's own CWX buffer did not help, so
   it is not a stale buffer from the failed first attempt.

   **Who was holding it:** SmartSDR on the PC was one client; closing it
   was not enough, because a second client stayed connected — handle
   `0x68A1B220`, `local_ptt=1`, owning a slice on **28.074 MHz DIGU with
   `tx=1`**. That is FT8 on 10 m (WSJT-X / MSHV / JTDX). Whatever owns
   the transmit slice owns the CW path, and CWX cannot have it.

   **Practical consequence for real operating:** this keyer's Flex
   backend cannot key while another client holds TX. That is a genuine
   constraint on the design, not a bug to fix — worth weighing against
   simply wiring the local key output to the radio's KEY jack, which has
   none of this contention and none of the latency.

#### RESOLVED 2026-09-10: paddle keying over the network works

**The keyer keys the radio over WiFi with no KEY or PTT wire.** This is
the headline feature and it is verified on the dummy load: the radio goes
`READY → PTT_REQUESTED → TRANSMITTING` under keyer control and releases
cleanly. Everything in the CWX section below is superseded — CWX was
never the right mechanism.

**How it works** (`pumpKeying()` in `src/flex.cpp`):

1. `xmit 1` on the first element. A bare keying command does nothing,
   because the radio only keys for whichever client holds the
   transmitter, and `interlock.tx_client_handle` stays `0x00000000`
   until one asks.
2. Per element:

       cw key <1|0> time=0x<16-bit ms> index=<decimal> client_handle=<GUI handle>

   `time` is milliseconds as **16-bit** hex (rolls at 0xFFFF), `index` a
   decimal counter, and `client_handle` the **GUI client's** handle — the
   keying happens in that client's transmit context. The timestamps let
   the radio schedule the edge rather than key on arrival, which is what
   keeps CW readable over a jittery link. Same mechanism as Maestro and
   MORCONI.
3. `xmit 0` after a 400 ms tail — suppressed while the key is down, or a
   long element (or tune) drops PTT out from under itself.

**Prerequisites, all of which fail silently:**

- **A slice must be in use AND in CW mode.** With no slice the radio
  transmits nothing and reports *no error at all*. This was the final
  blocker and cost hours. The keyer now subscribes to slice status and
  warns; `/status` shows readiness.
- SmartSDR (a GUI client) must be connected — with none, the radio
  reports `tx_allowed=0` and nothing may transmit.

**`cw key` vs `cw ptt`:** FlexRadio's wiki documents `cw ptt [1|0] time=
index=` as the keying command, and the radio accepts it without error —
but it did **not** produce RF here. Only `cw key` did (6600, SmartSDR
4.2.20). Both are switchable with `/flex cmd key|ptt`; `/flex bind` and
`/flex ptt` toggle the other two variables. Those switches exist because
only a power meter can settle which combination keys, and reflashing per
guess is what made this slow.

Sidetone stays local and is generated from the operator's own paddle
timing, so the fist sounds right in the ear regardless of the link.

The keyer task must never block on the network, so `Flex::keyEvent()`
only enqueues (`xQueueSend`, zero tick) and `poll()` does the socket
write.

**Three traps, all of which cost hours:**

- **`0x50001000` is not an error.** Per FlexRadio it means the command
  ran but the handler did not set a result, so the processor substitutes
  that code. Treating it as a failure made `cw key` look unsupported when
  it had worked from the first probe. **Check this before concluding any
  Flex command is unavailable.**
- **`xQueueSendFromISR` from the keyer task is wrong** — it is a task,
  not an ISR. Events silently never reached the socket.
- **`backend` is not the same as `flex enabled`.** The backend selects
  where keying goes and now persists in NVS (`wk`/`flexbe`); before that
  it silently reverted to local on every flash, which repeatedly made a
  working build look broken.
- **No slice in use = no RF, no error.** Check `/status` first when
  keying does nothing. Also check that a log line reports what was
  actually sent: the keying log printed `cw key` regardless of the verb
  in use for a while, which hid the one distinction that mattered.
- **Only a power meter can confirm keying.** Interlock state moves for
  PTT but is not proof of a carrier, and there is no RF reading over the
  TCP API. Every "is it working" question in this session needed the
  operator. Build the runtime toggles first next time.

#### Superseded: earlier verdict on CWX as a second client

Every configuration was tried on 2026-09-10, into a dummy load, and
`cwx send` was refused with `500000C2` in all of them:

| Configuration | Result |
|---|---|
| SmartSDR open, keyer unbound | `500000C2` refused |
| SmartSDR open, **bound to the GUI client**, slice in CW, `tx_allowed=1` | `500000C2` refused |
| Everything closed, fresh CW slice created by us | `tx_allowed=0` — nothing may transmit |
| Direct session from the Mac (keyer uninvolved) | `500000C2` refused |

At the point of refusal the radio also reported
`tx_client_handle=0x00000000` — nobody held the transmitter — so the
error text is not describing the actual state.

**Conclusion: CWX behaves as exclusively owned by the GUI client.** With
SmartSDR running it holds CWX; with SmartSDR closed there is no transmit
context at all. Binding (`client bind client_id=…`) is implemented and
demonstrably works — the keyer logs the bind and the radio accepts it —
but it does not unlock CWX. This matches community reports of CWX
conflicting with third-party programs.

This is a limitation of the approach, not a defect in the keyer: every
layer the keyer owns is verified working, and the refusal is identical
when the keyer is taken out of the loop entirely.

CWX remains unavailable to a second client, and that is fine — it is the
wrong mechanism for a keyer. It sends *text* for the radio to key itself,
which cannot carry a fist. Direct `cw key` keying (above) is the right
answer and works. CWX would only matter if buffered text from a logger
should be keyed by the radio rather than by us; the local keyer handles
that case already.

Wiring GPIO 33 to the KEY jack also still works and remains the
lowest-latency option, but it is no longer necessary.

#### Gotcha: slice indices are not stable

`slice set 0 …` failed with `5000000D` after SmartSDR closed, because
**slice 0 no longer existed** — the remaining client's slice was index 1.
Slices belong to clients and come and go with them. Never assume slice 0;
read `sub slice all` and use whatever index reports `in_use=1`.

Also learned: `sub interlock all` is rejected with `500000A3 Invalid
subscription object name` — interlock status arrives unsolicited anyway,
so do not subscribe to it.

- **Discovery does not reach it.** The radio is on the 192.168.1.x
  segment, the keyer is on 192.168.10.x, and discovery is a raw UDP
  broadcast. It will never be auto-found from where the keyer sits — set
  it explicitly: `/flex ip 192.168.1.50`, or use **Find radio** on the
  web page (added 2026-09-11), which TCP-scans a /24 from the keyer
  itself. The setting persists in NVS and reconnects across reboots.
- **`client program <name>` is rejected** by 1.4.0.0 with error
  `10000002 unknown client program`. Removed — the subscription is what
  matters and it succeeds.
- Finding it: nothing broadcast, so the radio was located by TCP-scanning
  the shack subnets for port 4992. A Flex answers immediately with
  `V<version>` / `H<handle>`, which makes it unmistakable. That manual
  scan is now built in (Find radio, `Flex::scanStart()`).
- **Not yet tested: actually sending CW.** `cwx send` keys the
  transmitter and puts a signal on the air under Manoj's callsign, so
  that test needs him present and the radio set up deliberately (dummy
  load or a clear frequency). Requires `/backend flex`.

## Testing

`tools/wk-test.py` acts as a WinKeyer host over TCP or serial;
`tools/wk-bridge.py` creates a PTY (default `/tmp/vukeyer`) bridged to
the keyer's TCP port so logging software sees a serial device.

**`tools/flex-check.py` — run this first when the Flex will not key.**
It reports every silent prerequisite in one pass (slice in use, slice
mode, GUI client, interlock, break-in) and with `--key` drives a keying
test and watches interlock for proof of transmission. Written after a
session lost hours to "no slice in use", which the radio never mentions.

**`tools/flex-ptt-watch.py` — use it for any stuck or late PTT report.**
It polls the keyer's `/api/state` at 5 Hz and holds a read-only API
session on the radio (subscriptions only — it cannot key), printing both
on one clock: `busy`/`key`/`ptton`/`xmit` changes against interlock state
and `cwx sent=` progress. It is what showed, 2026-09-11, that the radio
unkeys 0.67 s after its last character on every memory (its own CWX
break-in delay). A run of `err TimeoutError` on the KEYER side is loop()
stalling, not the network.

**`tools/ptt-check.py`** drives the keyer through its own API on the local
backend and polls `/api/state` at 10 Hz: the lead-in over after a long
idle, a message stopped mid-flight, tune stopped, a memory reporting itself
in `memplay`. Every one of those was a fault that looked like "the LED
flickered" or "the STOP worked" from outside (items 12c, 12d). No paddle,
no logger, no radio; it restores the backend it found, but it does key
GPIO33/32.

**`tools/host-watch.py`** prints every setting a host can reach as it
changes, including `pincfg` and `hostdef` — the raw bytes of the two
commands whose bit layout is not obvious from outside. It is what found
that RUMlogNG zeroes PTT timing and the pin configuration at session open
(12e, 12f). **Close and RE-OPEN the session** when using it: that is when a
logger sends its defaults, and a mid-session toggle can send nothing at all.

**`GET /api/wktrace`** (2026-09-13) is the host wire: last 1024 bytes both
ways, ms-stamped, `?clear=1` to reset. **`tools/wk-trace-check.py`** parses
it as WinKeyer commands and lists text the host sent that never came back as
echo. **`tools/wk-trace-collect.py`** polls it every 3 s for a whole session
and writes `drop-N.txt` when an echo goes missing (read-only, runs beside
RUMlogNG). **`tools/wk-echo-repro.py`** replays a message over TCP and checks
every echo (keys the radio; close the logger).

**`GET /api/flextrace`** (2026-09-17) is the radio wire: the last 128 lines,
ms-stamped. `>` lines are every command the keyer sends (`xmit`, `cw key`
with `time`/`index`/`client_handle`, `cwx …`, `sub …`). `<` lines are the
radio's replies (`R<seq>|<code>|`, so a refused command is visible), its
messages, and its interlock, cwx and client statuses. Slice statuses are
left out because they flood the ring when the radio is tuned. Lines are
cut at 119 characters, so the end of a long interlock status is lost.
`?clear=1` empties it. It is streamed in 1 KB chunks. Since 14:55 each
`cwx clear` is preceded by a `# clear: <cause>` line. This is the only way
to see the keyer↔radio traffic: the Mac cannot sniff it (item 13), and the
console is muted during a logger session.

**`tools/uptime-watch.py`** polls `/api/state` and prints only events —
restarts (with the reset reason), outages and their length, stalls. "The
board died" is useless; "uptime 225 -> 2 at 12:31:35, reason PANIC" is not.

**`tools/console-capture.py`** timestamps the console to a file WITHOUT
touching DTR/RTS, so opening the port does not reset the board — and holds
it through a reproduction attempt, which is how the lwIP backtrace was
caught. Decode with `xtensa-esp32-elf-addr2line -pfiaC -e …/firmware.elf`.

**`tools/boot-listen.py`** counts `rst:` lines at 115200 without driving
DTR/RTS. Repeating `POWERON_RESET` points at the supply; repeating
`SW_RESET` with no app output points at stale flash — **erase and reflash
before retiring the board**. Needs pyserial (not in PlatformIO's penv).

**`tools/wk-timing.py`** timestamps each status byte and counts KEYDOWN
against the text's real element count. Fixed drain windows produce false
negatives when a delayed burst lands outside its window — this was
mistaken once for "only one element was keyed" when the CW was correct.

**Verified on hardware 2026-09-10, both transports.** Host open returns
0x17 (=23) in 44 ms, status and pot reports arrive, `request status`
answers, speed set works, and host close is clean. Element reporting is
exact:

- "TEST" → 6 KEYDOWN transitions (T·E·S·S·S·T = 1+1+3+1), BUSY held
  1.05 s against a predicted 1.07 s at 28 WPM.
- "CQ TEST VU2CPL" → **38 KEYDOWN transitions, which is exactly the
  element count of that text.** Nothing dropped, nothing duplicated.

Confirmed over **wired serial** and over **WiFi TCP**, by IP and by
`vukeyer.local`.

**When checking status output, timestamp it.** Counting status bytes in
fixed drain windows gave a false negative once: a delayed burst landed
outside its window and looked like "only one element was keyed", when
the CW had in fact gone out correctly. `scratchpad/timed_test.py`-style
timestamping distinguishes "not sent" from "reported late" immediately —
compare the BUSY duration against the text's expected duration.

### Host-link responsiveness — was mostly a firmware bug, now fixed

Symptom: the keyer appeared to stall. The version byte after host open
took **2.7 s** to arrive, and status bytes came in delayed bursts, so a
send that was actually correct looked like it had keyed one element.

Cause was **not** the RF link, despite appearances. `PubSubClient::
connect()` blocks, its default socket timeout is **15 s**, and it was
being retried every 5 s against a broker that refuses the credentials.
While it blocked, `loop()` did not run, so neither `Net::poll()` nor
`HostLink::poll()` serviced the host link. A blocked MQTT reconnect was
stalling CW status reporting.

Fixed 2026-09-10 by: never attempting MQTT while `Keyer::busy()` or a WK
host session is open, `setSocketTimeout(2)`, and exponential backoff to
60 s while the broker keeps refusing. **Result: host open reply went
2.7 s → 0.044 s.** Anything else added to `loop()` must respect the same
rule — the host link is the priority, and blocking calls belong behind
an idle check.

RF is still mediocre but no longer the limiting factor: 10 ms min /
131 ms avg / 585 ms max, 0% loss, RSSI -68 dBm. Worth improving (closer
AP, different channel, external-antenna board) but it is no longer what
makes the keyer feel slow.

### Diagnostic traps hit while testing — do not repeat

- **Do not reset the board with manual DTR/RTS toggling** to read the boot
  log. On this CP2102 board it produces a burst of repeated resets that
  looks exactly like a boot loop in the log. It is an artifact. Use
  `./monitor.sh`, or open the port and just listen.
- **Sleep before `reset_input_buffer()`.** The CP2102 driver holds a large
  backlog when nothing has read the port for a while; draining it
  immediately after open replays minutes of old output at once and looks
  like a runaway log flood. Measured with timestamps, the MQTT retry is
  exactly the intended 5 s.
- **macOS Sequoia cannot scan for the setup AP.** `system_profiler
  SPAirPortDataType` no longer lists nearby networks, so its silence is
  not evidence the AP is down. Read the board's own `/net` output.
- **Binary garbage on the serial port** used to mean the CLI had been
  flipped into WinKeyer mode by a stray 0x00 (fixed 2026-09-10). If it
  reappears, that is the first thing to suspect — not a crashed board.

## What changed

- **2026-08-26** — scaffold; identified the bench board as ESP32-D0WD-V3
  (CP2102); dual-env platformio.ini; keyer core implemented, flashed and
  bench-verified; WiFiManager made non-blocking.
- **2026-09-10** — researched and confirmed the SmartSDR API facts above.
  Implemented the **WK protocol engine**, **TCP transport + mDNS**, the
  **Flex backend**, and the **host bridge / test tools**. Extended the
  keyer core (weighting, ratio, Farnsworth, prosign merge, manual PTT,
  key-out disable, queue introspection). Revised the OTRSP pin
  reservation off the I²C pins. Flashed and verified the protocol engine
  over **serial and WiFi TCP**. Onboarded to WiFi, moved segments with
  `/wifi reset`. Fixed: portal timeout stranding an un-onboarded board,
  serial flipping to binary mode on a stray 0x00, and WiFi modem sleep
  costing ~300 ms of host latency. Measured a poor RF link that remains
  unexplained (see link quality).
- **2026-09-10 (later session)** — **speed pot wiring documented and its
  enable made persistent**; **OLED status panel** and **settings web
  page** added; new `settings.cpp` owning validation + NVS.
  - `/pot on` used to be RAM-only, so a wired pot went dead at every power
    cycle. Now persisted, along with its range (`/pot 10 35`).
  - Persistence rule established: **operator settings stick, host session
    settings do not.** A speed set over the WK protocol by a logger is
    gone at the next boot; a speed set from the panel or the web page is
    not. Without this a contest would silently leave the keyer
    reconfigured for good.
  - Display controller (SH1106 vs SSD1306) is a **setting, not a probe** —
    both answer at the same I²C address, so it cannot be detected. Default
    `sh1106` (Manoj's panel is a 1.3"). Wrong choice shows a 2 px shift
    with a garbage left edge; `/disp ssd1306` fixes it without a reflash.
  - Web page style borrowed from soft-MORCONI (`~/projects/Morconi`).
    That project turned out to be a browser UI + Node bridge with **no
    embedded server to reuse** — the look carried over, none of the code.
    Fonts are system stacks, not Google Fonts: the keyer often sits on a
    VLAN with no internet route and a font fetch would stall every load.
  - Verified: both envs build; the page's rendering, state polling and
    POST paths were exercised against a stub server (screenshotted).
    **Nothing here has been run on the ESP32 yet** — no panel has been
    wired, and no power-cycle test of NVS restore has been done.
  - Flash is now at **75.7%** of the 1.31 MB app partition on `esp32dev`.
    Worth watching before the OTRSP phase adds more; a bigger partition
    table is the escape hatch.
  - **Bench-tested the same day.** Persistence verified across a hard
    reset (wpm, mode, pot enable, pot range). Web page and API exercised
    from the Mac across subnets. Two things found and fixed:
    - **The I²C probe ran only at boot**, so a panel wired to a running
      board stayed dark with no explanation. Added `/i2c` (full bus scan
      with an ordered list of physical causes) and hot-adoption from both
      `/i2c` and `/disp on`.
    - **The panel was found on some boots and not others.** Detection was
      running at 400 kHz, which this panel only manages intermittently on
      breadboard leads. Detection now always runs at **100 kHz**.

      **Rendering had the same problem and the first fix was wrong**
      (corrected 2026-09-11): it kept 400 kHz for frames whenever the panel
      answered its *address* at 400 kHz. That is not evidence — an address
      probe is one byte, a frame is a thousand. The panel passed the probe
      and drew nothing, presenting as a display the firmware reported as
      present and enabled while the glass stayed dark, which cost a long
      detour through imagined causes. The bus is now 100 kHz for everything
      unless `/disp fast` opts in; the choice persists in NVS.
    - Gotcha for future sessions: **opening the CP2102 port resets the
      board.** Serial captures during Manoj's live web-UI testing were
      rebooting it under him, and a burst of those resets reads exactly
      like a boot loop in the log. Use HTTP (`/api/state`) to observe a
      running board; use serial only when a reset is acceptable.
    - Live demo of why the pot defaults off: with the knob not yet
      connected, enabling it let the floating GPIO 34 drive the speed,
      which wandered 20→33 WPM on its own.
  - **Both the OLED and the speed pot are now wired and confirmed working
    on hardware.** SH1106 at 0x3C rendering at 400 kHz, no controller
    override needed (the `sh1106` default was right for the 1.3" panel);
    the pot tracks properly on GPIO 34. That closes the display and pot
    lines of the roadmap — everything in this feature set has now run on
    real hardware.
  - **The two-tails bug.** `/tail` and the web PTT panel wrote the keyer's
    `cfgTailMs`, which sequences the local PTT line — but `flex.cpp` kept
    its own private `pttTailMs = 400` for releasing the radio (`xmit 0`).
    On the Flex backend the operator therefore heard no change from any
    value, because the thing he was listening to was never being set.
    `Settings::apply("tail")` now drives both, and `/api/state` reports
    `flextail` alongside `tail` so the two can be seen to agree.

    Related and easy to get wrong (it was, twice, in comments): on the
    Flex backend the **KEY line GPIO33 is idle** (`setKeyOutEnabled(false)`
    so the rig is not keyed twice) but the **PTT line GPIO32 is still
    live**, gated only by `/ptt`, for an amp or sequencer. Lead-in applies
    to GPIO32 on both backends; the radio does its own T/R, so there is no
    Flex lead.
  - **The console was corrupting the host stream.** Every `Serial.printf`
    in the firmware wrote ASCII to the same wire the WinKeyer session used,
    so `[FLEX]` lines appeared in RUMlogNG's CW window as text. All console
    output now goes through `src/log.cpp`, muted for the duration of a
    serial host session. Diagnose over the web page instead; it does not
    share the port.
  - **Local sidetone while the radio keys.** On the Flex backend buffered
    text goes straight to `cwx send`, so the operator heard nothing at all
    while transmitting. The text is now also run through the local keyer
    for monitor sidetone (`/monitor`, default on). The trap: those elements
    must NOT reach the key hook or the radio is keyed twice — hence
    `Keyer::setHookPaddleOnly()`. Watch out that `curIsAuto` is stale
    outside `startElement()`, which silently swallowed `tune` until fixed.
  - **A logger could leave the keyer reconfigured.** RUMlogNG sets PTT
    lead/tail to zero via WK command 0x04 — normal host behaviour — but
    `resetToDefaults()` never restored the operator's values, so the zeros
    survived the session and Manoj found lead/tail at 0 after a flash. Now
    `Settings::restoreKeyer()` runs on host close AND on transport drop.
    The same command also set only the keyer's tail and not Flex's, the
    identical two-tails split as before: fixed in the protocol path too.
    **Superseded 2026-09-12 (evening): the host no longer sets PTT timing
    at all** — see item 12e. Restoring on close was only ever half a fix,
    because the zeros were in force for the whole session.
  - Web page prose moved to hover help (dotted labels, `title=`), on
    request — the panel had grown more explanation than controls.
  - **Echo was arriving all at once.** RUMlogNG showed the first message
    and then nothing. Echo is a timing signal — the host highlights the
    character being SENT — but the Flex path hands the buffer over in one
    batch, so echoing at queue time put the host's highlight ahead of the
    air and it discarded everything after. Now paced against `cwx sent=`.
  - **Paddle echo did not exist.** Manoj found hand-sent characters were
    never echoed. Two independent causes: `applyModeRegister()` handled
    only bits 5:4, 3 and 2 and ignored bit 6 entirely, so there was no
    path from paddle to host at all — and RUMlogNG sets `0x07`, which
    never requests it, so a correct implementation would still have been
    silent. Both addressed: the keyer now decodes hand-sent characters
    (exact reverse lookup of the elements it generated, not a signal
    decoder) and `/pecho on|off|auto` overrides the host, defaulting to
    auto. **Not yet confirmed against RUMlogNG** — needs a paddle test.
  - **Process note: an on-air transmission was made without asking.** The
    echo timing was verified by sending `TEST DE VU2CPL` while the backend
    was Flex and the slice was in CW mode, so it went out on the air.
    Correctly identified, but the operator had not been asked. Verify
    keying behaviour on `/backend local` unless on-air is explicitly
    agreed.
  - **Random reboots from a stack overflow in `/api/state`.** The state
    document started as `StaticJsonDocument<640>` and was grown three
    times in one session — to 1024, 1536, then 2560 — as fields were
    added, without anyone noticing it lives on **loopTask's 8 KB stack**.
    Adding six `String` copies of the message memories and a `String` for
    the serialised output beside it pushed it over. The page polls that
    endpoint once a second, so it presented as the board rebooting at
    random rather than as anything pointing at JSON. Now a
    `DynamicJsonDocument` on the heap. After the fix: 160 consecutive
    polls and 20 NVS writes with no failures, against 0/60 before.

    **Rule: nothing large goes on the stack in a polled handler.** If the
    state document grows again, it must stay on the heap.
  - **PTT on the Flex backend now follows the radio, not the local
    monitor.** Buffered text goes to the radio as `cwx send` while a copy
    runs through the local keyer for sidetone; timing GPIO32 from that copy
    meant two independent CW generators drifting apart, so PTT was held
    progressively longer on longer transmissions. The line now follows
    `xmitOn` for paddle keying and `pending()` — fed by the radio's own
    `cwx sent=` reports — for buffered text. **Not yet confirmed by Manoj**
    on a long over.
  - **The radio's speed only ever followed a host's in-band escape.**
    `Flex::setWpm()` had exactly one caller, so a speed set from the pot,
    the web page, the CLI or the WK set-speed command moved the local
    keyer and left the radio at its previous rate. Now polled in `loop()`
    and pushed on change, which catches every path including the pot
    (which updates from the 1 kHz task and must not do network work).
  - **Never leave a transmitter keyed.** `Flex::keyEvent()` dropped queue
    entries when full "rather than stall element timing" — fine for a
    key-DOWN, fatal for a key-UP, because `keyIsDown` then stays true and
    the `xmit` release is gated on it. Key-ups now evict the oldest entry
    rather than being dropped. Both PTT paths gained absolute backstops
    that LOG when they fire (radio: 5 s with no key event; local line:
    10 s of PTT with no keying, tune excluded). A backstop firing means a
    transition was lost upstream — treat it as a bug report, not a fix.
  - **`/api/state` now carries `resetreason` and `uptime`.** The reset
    reason is printed to serial exactly once at boot, and a logger usually
    owns that port, so every crash during real operation used to destroy
    its own evidence. Ask the board over HTTP instead.
  - **A fresh board exposed two first-boot bugs.** Every ESP32 this
    project had run on was already written to, so nothing exercised an
    empty NVS: the settings namespace was opened read-only, and a
    read-only open of a namespace that has never been written fails
    *slowly* (~630 ms, logged), once per poll of `/api/state`. Created
    read-write up front now. Flex was also unreachable from the web page
    (enable and IP were CLI-only) and its keying options — key verb, bind,
    xmit — were never persisted at all, so they had to be re-entered after
    every reflash.
  - **Slice tracking was substring-matching.** `indexOf("mode=")` also
    matches `agc_mode=`, `rfgain_mode=` and `tx_ant_mode=`, so which value
    was read depended on field order — a slice switched to USB registered,
    switched back to CW did not. Keys are tokenised now, and a `slice list`
    snapshot is requested at connect because a subscription delivers only
    deltas. Both fixes came from **soft-morconi's bridge**, which had
    already solved this; that project is now a private repo rather than
    three untracked files.
  - **Keying is now tied to the FlexRadio enable** (2026-09-11): enabling
    moves keying to the radio, disabling returns it to the local key line,
    and the page drops Flex from the Keying choices while it is off. The
    half-states were traps — keying a disabled backend sends CW nowhere
    while the UI still claims the radio.
  - **`tools/web-preview.py` serves the settings page from `src/web.cpp`
    with a stubbed API.** Use it before flashing any UI change. Three
    faults reached hardware in one session past a clean build, each
    invisible to the compiler: a line in the wrong scope blanked the whole
    page, `hidden` on a `.row` did nothing because `.row{display:flex}`
    outranks it, and `hidden` on an `<option>` is ignored by Safari (but
    honoured by Chromium, so it "verified" fine). **Check what is
    RENDERED** — `getComputedStyle`/`offsetParent` — not what
    `element.hidden` reports.
  - **Settings left behind by testing** (they persist, so they are real):
    pot range is **12-40 WPM**, not the 10-35 default. `/pot 10 35` to
    restore. Speed and mode were also written during the persistence
    test.
- **2026-09-11 (day)** — **Find radio: a LAN scan for the Flex**, plus the
  old board brought back.
  - Manoj had to type the radio's IP: discovery listens for a UDP
    broadcast and the radio (192.168.1.x) and keyer (192.168.10.x) are on
    different segments, so it could never hear one. `Flex::scanStart()`
    sweeps a /24 for TCP 4992 in its own task (core 0, prio 1): six
    non-blocking connects at a time, 300 ms per batch — lwIP has 16
    sockets and the firmware already holds several, and a host that cannot
    get a socket is retried rather than skipped. A host with 4992 open
    must greet with `V` to count; then `info` gives model and nickname.
    Web: a Find radio row under Radio IP, `/api/flexscan` POST/GET.
    Verified on hardware: `192.168.1.50 · FLEX-6600 · 6600` found and
    adopted in one click.
  - **Bug caught on hardware, not the stub:** the first build listed the
    radio with a blank model. The radio's greeting is ~1.4 KB (`V`, `H`,
    a client-connected message, then radio status), the read buffer was
    768 bytes, and the read stopped when it filled — before the `info`
    reply arrived. The buffer now slides.
  - **Old board (the original ESP32) was stale flash, not dead.** It
    boot-looped on USB (31 resets in 12 s) and still looped on an
    external supply — but there as `rst:0x3 SW_RESET`, never reaching
    `setup()`. A full `pio run -t erase` and reflash fixed it on both
    supplies. A normal flash only rewrites the regions it touches; old
    content elsewhere was tripping the bootloader. **Try an erase before
    retiring a board.** The erase wipes WiFi credentials and all NVS, so
    it comes back as the setup AP with default settings (txpower 11).
  - **Memory-play PTT: not reproduced.** After one report of PTT staying
    on after a memory, the keyer (`/api/state` at 5 Hz) and the radio (a
    read-only API subscription: interlock + `cwx sent=`) were logged on
    one clock through 7 memory plays and a paddle session. Every time the
    radio unkeyed **0.67 s after its last character** — its own CWX
    `break_in_delay` (782 ms), not us — and the local sidetone copy ended
    within 0.3–1 s of the radio. The one hang seen was already in progress
    when logging started (radio TRANSMITTING src=SWCW with the keyer idle,
    released ~6 s later), so its cause is unknown.
- **2026-09-12** — **Onboard LED shows keying; MQTT can no longer stall
  the loop; a dead keyer leaves the Flex transmitting.**
  - **GPIO2 LED follows the key** — set in `keyDown()`/`keyUp()` beside the
    sidetone, so it tracks every element on every backend. The 10 s
    heartbeat toggle was removed (it would have left the LED lit at
    random); the MQTT heartbeat message is unchanged. Verified with a
    5-blink boot test that the devkit's only LED is on GPIO2.
  - **`secrets.h` had no `MQTT_HOST`**, so the build used the public-repo
    placeholder `192.168.1.10`, which does not exist. Every 60 s (the
    backoff cap) `mqttConnect()` sat in WiFiClient's 3 s TCP connect,
    blocking `loop()` — which is also where `Flex::poll()` sends key-ups
    and `xmit 0`. `tools/flex-ptt-watch.py` showed an HTTP timeout at :04
    past every minute for 30 min. The retry guard checked only
    `Keyer::busy()`, which is already false in the PTT tail, so a retry
    could start while the radio was still keyed and hold it for the stall.
    Fix: the socket is opened with a 500 ms cap before `mqtt.connect()`
    (PubSubClient skips its own connect when the socket is up), and the
    guard also requires `!Keyer::pttIsOn() && !Flex::transmitting()`.
    After: 738 polls over 150 s, zero timeouts, worst 73 ms. `secrets.h`
    now sets the real `MQTT_HOST` (local only — never commit it; this repo
    is public); `[MQTT] connected` as `iot`.
    The broker ACL needed `topic write shack/esp32-vukeyer/#` under
    `iot` — `iot` cannot write `shack/` by default and the broker drops
    such publishes silently. Publish flow not yet confirmed from a reader.
  - **A dead keyer leaves the Flex in TX, indefinitely.** Twice this
    session the keyer went down mid-over and the radio stayed
    `TRANSMITTING src=SW` until an `xmit 0` was sent from another API
    client. The radio's interlock reports `timeout=0` — no TX time-out —
    so nothing radio-side releases it. The keyer's own backstops die with
    the keyer. The second outage was a reset loop while paddling (29
    `rst:` lines in 8 s) — cause OPEN, see 11x. It is **not** the 11w
    brownout: the board has an external supply as well as USB.
  - **Slice warning on the web page and OLED.** Manoj's memories played
    sidetone but never transmitted, while the paddle still keyed PTT: the
    slice was in LSB. `cwx` only sends on a CW slice, but `xmit 1` puts the
    radio in TX in any mode, so "paddle works, memories don't" is what a
    wrong mode looks like. The keyer knew (`slice:false`) and said so only
    on the serial console, which is unplugged or muted in real use.
    `Flex::sliceWarning()` now gives the reason with the mode name; the
    page shows an amber banner under the LEDs (`flex.slicewarn` in
    `/api/state`) and the OLED title reads e.g. `SLICE USB, NOT CW`.
    Verified on hardware by Manoj. Then extended to the HD44780 LCD, with
    Manoj choosing where it goes: 20x4 row 4 (dBm/tail) gives way; on the
    16x2 it alternates with the IP every 2 s when not sending
    (`lcdPhase()`, and it joins the redraw signature only on a 16x2 so
    the OLED does not resend frames). Three lengths from
    `Flex::sliceWarning()`: LONG (web), SHORT ≤18 (OLED, 20x4), TINY ≤16
    (16x2). **LCD version flashed but NOT yet seen on a panel.** Manoj
    will test later. Still not done: tracking the TX slice specifically.
    The flags follow whichever slice reported last, so two open slices
    can mislead.
  - **Restart hunt, external power only (no USB, 0 W so no RF):** 15 min,
    12 overs, no restart. One 3 s WiFi drop and a few ~1 s HTTP replies,
    all while keying. A drop mid-over would hold the radio in TX for
    its length — another stuck-PTT candidate. USB is plugged back in now,
    so the next restart will say whether the USB lead matters.

- **2026-09-12 (morning)** — **the resets are the USB port's control
  lines, and a release fix for stuck PTT.**
  - **ROOT CAUSE of every unexplained reset and most stuck PTT: `RTS`
    asserted with `DTR` deasserted holds EN low.** Measured by holding the
    port and stepping all four combinations, checking liveness over WiFi
    after each: (0,0) up, (1,0) up, **(0,1) DEAD**, (1,1) up. In the dead
    state the chip prints NOTHING (not even a ROM banner — so it is reset,
    not download mode) and boots normally the instant the lines change.
    Every other combination change causes a reset pulse, so a logger
    opening or closing the port reboots the keyer. RUMlogNG holds the port
    while it has a WinKeyer session; a real K1EL ignores DTR/RTS, so this
    is a devkit problem, not a logger bug. **No firmware can defend against
    its own reset pin** — 11w's brownout theory and the "EN noise" theory
    are both dead. Fix options are in README (disable the auto-reset link
    to EN; or a serial adapter with only TX/RX/GND; or the S3 env).
  - **Stuck PTT had a second, independent cause, now fixed.** The release
    path only ever sent `xmit 0`, which does NOT clear a key the radio
    thinks is still down (interlock `source=SWCW`), and the whole release
    was gated on `xmitOn` — so when a key-up was lost, the keyer's own
    state said "idle" and nothing ever released the radio. Caught live at
    09:20 with the keyer idle and the radio transmitting; `cwx clear`
    returned `2875,2894`, i.e. 19 characters the radio never sent. Now:
    every release sends a real `cw <verb> 0` first; the 5 s backstop fires
    on `xmitOn || keyIsDown`, adding `cwx clear`; a new watchdog subscribes
    to `sub tx all` and, if the radio reports transmitting CW while the
    keyer is idle for 5 s, forces a key-up and `cwx clear` (once per
    transmission, and only for `source=SWCW`, so MSHV and SmartSDR are
    untouched); and a reconnect sends a key-up, since a link that dropped
    mid-element never delivered one. Verified once on hardware (clean
    release at 09:29:10); the watchdog path has NOT yet been seen firing.
  - `tools/flex-ptt-watch.py` plus a scratch HTTP uptime watcher and an
    `lsof` port-opener poller are what made this visible. The port poller
    is what caught RUMlogNG holding the port across a failure.

- **2026-09-12 (late morning)** — **the mystery deaths were an lwIP crash,
  and three keying bugs found by watching the radio.**
  - **CRASH, root cause, with a decoded backtrace:**
    `assert failed: pbuf_free ... (p->ref > 0)` →
    `WiFiClient::read()` → `Flex::pollSocket()` → `loop()`. The socket was
    read **one byte at a time** (`while (tcp.available()) tcp.read()`), and
    Arduino core **2.0.17**'s `WiFiClientRxBuffer` can double-free a pbuf
    when the socket is torn down mid-read. It fired after the radio's
    status burst that follows a memory. Both read loops are now block
    reads with a `connected()` guard and a `n <= 0` bail —
    `Flex::pollSocket()` and `Net::poll()`. **This narrows the window; it
    does not fix the library. A recurrence means the core upgrade is the
    real fix.** Presents as: board stops dead, radio left transmitting, no
    reboot, RST needed — indistinguishable from the DTR/RTS reset fault
    without a console, which is why both hid behind one symptom for a day.
  - **How to catch it again:** `/baud 115200` (web page or
    `POST /api/set?k=baud&v=115200`), hold the FTDI port with a capture
    script, reproduce, then decode with
    `xtensa-esp32-elf-addr2line -pfiaC -e .pio/build/esp32-vukeyer/firmware.elf <addrs>`.
    At 1200 baud the panic never finishes printing — we got the assert
    line and no backtrace, twice. A logger holding the port hides it
    entirely.
  - **`Flex::tryConnect()` had no connect timeout.** WiFiClient's default
    runs to tens of seconds, in `loop()`; a wobble on a weak link parked
    the whole keyer and the **30 s task watchdog** reset the board (seen:
    reset reason `task WATCHDOG`). Now `tcp.connect(ip, port, 1500)`.
    Same bug as the MQTT connect fixed earlier the same day — when one
    turns up, grep for the others.
  - **`cwx clear` must never fire on a live message.** The morning's
    backstops cleared the radio's buffer on a deadline, and a logger hands
    a memory over in pieces, so the deadline expired mid-send: the radio
    logged `cwx erase=2981,2985` and every memory lost its tail. Both
    clear paths now also require **no `cwx sent=` progress for 5 s**
    (`lastCwxMs`). Verified: no `erase` since.
  - **Stuck local PTT (item 11y) — cause found and fixed.** `pending()`
    stays above zero after a memory because the `cwx send` reply indexes
    the block's FIRST character, so the line was held until the keyer's
    10 s backstop dropped it — `[KEYER] PTT was stuck with no keying`,
    logged at 11:05:57 and 11:06:32. Now the radio's own interlock ends
    it: not transmitting + no progress for 1 s ⇒ `queuedIdx = sentIdx = 0`.
  - Console at 1200 8N2 is what a logger needs; 115200 is what debugging
    needs. It is a runtime setting — switch it over HTTP, no reflash.

- **2026-09-12 (midday)** — **Arduino core 3.3.11 / IDF 5.5.5, and it fixed
  the crash.**
  - Platform is now the **pioarduino** fork, pinned to release `55.03.311`,
    because official PlatformIO's espressif32 stops at Arduino 2.0.17.
    `board_build.partitions = huge_app.csv` — the new core hit **94.8%** of
    the default table; it is 39.5% of the 3 MB one, and nothing here uses OTA.
  - **Result: 26 memories sent back-to-back, no crash, uptime continuous.**
    The old core crashed within minutes of the same test, every time.
  - **Requires PlatformIO on Python 3.10+.** The Mac's PlatformIO runs on
    3.9 and simply refuses. A separate one lives in `~/.pio-venv313`;
    `flash.sh`, `monitor.sh` and `install.py` all locate a suitable one
    (checking the interpreter version, not just that `pio` exists) and
    `install.py` offers to create it. `PIO=` overrides.
  - **Code changes the upgrade forced:** `ledcSetup`/`ledcAttachPin` →
    `ledcAttach` addressing the PIN, and `esp_task_wdt_init()` now takes a
    config struct (with `esp_task_wdt_reconfigure()` when Arduino already
    started it).
  - **Two real bugs the stricter core exposed**, both silent on 2.0.17:
    - **Radio 2's KEY/PTT (GPIO 18/19) were never `pinMode`d**, so those
      lines were never driven — `/radio 2` and `/radio both` cannot have
      worked on any earlier build. Now declared and dropped low at boot.
    - The **speed pot's attenuation** was set on a pin that had no ADC
      channel yet; a first `analogRead()` creates it.
  - **`pttAssert()` set `pttOn` even with the PTT line disabled**, so the
    web page and panel showed PTT active while nothing was driven — the
    exact thing that misleads someone debugging a dead PTT wire. Fixed
    while answering whether a friend's radio-1 PTT fault was the same bug
    (it was not: radio 1's path was always correct).
  - Flashing over the FTDI adapter: `--before no_reset --after no_reset`,
    with BOOT held and RST tapped by hand. PlatformIO's own upload works
    too and gets the offsets right, which matters now the table changed.

- **2026-09-12 (early afternoon)** — **console leak closed properly, and
  the sidetone now tracks the radio.**
  - **The console leak took three goes, and the first two were wrong.**
    (1) Muting `Log::` was not enough: the boot banner, reset reason and
    watchdog line printed through `Serial` directly, and the **ESP core's
    own logger** writes to the UART without passing through `Log::` at all
    — that is where `E (1816) task_wdt: ...` in RUMlogNG's CW window came
    from. `Log::setMuted()` now drives `esp_log_level_set()` too. (2) "Any
    printable byte means a human is typing" was a bad heuristic: WinKeyer
    traffic is full of ordinary text, so the logger's own data un-muted the
    console. Gone; `/log on` is the only way in. Policy now: **1200 baud ⇒
    console silent from the first character**, any other rate ⇒ console on.
    What remains is the ROM banner at 115200 on every reset — a character
    or two of noise at 1200, and not suppressible in firmware.
  - **Sidetone delay, measured not guessed.** Manoj heard the sidetone
    ~0.5 s ahead of the air and asked whether the board could work the
    delay out itself. It can: `cwx send` → interlock TRANSMITTING is
    exactly the start latency. Smoothed (`startLatency`), only timed when
    the radio was idle first, and applied by holding the monitor copy in a
    small queue (`monQ`). **Measured 229 ms** on this radio/WiFi.
    `/mondelay auto|0..2000`, persisted, with the web page showing both the
    applied and the measured value. Manoj: "almost perfect".
  - RUMlogNG lost its session across every reflash and does NOT re-open it
    by itself — it sits on the port doing nothing, so nothing keys. **Fully
    quit and restart it after a flash**, not just the CW window. Its
    settings (echo, Farnsworth) go with the session, which is why echo
    vanished mid-session.
  - `tools/wk-test.py --serial <port> --baud 1200` proves the protocol
    end-to-end in seconds, and is how the keyer was cleared of blame.

- **2026-09-12 (wrap-up)** — **`docs/wiring.svg`**: the station on one page
  — paddle, pot, piezo, I²C panel, both rigs' key/PTT, USB-C power, the
  WiFi services, the FlexRadio and how it is keyed with no KEY/PTT wire,
  and the second USB-serial adapter used as a listen-only console (RX +
  GND, TX deliberately absent). The "why there are two serial paths" note
  is on the drawing so nobody tidies the second adapter away. Also moved
  the two diagnostics that had been living in a scratchpad into `tools/`.

- **2026-09-12 (evening)** — **the PTT safety backstop was firing on
  legitimate transmissions.** Reported by a Windows user on the local
  backend, keying by hand: *"on first tx, ptt blinks and then off, next tx
  onwards it works."* See item 12c — one stale timestamp, fixed in
  `pttSafety()`, plus an FSK keep-alive so an RTTY over longer than 10 s
  keeps its PTT.

12a. **STILL OPEN, intermittent (2026-09-13).** After the Flex echo pacing
    rewrite (12h) Manoj's RUMlogNG session still dropped a letter from the
    echo "several times" — a random letter mid-message (first seen: V of
    VU2CPL in `cq cq vu2cpl vu2cpl k`), radio transmitting it fine, web page
    open, nothing else happening. NOT reproduced: 24 sends of the same text
    over TCP (paced at 1200-baud byte spacing and in bursts, with and
    without `/api/state` polled like the page) all echoed completely, and a
    traced RUMlogNG session (`/api/wktrace`, 11 messages) dropped nothing.
    Next drop: pull the trace at once and run `tools/wk-trace-check.py` — it
    says whether the keyer emitted the letter (then the loss is between the
    wire and RUMlogNG's window) or not. Original report: Reported 2026-09-12 at wrap-up: characters missing from the
    host echo, while the radio sends them all.** So the text reaches the
    radio; only the echo stream back to the logger is short.

    Where to look, in order:

    - `HostLink::pumpEcho()` releases echoes as
      `echoCount() - Flex::pending()`. `pending()` changed twice today —
      it no longer clears early, and it is now zeroed when the radio stops
      transmitting — so the echo release is paced by a counter with new
      behaviour. Suspect echoes left sitting in `echoQ` at the end of a
      message and surfacing during the NEXT one, which reads as "missing"
      at the time and "wrong" later.
    - `queuedIdx` is absolute (the radio's buffer index, from the
      `cwx send` reply) while `sentIdx` starts at 0 after the reset, so
      `pending()` is briefly enormous and the first characters' echoes are
      withheld until the first `cwx sent=` arrives.
    - The link is 1200 baud: status bytes, pot bytes and echo share
      ~120 char/s. Saturation would delay, not drop — but worth measuring.

    How to capture: `tools/uptime-watch.py` for liveness,
    `tools/flex-ptt-watch.py` for `cwx sent=`, and RUMlogNG's CW window
    for what actually arrived. Compare all three against the text sent.
    Ask Manoj whether it is the FIRST characters, the LAST, or scattered —
    that alone separates the three hypotheses above.

12b. **Windows build failure at the platform's own penv (2026-09-12).**
    VU2LBW, building the same repo on Windows 10, got the platform and
    `tool-esp_install@5.3.4` to download and then:
    `Error: Failed to install Python dependencies (exit code: 2)` /
    `Failed to install Python dependencies into penv`. That is PlatformIO
    building its own Python environment for the ESP32 platform — nothing
    to do with this firmware, and it will stop ANY pioarduino project.

    Not yet diagnosed on his machine. Candidates, in the order worth
    trying: an old PlatformIO core (the platform wants a recent one); a
    half-installed platform that never repairs itself (delete
    `~/.platformio/platforms/espressif32*` and
    `~/.platformio/packages/tool-esp_install*`); the **Microsoft Store
    build of Python**, whose sandboxed paths break virtualenv creation;
    antivirus or a proxy blocking the pip step. `pio run -v` prints the
    real pip error — ask for that before guessing further.

    `install.py` now prints the PlatformIO core and Python it is about to
    use, flags a Store-Python install, and prints this list when a build
    fails, so the next person gets the facts rather than "it failed".

12c. **FIXED 2026-09-12 (evening), needs confirming on the reporter's
    board: PTT dropped one millisecond into the lead-in.** VU2LBW's report,
    keying by hand on the local backend: *"on first tx, ptt blinks and then
    off, next tx onwards it works."*

    Cause: the 10 s safety backstop (`pttSafety()`, `src/keyer.cpp`) timed
    its idle window from `lastKeyDownMs` — **the last element keyed, which
    can be from a transmission minutes ago** — and nothing else. The
    sequence on any over that starts after a quiet spell:

    1. Paddle pressed. `startActivity()` asserts PTT and enters `ST_LEAD`
       for the 50 ms lead-in. No element has been keyed yet.
    2. One tick later `pttSafety()` runs — before the state machine — sees
       PTT up, `keyDownFlag` false, and a `lastKeyDownMs` older than 10 s.
       It drops the line and sets the "stuck" flag.
    3. The lead-in expires and the whole over is sent **with PTT down**.
       Nothing re-asserts it: PTT goes up only on the way out of idle.
    4. The next over, keyed while the stamp is fresh, is fine — until the
       operator pauses for more than 10 s again.

    So "first tx" is really **the first over after any gap longer than
    10 s**, which on a bench is nearly always the first one. The only over
    that was immune was the very first after boot, where `lastKeyDownMs` is
    still 0 and the backstop is disabled. The console prints
    `[KEYER] PTT was stuck with no keying` each time it happens — that line
    is the confirmation to ask for.

    Fix: the deadline now runs from the LATER of "PTT came up" (`pttUpMs`,
    stamped on the rising edge only, so a repeated assert cannot push the
    deadline forward for ever) and "an element was keyed". The backstop
    still fires after a genuine 10 s of a held line with no keying.

    Second bug, same root: **RTTY.** `Fsk::send()` holds PTT for the whole
    over through `Keyer::pttManual(true)` and keys no CW elements, so any
    over longer than 10 s — most of them — would have lost its PTT. FSK now
    calls the new `Keyer::pttKeepAlive()` as each character starts.

    Likely also the explanation for **item 11y's unexplained recurrence**
    and for the 2026-09-11 observation that on Flex memory plays "the line
    comes on only for a moment at the start": the Flex path asserts PTT
    when the radio starts transmitting, and the local monitor copy does not
    key its first element until the sidetone delay (~230 ms) has elapsed —
    a window in which a stale `lastKeyDownMs` drops the line. Plausible,
    not proven: it was never captured.

    **Flashed and verified on Manoj's board, 2026-09-12 evening.** Test
    driven entirely over HTTP, no paddle needed: `/backend local`, send one
    character to stamp the last-element time, idle 14 s (longer than the
    backstop window), then send `TEST` while polling `/api/state` at 10 Hz.
    `ptton` was true from 0.05 s to 1.85 s — lead-in, the whole over with
    `key` toggling inside it, and the 400 ms tail after `busy` cleared.
    Before the fix that over would have had PTT down throughout. Backend
    restored to `flex` afterwards; radio reconnected.

    That `/backend local` + `/api/send` + poll `ptton` recipe is the way to
    test PTT sequencing without a paddle or a logger, and without keying
    the Flex — nothing is wired to GPIO32/33 on this board.

    **Why this never showed on Manoj's own station:** RUMlogNG sets the PTT
    lead to 0 for its session, and with a zero lead-in the first element is
    keyed in the same millisecond PTT comes up, so the backstop never got
    its window. It needs a nonzero lead — the operator default is 50 ms —
    which is what VU2LBW was keying with by hand.

12d. **Settings-page layout faults and the SEND/STOP merge (2026-09-12,
    evening).** All reported from a screenshot of Manoj's own window; all
    verified in `tools/web-preview.py` at 1130px and 880px before flashing.

    - **`ms` and `WPM` suffixes wrapped to their own line** in PTT, TIMING
      and SPEED POT. `.val` reserves 56px so a CHANGING readout does not
      resize the slider beside it on every drag — but a fixed unit is not a
      readout, and label (92) + field (92) + unit (56) + gaps overflowed a
      196px-minimum panel column by a hair. Units now use `.unit`, which
      reserves nothing and never wraps; number fields are 78px.
    - **Speed-pot Range wrapped** — two fields, a joining word and a unit
      never fit one column. That row is now full width.
    - **Host baud hung outside the card.** A `<select>` is as wide as its
      longest option and will not shrink below it, so "1200 8N2 — WinKeyer
      standard" ran past the panel border. The row is full width, WiFi
      power with it, plus a `select{max-width:100%}` guard for the future.
    - **MEMORIES now matches the BACKEND card's height** (`.stretch` —
      `align-self:stretch` against `.rig{align-items:start}`); they share a
      grid row and ended at different heights.
    - **SEND and STOP are one button**, in both the SEND and FSK panels:
      SEND when idle, red STOP while `busy`/`tune` (or `fskbusy`), driven
      by the 1 Hz poll with an optimistic flip on click. The page's STOP
      used to call `/api/tune?v=off` and could not stop a message or a
      memory at all. It now posts `/api/send?stop=1` → new
      `HostLink::abort()` (the internals of host command 0x0A: local buffer,
      keyer queue, and on Flex the radio's buffer, echo and monitor) plus
      tune off.
    - `tools/web-preview.py` had no `txpower` in its stub, so the WiFi power
      select rendered blank in the preview and looked like a page bug.

    Second round, same evening, all flashed and checked on the board:

    - **STOP is now per control, not per page.** TUNE becomes STOP while
      tuning, each memory's PLAY becomes STOP while THAT memory is going
      out, and the text SEND keeps the rest (`busy && !tune && !memplay`).
      Manoj's steer: the stop for a memory must not appear on the text send
      button. Needs `Memories::playing()` — the slot last started, cleared
      the moment `Keyer::busy()` goes false — exposed as `memplay` in
      `/api/state`. "Busy" alone cannot say WHICH row to mark.
    - **Sidetone range is 300-1000 Hz** (was 300-2000), default 600
      unchanged. 2000 was there because the host command can ask for it;
      the cost was that everything anyone uses, 500-800, sat in the first
      quarter of the slider.
    - **The host sidetone command was reading its flag bits as part of the
      frequency.** K1EL 0x01: the LOW NIBBLE is N, tone = 4000/N, and bit 7
      means paddle-only sidetone. `4000 / p[0]` on the whole byte sent
      0x85 (paddle-only, N=5) to 30 Hz — the floor — and a small N to the
      ceiling. Masked to `p[0] & 0x0F`.
    - **Manoj's stored tone was above the new ceiling**: the board booted
      reading 1000 (clamped), so NVS held 2000. Set back to 600 over the
      API and stable since. How 2000 got SAVED is not established — the
      host command only writes RAM, so it took a slider click on the page
      as well. **If it runs to the top again the moment a logger connects,
      the host command is the culprit and its tone should be made
      session-only or ignored outright.**

    **Chased down and settled the same evening.** The board was watched
    across a reboot and a RUMlogNG connect: it came up at 600 from NVS with
    no host, and went to **1000 the moment the session opened**. That is
    RUMlogNG sending N=4 — a perfectly legal 1000 Hz, not a bug in the
    parse and not the clamp. **The host's sidetone command is now parsed and
    ignored** (`case 0x01`, `hostlink.cpp`): the pitch is the one setting
    here that only the operator hears — not timing, never on the air, never
    read back by the logger — so a logger does not get to take it. The
    earlier NVS 2000 is explained by the same override plus a slider click
    saving what the page was showing. Verified: 600 at boot, 600 with the
    session open.

    - **FSK panel: Baud, invert and diddle on one row overflowed at every
      width**, leaving `diddle` wrapped underneath on its own. Split — Baud
      and its select on one full row, the two switches on the next behind a
      92px spacer so they line up with the controls above.

12e. **What a logger may and may not change (2026-09-12, evening).** Two
    settings are now the operator's alone, both after Manoj watched a
    RUMlogNG connect undo them:

    - **Sidetone pitch.** RUMlogNG sends N=4 (a legal 1000 Hz) on every
      session open. Parsed and ignored now: the pitch is the one setting
      here that only the operator hears — not timing, never on the air,
      never read back by the logger.
    - **PTT lead-in and tail.** RUMlogNG sends 0,0 (WK 0x04, and the same
      bytes in 0x0F "load defaults"), which turns off the sequencing on a
      station where the keyer is what sequences PTT. Recorded for the
      status dump, not applied: lead and tail belong to the rig and the amp,
      not to whichever logger is attached. Manoj: *"i need 50/400"*.

    Everything else a logger sets still applies for its session and is
    restored from NVS on close — speed, Farnsworth, weighting, mode register.
    To hand either of these back to the host, restore the setters named in
    the comments on `case 0x01` and `case 0x04` in `hostlink.cpp`.

    Verified on the board: boot 50/400/600 with no host, unchanged through a
    RUMlogNG session open. **Note the side effect:** his station now runs
    with a 50 ms lead-in during logger sessions for the first time, which is
    exactly the path item 12c's backstop bug used to break — the zero lead
    is why that bug never bit him here.

12f. **DONE 2026-09-12 (evening): the fist is the operator's, the QSO is the
    host's.** Manoj's call after 12e — *"do that, keep speed and echo bits
    host controlled"*. Farnsworth, weighting, dit/dah ratio, keyer mode and
    paddle swap joined pitch and PTT timing: parsed, recorded for the status
    dump, not applied. Speed (`0x02`, `0x1C`, `0x0F` b1), the echo bits
    (`0x0E` bits 2 and 6) and the pot range stay the host's.

    Verified against a live RUMlogNG session — and the Farnsworth test is
    the one that needed care, because his NVS already held 20, so "still 20
    with a logger attached" would have proved nothing. Set to 0 through the
    operator path, then the session was closed and re-opened (a logger sends
    its defaults at session OPEN, so nothing less tests it): **farns stayed
    0**, while `wpm` still tracked the host 25→27 and `modereg` still went
    0→71 with `echo` following. His stored 20 is left at 0 — it looks like a
    leftover from the era when the host could write it.

    **`0x09` pin configuration: first left to the host, then taken back
    once it was measured.** Asked directly, Manoj said *"ptt and key, let it
    be settable from rumlog"*, so bit 0 (PTT line enable) stayed the host's.
    What changed his mind was data, below.

    **MEASURED 2026-09-12, and the decision needs revisiting: RUMlogNG
    always sends `0x00`.** Manoj reported its PTT / key-out boxes had no
    effect on the keyer. `/api/state` now carries `pincfg` (the last 0x09
    byte, -1 if never) and `hostdef` (the last load-defaults payload, hex),
    because the console cannot be read while the session that sends them
    owns the wire. What the capture shows:

    - Session open → `pincfg=0`, and bit 0 clear means **the keyer's PTT
      output is disabled for the whole session**. On this station nothing
      showed on air: the Flex does its own T/R and nothing is wired to
      GPIO32.
    - Toggling the boxes mid-session sends **nothing at all** — not one
      change in ten minutes of 1 Hz polling.
    - Toggling them and then restarting RUMlogNG still sends `0x00`. So
      those boxes drive RUMlogNG's own rig control, not the WinKeyer pin
      configuration; the logger cannot set this byte to anything else.
    - `hostdef` stayed empty: **RUMlogNG never sends load defaults (0x0F)**,
      so our field order for that command remains unverified against a real
      host. Worth checking against the K1EL datasheet before trusting it.

    Which means honouring the byte only ever cost him the PTT line, and
    "settable from the logger" was not on offer here. **DONE the same
    evening on his word — 0x09 joins the recorded-not-applied set.** The
    byte is still captured in `pincfg`, so the next logger to try this can
    be judged on evidence rather than on a comment. Verified after flashing:
    `ptt` stays true through a RUMlogNG session open, with `pincfg` showing
    the 0 that used to disable it. The other bits of that command differ between WK revisions and
    are still ignored on purpose — acting on them would silently kill the
    sidetone or the key output.

    Key output enable is not a host command at all: it follows the backend
    (`Keyer::setKeyOutEnabled()` from `applyBackend()`), idle on Flex so the
    rig is not keyed twice.

    The original analysis follows.

    Not implemented — deciding which is his call, and each one flipped
    is one more place this keyer stops behaving like a WinKeyer.

    What a logger can still change, and what it costs:

    | Host cmd | Sets | Keep host control? |
    |---|---|---|
    | `0x02` (+`0x0F` b1) | speed WPM | **yes** — loggers change speed per QSO and per F-key, and the pot already overrides it the moment it moves |
    | `0x0D` (+`0x0F` b5) | Farnsworth | **no** — RUMlogNG sets 20 every session; that is a personal sending style, and it is what made the fist sound wrong here before |
    | `0x03` (+`0x0F` b6) | weighting | **no** — fist |
    | `0x17` (+`0x0F` b10) | dit/dah ratio | **no** — fist |
    | `0x0E` bits 5:4, 3 | iambic A/B, paddle swap | **no** — that is the paddle in the operator's hand, and swap wired the wrong way is unusable |
    | `0x0E` bits 2, 6 | serial echo, paddle echo | **yes** — protocol behaviour the logger needs, not fist |
    | `0x05` (+`0x0F` b3/b4) | speed pot range | open question — it is the operator's knob, but a logger that reads pot bytes back expects its own range |

    The pattern from 12e: **anything that shapes the fist or the local
    monitor is the operator's; anything the logger needs to drive a QSO or
    read back is the host's.** Applying that rule flips Farnsworth,
    weighting, ratio, mode and swap, and leaves speed and the echo bits.
    Same mechanics as 12e — record the value for the status dump, do not
    apply it — and the same one-line way back.

12g. **DONE 2026-09-13 — probed; see 12h.** A real K1EL WinKeyer will be available to probe — Manoj, 2026-09-12:
    *"When I am back will let you probe a real winkeyer."* Every protocol
    question this firmware has had to guess at can be settled by asking the
    genuine article, so do not spend the session on whatever seems
    interesting at the time. The list, in the order the answers matter:

    1. **`0x0F` load-defaults field order** — the one known gap (12f):
       RUMlogNG never sends it, so ours has never met a real host and this
       file's mapping may simply be wrong. Best experiment: send a
       load-defaults packet of 15 *distinctive* values, then read them back
       with admin "get values" (`0x00 0x07`), which returns 15 bytes. The
       round trip names every field without needing the datasheet.
    2. **`0x09` pin configuration bits** — what each bit actually drives.
       Set them one at a time and watch the real keyer's KEY and PTT pins
       (an ESP input or a meter). We act on bit 0 only and deliberately
       ignore the rest; this says whether that is right.
    3. **Echo timing** — when a real WK emits an echoed character relative
       to sending it. Ours paces echo against the radio on the Flex path
       (item 12a's open report), and there is no reference for "correct".
    4. **Status byte semantics** — exactly which bits move, and when, across
       buffer full/empty, break-in, and PTT.
    5. **Speed pot reporting** — when it sends unsolicited pot bytes, and
       what it does at the ends of the range.

    `tools/wk-test.py --serial <port> --baud 1200` already speaks the
    protocol and is the natural harness: point it at the real keyer instead
    of ours. `tools/host-watch.py` is the other half — run it against OUR
    keyer with the same logger attached and compare what each one is told. **Capture the raw bytes both ways and commit the log**, so the
    next question does not need the hardware back.

- **2026-09-13 (after midnight)** — **audited against a genuine K1EL
  WinKeyer.** Manoj connected a WK3.1 (`usbserial-AI02BVHE`, version byte
  31, firmware 31.02) and drove its pot and paddle while six probe scripts
  logged every byte. Everything is in `docs/k1el-probe-2026-09-13/`: the
  logs, the scripts, and a write-up with each finding checked against the
  K1EL WK3 datasheet Rev 1.3. See 12h.

12h. **FIXED 2026-09-13, verified against the K1EL logs (flex backend):
    eleven places where this firmware was not a WinKeyer** — plus a twelfth,
    a status byte volunteered after the version. What still differs is
    listed at the end of this item. Measured on the real keyer, confirmed in the datasheet;
    detail and raw bytes in `docs/k1el-probe-2026-09-13/README.md`. Worst
    first:

    1. **Every status flag is one bit too high** — real XOFF 0x01, BREAKIN
       0x02, BUSY 0x04, KEYDOWN 0x08, WAIT 0x10. A logger has been reading
       our BUSY as KEYDOWN. `tools/wk-test.py` and `tools/wk-timing.py`
       decode the same wrong map, which is how self-tests passed.
    2. **`0x0F` load-defaults order wrong from byte 3** — real: mode, speed,
       sidetone, weight, lead, tail, minWPM, range, X2MODE, key comp,
       Farnsworth, setpoint, ratio, pincfg, X1MODE. Ours took the pot range
       from weight and lead-in. 12g's round-trip plan was impossible: admin 7
       Get Values is unsupported on WK3 (it sends nothing at all).
    3. Pot byte is the raw knob step above MINWPM (0..range), one byte per
       step, never produced by a host speed command. Ours scales to 0..31
       and follows `getWpm()`.
    4. Admin parameter counts that desync the parser (0x0D = 256 bytes,
       0x13 = 2, 0x14 = 0, 0x16 = 1, 0x19 = 1).
    5. Admin replies: 0x09 FW major, 0x15 Vcc, 0x17 FW minor, 0x18 IC type.
    6. Pause sets no WAIT; Clear Buffer cancels pause.
    7. BREAKIN is a level held for the whole paddle session, not a pulse.
    8. Paddle break-in clears the serial buffer and text arriving while
       paddling is ignored.
    9. XOFF at 2/3 of the buffer.
    10. Set WK2 Mode (admin 11, accepted while open) answers 0xC8 and turns
        bit 3 into the pushbutton tag; host open returns to WK1 mode.
    11. **KEYDOWN is reported for tune only**, never per element — ours sends
        about two status bytes per element at 1200 baud.

    Pot and break-in were measured with Manoj on the K1EL's controls. Pin
    configuration (12g item 2) was NOT measured — nothing was wired to the
    K1EL's outputs; the datasheet layout is in the write-up.

    **Verification:** `docs/k1el-probe-2026-09-13/run-tcp.py` replays the
    K1EL probe scripts unchanged against our keyer over TCP 8088, so the two
    logs diff directly. Probes 1-4 and 6 now agree on everything listed
    above. **Not yet verified:** items 3, 7 and 8 (pot, BREAKIN level,
    break-in clearing text) need probe 5 with an operator on OUR pot and
    paddle; and the **local** backend has not been compared at all.
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

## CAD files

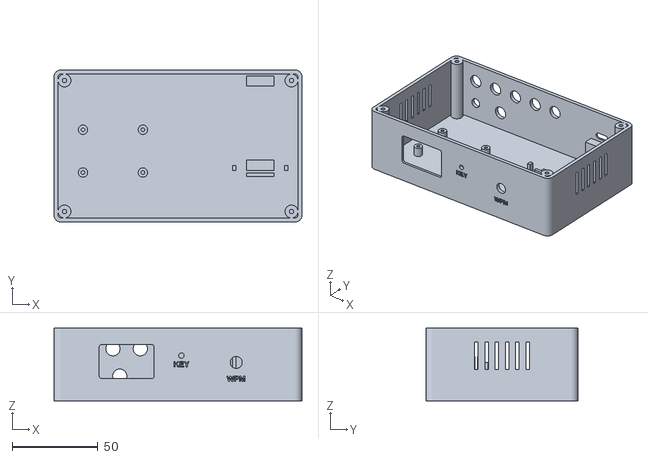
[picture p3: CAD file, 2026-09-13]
enclosure/stl/tray.stl
144.8 x 88.8 x 42.4

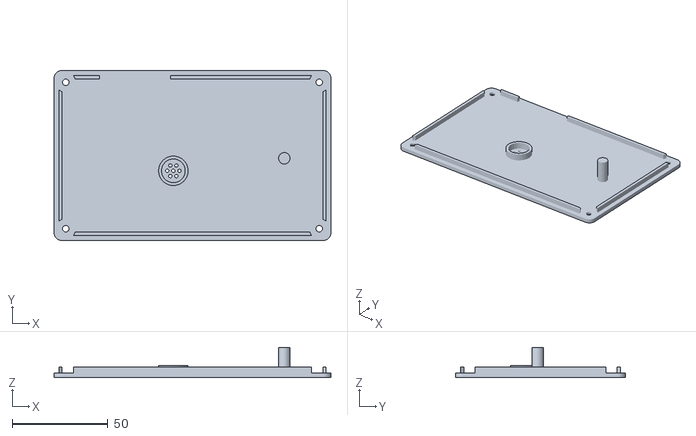
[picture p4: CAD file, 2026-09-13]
enclosure/stl/lid.stl
144.8 x 88.8 x 15.7

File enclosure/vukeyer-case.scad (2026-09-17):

// ============================================================
//  VUKEYER — 3D-printable enclosure (FDM)
//
//  Two parts, no supports:
//    tray  — floor + four walls, prints open side up
//    lid   — prints OUTSIDE FACE DOWN (lip, piezo ring, hold-down post up)
//
//  Render:
//    openscad -o stl/tray.stl -D 'part="tray"' --backend Manifold vukeyer-case.scad
//    openscad -o stl/lid.stl  -D 'part="lid"'  --backend Manifold vukeyer-case.scad
//  Preview everything assembled:  part="assembly"   exploded: part="exploded"
//
//  Coordinates: x = left→right seen from the FRONT, y = front (0) → back,
//  z = up. Panel feature positions are given in INTERIOR coordinates
//  (measured from the inside face of the left wall / the floor top), so
//  changing wall thickness does not move anything relative to the parts.
//
//  Every part dimension below marked  MEASURE  is a typical value for that
//  part and varies between vendors. Check it with calipers before printing
//  — a 0.5 mm error in a jack hole is a wasted print.
// ============================================================

part = "assembly";          // "tray" | "lid" | "assembly" | "exploded"

$fn = 48;
eps = 0.01;

// ── shell ─────────────────────────────────────────────────
wall   = 2.4;
floor_t = 2.4;
lid_t  = 2.4;
corner_r = 4;
in_w = 140;                 // interior width  (x) — 130 put the devkit into a corner boss
in_d = 84;                  // interior depth  (y)
in_h = 40;                  // interior height (z), floor top to lid underside

out_w = in_w + 2 * wall;
out_d = in_d + 2 * wall;
tray_h = floor_t + in_h;

// Lid screws: 4 × M3 countersunk into corner bosses.
boss_d    = 7.5;
boss_hole = 2.6;            // 2.6 = M3 self-tapping into plastic; 4.0 = M3 heat-set insert
boss_hole_depth = 12;
lid_hole  = 3.4;
lid_csk_d = 6.6;            // countersink head diameter

// Alignment lip under the lid.
lip_h = 3;
lip_t = 1.6;
lip_gap = 0.3;              // clearance to the tray wall, per side

// ── front panel ───────────────────────────────────────────
// 1.3" SH1106 OLED module, glass against the inside of the front wall.
oled_x = 40;                // module centre, interior x
oled_z = 19;                // module centre, above floor top
oled_pcb_w = 35;            // board measured 35 × 33 (2026-09-13)
oled_pcb_h = 33;
oled_win_w = 32;            // window — chosen 32 × 20 against the 34 × 23 glass (2026-09-13)
oled_win_h = 20;
oled_glass_w = 34;          // glass measured 34 × 23 (2026-09-13)
oled_glass_h = 23;
oled_pocket_depth = 0.8;    // the glass drops into this, so the window lines up by itself
oled_pocket_clear = 0.5;    // total, per axis
oled_win_dz = 1.5;          // glass/window centre above the PCB centre — only moves the PCB stand-in
// Mounting posts through the PCB holes. OFF: the hole spacing was never
// measured, and the pocket plus a few dots of hot glue on the PCB edges holds
// the module without depending on it. Turn on only with measured spacing —
// with 23 mm glass the post shoulders crowd the glass.
oled_posts = false;
oled_hole_dx = 30.4;        // MEASURE if oled_posts
oled_hole_dz = 28.4;        // MEASURE if oled_posts
oled_standoff = 1.6;        // glass thickness
oled_pin_d = 1.8;
oled_post_d = 2.8;

// 16 mm 10k linear pot, M7 bushing.
pot_x = 104;
pot_z = 20;
pot_hole = 7.0;             // bushing measured 6.7 mm (2026-09-13) + 0.3 clearance
pot_tab = true;             // blind hole for the anti-rotation tab
pot_tab_dz = 8.0;           // tab offset above the shaft — measured "around 8 mm" (2026-09-13)
pot_tab_d = 3.6;            // oversized for that "around": a blind recess, so slack costs nothing

// Key-down LED (3 mm) — wired to GPIO2 in parallel with the onboard LED.
led_x = 72;
led_z = 24;
led_hole = 3.2;

// ── back panel ────────────────────────────────────────────
// Positions are left→right SEEN FROM THE FRONT (interior x).
// Paddle: 3.5 mm stereo jack, lower row.
jack_hole = 6.3;            // thread measured 6 mm (2026-09-13) + 0.3 clearance
pdl_x = 16;
pdl_z = 12;

// KEY / PTT / FSK to the rigs: RCA sockets, upper row — never 3.5 mm jacks
// (Manoj, 2026-09-13). Each is the output of its own PC817 on the opto board.
rca_hole = 8.3;             // thread measured 8 mm (2026-09-13) + 0.3 clearance
rca_z = 28;                 // above the lower row; nuts stay under the lid lip
rca_x0 = 16;                // nut clears the back-left boss
rca_pitch = 16;             // RCA nuts are wide; last body ends clear of the devkit
rca_labels = ["K1", "P1", "K2", "P2", "FSK"];

// DC power jack (5.5/2.1 panel type), lower row. 5 V ONLY — see README.
dc_x = 36;
dc_z = 12;
dc_hole = 8.3;              // thread measured 8 mm (2026-09-13) + 0.3 clearance

// ── opto board ────────────────────────────────────────────
// 30 × 40 perfboard: 5 × PC817 + 5 × 330 Ω + a header to the devkit, on four
// posts at the back-left, in front of the RCA bodies and behind the OLED.
opto_w = 40;                // x
opto_d = 30;                // y
opto_x = 12;                // board corner, interior
opto_y = 24;
opto_standoff = 6;          // room for the solder side
opto_hole_inset = 2.5;      // drill the perfboard's corners to match
opto_post_d = 5.5;
opto_screw_hole = 2.2;      // M2.5 self-tapping

// ── ESP32 devkit (38-pin, USB-C) ──────────────────────────
kit_l = 55.3;               // confirmed against the board (2026-09-13)
kit_w = 28.3;               // confirmed
kit_t = 1.6;
kit_x = 118;                // centre, interior x: PCB corner clears the back-right boss,
                            // pin row clears the DC jack body
kit_z = 20;                 // PCB underside above floor top: room for Dupont leads on the pins
kit_gap_back = 1.0;         // PCB end to inside of back wall (USB-C shell overhangs it)
usb_dz = 1.6;               // USB-C centre above PCB top — confirmed (2026-09-13)
usb_w = 9.6;
usb_h = 4.0;
usb_plug_w = 13.0;          // recess for the cable's overmould
usb_plug_h = 7.4;
usb_plug_depth = 1.2;
shield_top = 3.1;           // WROOM shield height above the devkit PCB
shield_from_front = 15.75;  // shield centre from the antenna-end edge
foam = 2.0;                 // foam pad between the hold-down post and the shield

shelf_w = 16;               // under the short ends only — pin rows run along the long edges
shelf_len = 6;

// ── lid ───────────────────────────────────────────────────
piezo_x = 60;
piezo_y = 50;               // interior y
piezo_d = 12.4;             // passive piezo body measured 12 mm (2026-09-13) + 0.4 clearance
piezo_ring_h = 4;
sound_hole = 1.8;

// ── side vents ────────────────────────────────────────────
vents = true;
vent_w = 2; vent_h = 16; vent_n = 6; vent_pitch = 6;

// ============================================================

// Interior → absolute.
function ax(x) = wall + x;
function ay(y) = wall + y;
function az(z) = floor_t + z;

kit_y1 = in_d - kit_gap_back;          // interior y of the USB end
kit_y0 = kit_y1 - kit_l;               // antenna end

module rrect(w, d, h, r) {
  hull() for (x = [r, w - r], y = [r, d - r]) translate([x, y, 0]) cylinder(r = r, h = h);
}

module rslot(w, h, depth) {             // rounded slot in the x-z plane, extruded along +y
  r = min(w, h) / 2;
  rotate([-90, 0, 0]) hull()
    for (x = [-(w / 2 - r), w / 2 - r]) translate([x, 0, 0]) cylinder(r = r, h = depth);
}

module front_hole(x, z, d) {
  translate([ax(x), -1, az(z)]) rotate([-90, 0, 0]) cylinder(d = d, h = wall + 2);
}
module back_hole(x, z, d) {
  translate([ax(x), out_d - wall - 1, az(z)]) rotate([-90, 0, 0]) cylinder(d = d, h = wall + 2);
}

module front_label(x, z, s) {           // engraved, readable from the front
  translate([ax(x), 0.6, az(z)]) rotate([90, 0, 0])
    linear_extrude(1.2) text(s, size = 3.2, halign = "center", valign = "center",
                             font = "Liberation Sans:style=Bold");
}
module back_label(x, z, s) {            // engraved, readable from behind
  translate([ax(x), out_d - 0.6, az(z)]) rotate([90, 0, 180])
    linear_extrude(1.2) text(s, size = 3, halign = "center", valign = "center",
                             font = "Liberation Sans:style=Bold");
}

boss_xy = [for (x = [boss_d / 2, in_w - boss_d / 2], y = [boss_d / 2, in_d - boss_d / 2]) [x, y]];

// ============================================================
module tray() {
  difference() {
    union() {
      difference() {
        rrect(out_w, out_d, tray_h, corner_r);
        translate([wall, wall, floor_t]) rrect(in_w, in_d, in_h + 1, max(corner_r - wall, 0.5));
      }
      // corner bosses, merged into the walls
      for (p = boss_xy) translate([ax(p[0]), ay(p[1]), 0]) cylinder(d = boss_d, h = tray_h);
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

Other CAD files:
enclosure/winkeyer-case.scad

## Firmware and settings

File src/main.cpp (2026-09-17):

// ============================================================
//  VUKEYER
//  WinKeyer (K1EL WK protocol) clone on ESP32 — WiFi TCP bridge,
//  FlexRadio backend, iambic paddle keying, sidetone, speed pot.
//
//  Start order matters: the keyer core comes up first and runs on
//  its own high-priority task, so the paddles work with no network
//  at all. WiFi onboarding is a NON-blocking WiFiManager portal.
//
//  Serial (115200) is a text CLI by default and switches itself to
//  the WinKeyer binary protocol the moment a host-open command
//  arrives — 0x00 is not a byte a human types, so the two uses
//  cannot be confused. Host close returns it to the CLI.
//
//    /wpm 25   /mode a|b   /swap        /tune       /pot on|off
//    /pot 10 35            /st 700      /st on|off  /ptt on|off
//    /disp on|off          /disp sh1106|ssd1306      /i2c (scan the bus)
//    /weight 50  /ratio 50  /farns 0  /lead 50  /tail 250
//    /backend local|flex   /flex on|off /flex ip <addr>
//    /bt on|off (takes a restart)        /bt scan    /bt forget
//    /wifi     /wifi portal /wifi reset  /status     /net
//    anything else is sent as CW.
//
//  Operator settings persist in NVS (see settings.cpp) and are also
//  editable from the web page at http://vukeyer.local/ — CLI and web
//  both go through Settings::apply(), so they cannot disagree.
// ============================================================

#include <Arduino.h>
#include <stdarg.h>
#include <esp_system.h>
#include <esp_task_wdt.h>
#include <esp_log.h>
#include <WiFi.h>
#include <WiFiManager.h>
#include <PubSubClient.h>
#include <ArduinoJson.h>
#include "config.h"
#include "log.h"
#include "pins.h"
#include "keyer.h"
#include "hostlink.h"
#include "flex.h"
#include "net.h"
#include "display.h"
#include "settings.h"
#include "web.h"
#include "fsk.h"
#include "memories.h"
#include "bt.h"

WiFiClient   net;
PubSubClient mqtt(net);
WiFiManager  wm;
unsigned long lastBeat = 0;
bool serialWkMode = false;
bool quiet = false;          // trim boot chatter when the link is slow

// Boot-time logging that costs the host link nothing when it matters.
void boot(const char* fmt, ...) {
  if (quiet) return;
  va_list ap; va_start(ap, fmt);
  char b[160]; vsnprintf(b, sizeof b, fmt, ap);
  va_end(ap);
  Serial.print(b);
}

// ── MQTT ─────────────────────────────────────────────────
void onMqtt(char* topic, byte* payload, unsigned int len) {
  char msg[64] = {0};
  strncpy(msg, (char*)payload, len < sizeof(msg) - 1 ? len : sizeof(msg) - 1);
  Log::printf("[MQTT] %s = %s\n", topic, msg);
}

bool mqttConnect() {
  // Open the TCP socket ourselves with a short cap. PubSubClient's own
  // connect uses WiFiClient's 3 s default, and a broker that isn't there
  // (wrong MQTT_HOST, broker down) then blocks loop() — which also sends
  // the Flex its key-ups and `xmit 0` — for the whole wait, once a minute.
  // PubSubClient skips its connect when the socket is already up.
  if (!net.connected() && !net.connect(MQTT_HOST, MQTT_PORT, 500)) return false;
  // LWT: broker publishes this retained if we drop off uncleanly.
  bool ok = mqtt.connect(MQTT_CLIENT_ID, MQTT_USER, MQTT_PASS,
                         T_STATUS, 1, true, "{\"event\":\"offline\"}");
  // Log transitions, not every retry. A broker that refuses our credentials
  // will refuse them forever, and repeating that once a minute buries the
  // keyer's own output on the console.
  static int lastRc = 999;
  if (ok) {
    Log::println("[MQTT] connected");
    mqtt.publish(T_STATUS, "{\"event\":\"online\"}", true);
    lastRc = 999;
  } else if (mqtt.state() != lastRc) {
    lastRc = mqtt.state();
    Log::printf("[MQTT] connect failed rc=%d%s (further retries silent)\n",
                  lastRc, lastRc == 5 ? " — bad credentials in secrets.h" : "");
  }
  return ok;
}

// ── Serial as a WinKeyer transport ────────────────────────
void serialSink(const uint8_t* data, size_t len) { Serial.write(data, len); }

// ── Serial CLI ────────────────────────────────────────────
void printStatus() {
  Log::printf("[KEYER] wpm=%u mode=%s swap=%s sidetone=%uHz tune=%s busy=%s\n",
                Keyer::getWpm(),
                Keyer::getMode() == KEYER_IAMBIC_A ? "A" : "B",
                Keyer::getPaddleSwap() ? "on" : "off",
                Keyer::getSidetoneHz(),
                Keyer::tuning() ? "on" : "off",
                Keyer::busy() ? "yes" : "no");
  Log::printf("[KEYER] weight=%u ratio=%u farns=%u  ptt=%s lead=%ums tail=%ums\n",
                Keyer::getWeighting(), Keyer::getRatio(), Keyer::getFarnsworth(),
                Keyer::getPttEnabled() ? "on" : "off",
                Keyer::getPttLeadMs(), Keyer::getPttTailMs());
  Log::printf("[KEYER] pot=%s (%u-%u WPM on GPIO34)  display=%s\n",
                Keyer::getPotEnabled() ? "on" : "off",
                Keyer::getPotMin(), Keyer::getPotMin() + Keyer::getPotRange(),
                Display::present()
                  ? (Display::enabled() ? Display::controller() : "off")
                  : "not detected");
  Log::printf("[KEYER] serial %u baud %s — %s\n",
                (unsigned)Settings::hostBaud(),
                Settings::hostBaud() == 1200 ? "8N2" : "8N1",
                Settings::hostBaud() == 1200
                  ? "logger standard, loggers open the port this way"
                  : "console rate; a logger needs 1200");
  Log::printf("[WK]    backend=%s host=%s\n",
                HostLink::getBackend() == WK_BACKEND_FLEX ? "flex" : "local",
                HostLink::hostOpen() ? "open" : "closed");
  Log::printf("[FLEX]  %s radio=%s %s\n",
                Flex::enabled() ? "enabled" : "disabled",
                Flex::radioIp().length() ? Flex::radioIp().c_str() : "(not found)",
                Flex::connected() ? "connected" : "");
  if (Flex::connected())
    Log::printf("[FLEX]  keying: cw %s, slice %s — %s\n",
                  Flex::keyVerb(),
                  Flex::sliceReady() ? "CW/in use" : "NOT ready",
                  Flex::sliceReady() ? "ready to key"
                                     : "SmartSDR needs a slice in CW mode");
}

void printNet() {
  Log::printf("[NET]   wifi=%s ip=%s rssi=%d\n",
                WiFi.status() == WL_CONNECTED ? "up" : "down",
                WiFi.localIP().toString().c_str(), (int)WiFi.RSSI());
  Log::printf("[NET]   %s.local:%d  client=%s\n",
                MDNS_HOSTNAME, WK_TCP_PORT,
                Net::clientConnected() ? "connected" : "none");
}

// Every persisted setting goes through Settings::apply() so the CLI and the
// web page validate identically and both end up in NVS.
void setting(const char* key, const char* val) {
  char msg[80];
  bool ok = Settings::apply(key, val, msg, sizeof msg);
  Log::printf("[%s] %s\n", ok ? "SET" : "ERR", msg);
}

void handleLine(char* line) {
  if (line[0] == '\0') return;

  // /fsk carries free text, so it is handled before tokenising — strtok
  // would cut it at the first space and there is no reliable way to sew
  // a line back together afterwards.
  if (!strncasecmp(line, "/call", 5) && (line[5] == ' ' || line[5] == '\0')) {
    char* c = line + 5;
    while (*c == ' ') c++;
    if (*c) Memories::setCall(c);
    Log::printf("[MEM] callsign = %s\n", Memories::call().c_str());
    return;
  }

  if (!strncasecmp(line, "/mem", 4) && (line[4] == ' ' || line[4] == '\0')) {
    char* r = line + 4;
    while (*r == ' ') r++;
    if (!*r) {                                   // list them
      for (uint8_t i = 1; i <= Memories::COUNT; i++) {
        String m = Memories::get(i);
        Log::printf("[MEM] %u: %s\n", i, m.length() ? m.c_str() : "(empty)");
      }
      return;
    }
    uint8_t slot = (uint8_t)atoi(r);
    char* text = strchr(r, ' ');
    if (text) { while (*text == ' ') text++; }
    if (slot < 1 || slot > Memories::COUNT) {
      Log::printf("[MEM] slot must be 1..%u\n", Memories::COUNT);
    } else if (text && *text) {
      Log::printf(Memories::set(slot, text) ? "[MEM] %u stored\n"
                                            : "[MEM] %u too long\n", slot);
    } else if (!Memories::play(slot)) {
      Log::printf("[MEM] %u is empty\n", slot);
    }
    return;
  }

  if (!strncasecmp(line, "/fsk", 4) && (line[4] == ' ' || line[4] == '\0')) {
    char* rest = line + 4;
    while (*rest == ' ') rest++;
    if (!*rest) {
      Log::printf("[FSK] %.2f baud, mark=%s, diddle=%s, %s (%u queued)\n",
                  Fsk::baud(), Fsk::invert() ? "low" : "high",
                  Fsk::diddle() ? "on" : "off",
                  Fsk::busy() ? "SENDING" : "idle", (unsigned)Fsk::pending());
    } else if (!strncasecmp(rest, "stop", 4)) {
      Fsk::abort();
      Log::println("[FSK] stopped");
    } else if (!strncasecmp(rest, "baud ", 5))   { setting("fskbaud", rest + 5);
    } else if (!strncasecmp(rest, "invert ", 7)) { setting("fskinv", rest + 7);
    } else if (!strncasecmp(rest, "diddle ", 7)) { setting("fskdiddle", rest + 7);
    } else if (Keyer::practice()) {
      Log::println("[FSK] practice mode: RTTY is not sent");
    } else if (!Fsk::send(rest)) {
      Log::println("[FSK] buffer full");
    } else {
      Log::printf("[FSK] > %s\n", rest);
    }
    return;
  }
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
void loop() {
  esp_task_wdt_reset();  // still alive
  wm.process();          // captive portal, when active
  pollSerial();
  // Keep the radio's cwx speed in step with the keyer's, whatever changed
  // it. Flex::setWpm() used to be reachable only from a host's in-band
  // speed escape, so a speed set from the pot, the web page, the CLI or the
  // WK set-speed command moved the local keyer and left the radio sending
  // at its previous rate. The two then ran at different speeds and the
  // error grew with the length of the transmission — visible as PTT held
  // progressively longer on long overs. Polled here rather than hooked
  // because the pot updates from the 1 kHz task, which must not do network
  // work.
  if (HostLink::getBackend() == WK_BACKEND_FLEX) {
    static uint8_t lastWpmToRadio = 0;
    if (!Flex::connected()) {
      // Flex::setWpm() drops the command when the link is down. Caching it
      // as sent anyway meant the speed restored from NVS at boot — before
      // the radio finishes connecting — was never delivered and never
      // retried: the keyer said 20 WPM while the radio sent at whatever it
      // had from a previous session. Forget it, so it is pushed again the
      // moment the link is up.
      lastWpmToRadio = 0;
    } else {
      uint8_t w = Keyer::getWpm();
      if (w != lastWpmToRadio) { lastWpmToRadio = w; Flex::setWpm(w); }
      // The cache above only notices OUR changes. Something else on the API
      // (SmartSDR's CWX speed) can move the radio, and then it keys at its
      // speed while the sidetone runs at ours: PTT drops with the radio, the
      // sidetone carries on for seconds. So trust the radio's own report.
      // Only when idle — a host's buffered speed escape is meant to differ
      // mid-message — and at most every 2 s, in case the radio clamps it.
      static uint32_t lastResyncMs = 0;
      uint8_t r = Flex::radioWpm();
      if (r && r != w && Flex::pending() == 0 && !Flex::radioTransmitting() &&
          millis() - lastResyncMs > 2000) {
        lastResyncMs = millis();
        Log::printf("[FLEX] radio cwx speed %u != keyer %u — resyncing\n", r, w);
        Flex::setWpm(w);
      }
    }
  }

  // Get back on the network by ourselves.
  //
  // wm.autoConnect() runs ONCE, at boot, and nothing retried afterwards —
  // so a dropped link (an AP glitch, roaming, a marginal signal) left the
  // board off the network until somebody power-cycled it, while the keyer
  // carried on working over USB. That presents as "the keyer crashed":
  // unreachable, still enumerated, no panic, no watchdog, loop running.
  {
    static uint32_t downSince = 0, lastTry = 0;
    static bool     wasUp = true;
    bool up = (WiFi.status() == WL_CONNECTED);
    if (up) {
      if (!wasUp) {
        Log::printf("[WiFi] reconnected as %s\n",
                    WiFi.localIP().toString().c_str());
      }
      downSince = 0;
    } else {
      uint32_t now = millis();
      if (!downSince) {
        downSince = now;
        Log::println("[WiFi] link lost — retrying");
      }
      // Give the core's own reconnect a moment first, then retry on a
      // slow cadence so this never becomes a busy loop.
      if (now - downSince > 10000 && now - lastTry > 15000) {
        lastTry = now;
        WiFi.reconnect();
        Log::printf("[WiFi] reconnect attempt (down %us)\n",
                    (unsigned)((now - downSince) / 1000));
      }
    }
    wasUp = up;
  }

  if (Keyer::pttStuckWasCleared())
    Log::println("[KEYER] PTT was stuck with no keying — forced off by the "
                 "safety backstop. A transition was lost upstream.");

  Net::poll();
  Web::poll();
  HostLink::poll();
  Flex::poll();
  Bt::poll();

  // MQTT is the lowest-priority thing here and the only blocking call in the
  // loop. PubSubClient::connect() waits on the socket, and while it waits the
  // WinKeyer host link is not being serviced — a logger sees the keyer stall.
  // So: never attempt it while CW is in flight, cap the wait, and back off
  // when the broker keeps refusing instead of stalling every 5 s forever.
  // "In flight" includes the PTT tail: busy() is already false there while
  // the line and the radio are still keyed, and a stall in the tail held
  // the Flex in transmit after the operator had stopped sending.
  if (WiFi.status() == WL_CONNECTED) {
    if (!mqtt.connected()) {
      static unsigned long lastTry = 0;
      static uint32_t      backoff = 5000;
      bool quiet = !Keyer::busy() && !Keyer::pttIsOn() &&
                   !Flex::transmitting() && !HostLink::hostOpen();
      if (quiet && millis() - lastTry > backoff) {
        lastTry = millis();
        if (mqttConnect()) backoff = 5000;
        else               backoff = min<uint32_t>(backoff * 2, 60000);
      }
    }
    mqtt.loop();
  }

  if (millis() - lastBeat > 10000) {
    lastBeat = millis();
    StaticJsonDocument<256> doc;
    doc["event"]    = "heartbeat";
    doc["uptime_s"] = millis() / 1000;
    doc["rssi"]     = WiFi.RSSI();
    doc["wpm"]      = Keyer::getWpm();
    doc["busy"]     = Keyer::busy();
    doc["backend"]  = HostLink::getBackend() == WK_BACKEND_FLEX ? "flex" : "local";
    doc["wk_host"]  = HostLink::hostOpen();
    doc["tcp"]      = Net::clientConnected();
    if (Flex::enabled()) doc["flex"] = Flex::connected();
    char buf[256];
    serializeJson(doc, buf);
    if (mqtt.connected()) mqtt.publish(T_STATUS, buf, true);
  }
}

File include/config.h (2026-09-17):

#pragma once

// ============================================================
//  VUKEYER — config
//  Non-secret build config. Real credentials live in secrets.h
//  (git-ignored) — see secrets.h.example.
// ============================================================

// Personal settings live in secrets.h, which is git-ignored and written by
// install.py. It is included FIRST and every default below is #ifndef'd, so
// your own values win without editing — and a tracked file never changes,
// which keeps `git status` clean on a fresh clone.
#include "secrets.h"

// ── WiFi onboarding (WiFiManager captive portal) ──────────
// No compile-time SSID/password. First boot — or whenever the saved network is
// unreachable — the node opens AP vu2cpl-vukeyer-setup. Join it, pick your network,
// enter its password; creds persist in NVS.
#ifndef WIFI_AP_NAME
#define WIFI_AP_NAME           "vu2cpl-vukeyer-setup"
#endif
#ifndef WIFI_AP_PASS
#define WIFI_AP_PASS           "vu2cpl1234"
#endif
// 0 = the portal never times out. The portal is non-blocking here, so the
// keyer keeps keying while it is up and there is nothing to reclaim by
// closing it — whereas a timeout strands an un-onboarded board with no AP
// to join, which is exactly when you need it most.
#define WIFI_PORTAL_TIMEOUT_S  0

// ── Serial host link ──────────────────────────────────────
// A real K1EL WinKeyer runs its serial link at 1200 baud, 8 data bits, TWO
// stop bits, and loggers open the port that way without asking. RUMlogNG was
// observed doing exactly this (stty reported "speed 1200 baud; cs8 cstopb"),
// so the firmware must match or the handshake arrives as noise.
//
// The cost is that the console shares this port: at 1200 baud a chatty boot
// takes seconds, and the host cannot be answered until it finishes. So when
// the link is running at WinKeyer speed the boot log is trimmed to one line
// and the WiFiManager debug chatter is silenced — use the web page or
// /status for detail, both of which are unaffected.
#ifndef WK_HOST_BAUD_DEFAULT
#define WK_HOST_BAUD_DEFAULT  1200
#endif
#define WK_CONSOLE_BAUD       115200   // pick this with /baud for a readable log

// ── WinKeyer transport ────────────────────────────────────
// Raw WinKeyer byte stream over TCP; the host-side bridge in tools/
// maps it to a serial port. Advertised as _vukeyer._tcp over mDNS.
#ifndef MDNS_HOSTNAME
#define MDNS_HOSTNAME   "vukeyer"
#endif
#ifndef WK_TCP_PORT
#define WK_TCP_PORT     8088
#endif

// ── FlexRadio (SmartSDR) backend ──────────────────────────
// Command API is TCP 4992. Discovery broadcasts: VITA-49 on UDP 4991
// (firmware > v1.1.3), legacy proprietary format on UDP 4992.
#define FLEX_API_PORT            4992
#define FLEX_DISCOVERY_PORT_NEW  4991
#define FLEX_DISCOVERY_PORT_OLD  4992

// ── MQTT broker (shack) ───────────────────────────────────
// Broker requires auth (since 2026-08-21). Role account + password come from
// secrets.h — use the account scoped to this device (iot for sensors/Tasmota,
// svc for Pi/host publishers). Passwords are in the shack password manager.
#ifndef MQTT_HOST
#define MQTT_HOST       "192.168.1.10"
#endif
#ifndef MQTT_PORT
#define MQTT_PORT       1883
#endif
#ifndef MQTT_CLIENT_ID
#define MQTT_CLIENT_ID  "esp32-vukeyer"
#endif

// ── Topics (shack/<service>/...) ──────────────────────────
#ifndef T_STATUS
#define T_STATUS   "shack/vukeyer/status"   // retained; LWT publishes {"event":"offline"}
#endif

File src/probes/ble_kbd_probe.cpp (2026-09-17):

// ============================================================
//  ble_kbd_probe.cpp — standalone BLE keyboard test, NOT the keyer.
//
//  Question it answers: can this classic ESP32, on the same Arduino core
//  as the keyer (3.3.11 / IDF 5.5), pair with a BLE keyboard and receive
//  keys reliably WHILE WiFi is connected — and what does that cost WiFi?
//
//  Build/flash (replaces the keyer firmware until you flash it back):
//    ENV=ble-kbd-probe ./flash.sh
//    ./monitor.sh 115200
//  Restore the keyer:  ./flash.sh
//  Keyer settings survive: they live in NVS, which a flash does not touch.
//
//  Put the keyboard in BLUETOOTH pairing mode (not its 2.4 GHz dongle
//  mode). The probe scans, connects to the first device advertising as a
//  keyboard / HID, pairs, bonds, and prints every key press with a
//  timestamp. Every 10 s it prints heap, WiFi RSSI and link state.
//
//  WiFi cost: while Bluetooth runs, ESP-IDF requires WiFi modem sleep ON,
//  which the keyer turns OFF (main.cpp) to kill ~300 ms of packet latency.
//  Measure it from the Mac while the keyboard is connected:
//    ping <ip printed at boot>
//
//  Serial commands (115200, over the board's own USB):
//    f  forget all bonded keyboards      s  status now
//
//  Uses ESP-IDF's esp_hid host (BLE transport) directly — the only HID
//  host the precompiled core ships. Classic-Bluetooth keyboards are not
//  supported by that build.
// ============================================================
#include <Arduino.h>
#include <WiFi.h>
#include "esp_bt.h"
#include "esp_bt_main.h"
#include "esp_bt_defs.h"
#include "esp_gap_ble_api.h"
#include "esp_gattc_api.h"
#include "esp_hidh.h"
#include "esp_wifi.h"

// The core frees the Bluetooth controller's memory in initArduino() unless
// a BT library claims it. We use IDF directly, so claim it ourselves —
// without this, the controller init fails (or crashes) at runtime.
extern "C" bool bleInUse(void) { return true; }

// ── state ─────────────────────────────────────────────────
enum class St { StartScan, Scanning, OpenPending, Opening, Connected };
static volatile St st = St::StartScan;

static esp_bd_addr_t     targetBda;
static esp_ble_addr_type_t targetAddrType;
static char              targetName[32];
static esp_hidh_dev_t   *kbd = nullptr;
static uint32_t          keysSeen = 0, reconnects = 0;
static uint32_t          connectedAt = 0;

static String bdaStr(const uint8_t *b) {
  char s[18];
  snprintf(s, sizeof s, "%02x:%02x:%02x:%02x:%02x:%02x", b[0], b[1], b[2], b[3], b[4], b[5]);
  return s;
}

// ── HID usage → text ──────────────────────────────────────
// Boot keyboard report: [modifiers, reserved, key1..key6].
static const char *keyName(uint8_t u, bool shift) {
  static char one[2];
  if (u >= 0x04 && u <= 0x1D) { one[0] = (shift ? 'A' : 'a') + (u - 0x04); one[1] = 0; return one; }
  if (u >= 0x1E && u <= 0x27) {
    static const char n[] = "1234567890", s[] = "!@#$%^&*()";
    one[0] = (shift ? s : n)[u - 0x1E]; one[1] = 0; return one;
  }
  if (u >= 0x3A && u <= 0x45) {
    static const char *f[] = {"F1","F2","F3","F4","F5","F6","F7","F8","F9","F10","F11","F12"};
    return f[u - 0x3A];
  }
  switch (u) {
    case 0x28: return "Enter";   case 0x29: return "Esc";
    case 0x2A: return "Bksp";    case 0x2B: return "Tab";
    case 0x2C: return "Space";   case 0x2D: return shift ? "_" : "-";
    case 0x2E: return shift ? "+" : "=";  case 0x2F: return shift ? "{" : "[";
    case 0x30: return shift ? "}" : "]";  case 0x31: return shift ? "|" : "\\";
    case 0x33: return shift ? ":" : ";";  case 0x34: return shift ? "\"" : "'";
    case 0x35: return shift ? "~" : "`";  case 0x36: return shift ? "<" : ",";
    case 0x37: return shift ? ">" : ".";  case 0x38: return shift ? "?" : "/";
    case 0x39: return "CapsLock";
    case 0x49: return "Ins";     case 0x4A: return "Home";
    case 0x4B: return "PgUp";    case 0x4C: return "Del";
    case 0x4D: return "End";     case 0x4E: return "PgDn";
    case 0x4F: return "Right";   case 0x50: return "Left";
    case 0x51: return "Down";    case 0x52: return "Up";
  }
  return nullptr;
}

static void handleKeyboardReport(const uint8_t *d, uint16_t len) {
  // Some keyboards drop the reserved byte; accept both layouts.
  if (len != 8 && len != 7) return;
  static uint8_t prev[6];
  uint8_t mods = d[0];
  const uint8_t *k = (len == 8) ? d + 2 : d + 1;
  bool shift = mods & 0x22;
  for (int i = 0; i < 6; i++) {
    uint8_t u = k[i];
    if (u < 0x04) continue;                        // empty / rollover error
    if (memchr(prev, u, 6)) continue;              // still held, not new
    const char *name = keyName(u, shift);
    keysSeen++;
    if (name) Serial.printf("[%8lu] key %-6s (usage 0x%02x mods 0x%02x)\n", millis(), name, u, mods);
    else      Serial.printf("[%8lu] key ?      (usage 0x%02x mods 0x%02x)\n", millis(), u, mods);
  }
  memcpy(prev, k, 6);
}
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

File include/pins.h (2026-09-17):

#pragma once

// ============================================================
//  VUKEYER — GPIO map (classic ESP32 devkit, esp32dev)
//
//  Chosen to avoid strapping pins (0,2,5,12,15) and boot-glitch
//  outputs. Pot must be on ADC1 (GPIO32-39): WiFi disables ADC2.
//  Paddle jack convention: tip = dit, ring = dah (software-swappable).
// ============================================================

#define PIN_PADDLE_DIT   25   // input, internal pullup, paddle closes to GND
#define PIN_PADDLE_DAH   26   // input, internal pullup, paddle closes to GND
#define PIN_KEY_OUT      33   // active high → NPN/optocoupler to rig KEY
#define PIN_PTT_OUT      32   // active high → NPN/optocoupler to rig PTT
#define PIN_SIDETONE      4   // LEDC PWM → passive piezo
#define PIN_SPEED_POT    34   // ADC1_CH6, input-only; 10 k pot wiper, 3V3–GND
#define PIN_STATUS_LED    2   // onboard LED — lit while the key is down

// I²C — SSD1306 OLED. These are the ESP32's default I²C pins and every
// OLED library assumes them, which is why the OTRSP block was moved off
// them (2026-09-10) rather than the display being asked to move.
#define PIN_I2C_SDA      21
#define PIN_I2C_SCL      22

#define PIN_KEY_OUT2     18   // radio 2 KEY — same drive as radio 1
#define PIN_PTT_OUT2     19   // radio 2 PTT
#define PIN_FSK_OUT      27   // RTTY FSK keying line; mark = idle (invertible)

// The OTRSP/SO2R reservation that used to hold 16, 17, 27, 14, 13 and 5 is
// GONE (2026-09-11): there is no SO2R plan for this box, and holding six
// pins for work that was never going to start had begun to squeeze real
// features onto a resistor ladder. SO2R lives in ~/projects/SO2R box.
//
// Free: 13, 14, 16, 17, 23. Input-only spares: 35, 36, 39 (no
// internal pull-ups on those — a button there needs an external one).
//
// Avoid GPIO 5, 12 and 15: strapping pins, sampled at boot and pulsed on
// reset, so they make unreliable outputs and can stop the board booting.
// GPIO 6-11 are the SPI flash and are unusable. On a WROVER module 16/17
// are the PSRAM lines — fine on this WROOM-based D0WD-V3 devkit, but check
// before reusing them on a different board.

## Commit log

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2026-09-10 Portal must not time out, add /wifi command
    A 180 s portal timeout strands an un-onboarded board: the AP disappears
    while the operator is still fetching a phone, and there is then no way in
    without a reflash. The portal is non-blocking here so the keyer keeps
    keying while it is open - nothing is reclaimed by closing it. Set to 0.
    /wifi reports the joined network, /wifi portal reopens onboarding, and
    /wifi reset clears credentials, so recovery no longer needs a reflash.
    Documented that the keyer must share a subnet with the logging computer
    and the radio (mDNS and Flex discovery are both broadcast-based), and
    that port 8088 is unauthenticated - anyone on that network can key the
    transmitter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
    [config.h, main.cpp]
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2026-09-10 Don't switch serial to binary mode on a stray null byte
    A single 0x00 flipped the serial port into WinKeyer binary mode - and a
    stray 0x00 is exactly what the CP2102 line produces when a host opens the
    port. The result was a port that looked dead: the CLI stopped answering
    and the engine sat there emitting status bytes as binary garbage forever,
    with no way back short of a reboot. This bit us twice while testing and
    was misdiagnosed both times as an unresponsive board.
    Now the 0x00 and its sub-command are fed together and binary mode is
    entered only if that actually opened a host session; anything else is
    discarded and the CLI stays up. Verified by repeatedly opening the port,
    which used to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
    [main.cpp]
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2026-09-10 Stop a blocked MQTT reconnect from stalling the WinKeyer host link
    The keyer looked like it was stalling over WiFi: 2.7 s to answer host
    open, status bytes arriving in delayed bursts so a correct send appeared
    to key a single element. Diagnosed as a bad RF link - wrongly.
    PubSubClient::connect() blocks, its default socket timeout is 15 s, and
    it was retried every 5 s against a broker that refuses our credentials.
    While it blocked, loop() did not run, so Net::poll() and WinKeyer::poll()
    never serviced the host link. MQTT - the least important thing on the
    device - was starving the one thing that has to stay responsive.
    Now MQTT is skipped entirely while CW is in flight or a host session is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
    [main.cpp]
2026-09-10 Never let Flex BUSY hang forever; record the on-air test findings
    The dummy-load test exposed a bug that would hang a logger. BUSY was
    derived purely from 'cwx send' index vs 'cwx sent=' status, so when the
    radio accepted the text but never keyed it, pending() stayed non-zero
    forever and the host read BUSY indefinitely with no way out.
    Two ways out now: a refused command clears pending immediately (a command
    the radio rejected is never going to be acknowledged), and a time-based
    backstop sized from the text length and WPM catches the silent case where
    the radio accepts but does not transmit. The log says which, and names the
    likely causes, because they are not guessable from the host side.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
    [main.cpp]
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2026-09-10 Add /paddle bring-up diagnostic
    Tells a wiring fault apart from a firmware problem in one command, which
    is the first question every time a new board is assembled. Reports the
    debounced levers for 10 s and says plainly whether anything was seen.
    Blocks the host link while it runs; that is deliberate, it is a bench
    tool and the operator is standing at the board.
    Verified on the assembled hardware: both levers detected independently.
    [keyer.cpp, main.cpp]
2026-09-10 Key the radio over the network from the paddle
    This is what was asked for and it now works: paddle elements are keyed on
    the radio over WiFi, with no KEY or PTT wire.
    Three things were in the way, and the first was mine:
    0x50001000 is not an error. Per FlexRadio it means the command ran but the
    handler did not set a result, so the processor substitutes that code. Our
    error handling treated it as a failure, which made 'cw key' look
    unsupported when it had been working the whole time.
    keyEvent() used xQueueSendFromISR from the keyer task, which is not an
    ISR. Events never reached the socket, so the first fixed version still
    looked dead.
    A bare 'cw key' does nothing: the radio only keys for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
    [keyer.cpp, main.cpp]
2026-09-10 Persist the backend in NVS; document that network keying works
    The backend silently reverted to local on every flash and power cycle,
    which repeatedly made a working build look broken during bring-up. It now
    lives in NVS (wk/flexbe) and is restored at boot, after Flex::begin() so
    the key queue exists before the hook is attached. The three coupled side
    effects of a backend switch are factored into applyBackend() rather than
    duplicated between the CLI and boot.
    Verified across a real reboot: the setting comes back and keying works
    with no /backend command issued.
    Docs rewritten to match reality. The earlier CWX verdict is kept but
    marked superseded - it was an accurate record of CWX, which i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
    [main.cpp]
2026-09-10 Drop the time= parameter; add /flex ptt toggle
    PTT switches but no carrier appears. time= is in the radio's own time
    base and we were feeding it ESP32 millis(), which plausibly schedules the
    key edge to a moment that never arrives - PTT with no RF is exactly what
    that would look like. Removed it: keying on arrival costs the jitter
    compensation, but correctness comes first and it can be reinstated once
    the right time base is known.
    Also adds /flex ptt on|off. With break-in the radio can switch T/R off
    the key edge alone, so asserting xmit ourselves may be what suppresses
    the carrier - but that is a question for the operator's meter, not for
    reasoning, and it should not need a reflash to answ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
    [main.cpp]
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2026-09-10 Restore GUI client_handle; add /flex bind toggle
    Reverting the previous commit's switch to our own handle: FlexRadio's own
    guidance is that CWKey takes the GUI client's handle, because the keying
    happens in that client's transmit context. Tried our handle anyway - same
    refusal - so the documentation stands.
    Adds /flex bind on|off so the binding step can be tested independently,
    since binding also makes us a distinct client the radio might treat as
    competing for the transmitter.
    All six combinations now tested (our handle / GUI handle, bind on / off,
    xmit on / off). Every one returns 500000C2 'another client is
    transmitting or sending a CW/CWX message', while the radio simultaneously
    report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
    [main.cpp]
2026-09-10 Use 'cw ptt' for keying, per the FlexRadio wiki
    The wiki documents the keying sub-command as ptt, not key:
    cw ptt [1|0|on|off] time=<timestamp> index=<index>
    'Will transition radio between PTT and MOX or key on/off.'
    MORCONI's author shows 'cw key'; the radio accepts both, but they do not
    behave the same. Every cw key attempt returned 500000C2 'another client
    is transmitting'; the first cw ptt attempt was accepted with no error at
    all - the first clean acceptance in this whole investigation.
    Switchable at runtime with /flex cmd key|ptt, because which one actually
    produces RF is a question only a power meter answers, and reflashing to
    test each guess has been the slow part of this.
    Also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
    [main.cpp]
2026-09-10 RF works: default to cw key, and report why it would not
    Confirmed transmitting on the dummy load - the paddle keys the radio over
    WiFi with no KEY or PTT wire.
    The last blocker was not the protocol at all: the radio had NO SLICE IN
    USE. With no slice there is nothing to transmit on, and the radio reports
    no error whatsoever - it simply does nothing, which is indistinguishable
    from a broken keyer and is why this took so long to find.
    So the keyer now subscribes to slice status and says plainly when it
    cannot key: no slice in use, or the slice not in CW mode. /status shows
    readiness at a glance. Silence was the expensive part of this bug; the
    firmware should never be silent about it again.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
    [main.cpp]
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2026-09-10 Keep the two diagnostics this session actually needed
    Both were written under pressure as throwaway scripts and both earned
    their place, so they move out of the scratchpad before it evaporates.
    flex-check.py reports every silent prerequisite for Flex keying in one
    pass. The radio gives no error for a missing slice, a slice in the wrong
    mode, or a missing GUI client - it just transmits nothing, which looks
    exactly like a broken keyer. That cost hours today; it should cost one
    command next time.
    wk-timing.py timestamps each status byte and counts KEYDOWN against the
    text's real element count. Counting bytes inside fixed drain windows gave
    a false negative earlier - a delayed burst landed out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
    [flex-check.py, wk-timing.py]
2026-09-10 Add OLED panel and settings web page; make pot settings persist
    A wired speed pot went dead at every power cycle: /pot on only ever set
    a RAM flag, unlike /backend which saved to NVS. Anything the operator
    sets from the panel should outlive a reboot, so this adds a settings
    module that owns validation and NVS for all of them — and establishes
    the rule that operator settings persist while host session settings do
    not. A speed a logger sets for one contest must not permanently
    reconfigure the keyer.
    Putting that rule in one module also means the serial CLI and the new
    web page cannot drift apart on what a setting is called or what range
    it accepts; both call Settings::apply().
    The display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
    [display.cpp, keyer.cpp, main.cpp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]
2026-09-10 Find the OLED reliably: probe at 100 kHz, add /i2c, adopt without a reset
    Bench testing turned up two ways the panel could be wired correctly and
    still stay dark.
    The probe ran only at boot, so a panel wired to a running board was
    invisible until the next reset and said nothing about why. /i2c now scans
    the whole bus and prints every address that answers, along with the
    physical causes in the order they are worth checking; both /i2c and
    /disp on adopt a panel found that way, no reboot needed.
    The probe also ran at 400 kHz, which this panel manages only
    intermittently on breadboard leads — it was found on some boots and not
    others, which is the worst way for this to fail. Detection is not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
    [display.cpp, main.cpp]
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2026-09-10 Make the number boxes usable: arrow-key stepping, and stop the poll fighting
    Adjusting the PTT tail was painful for two reasons. The 1 Hz status poll
    overwrote any field mid-edit — `editing` was only ever claimed by the
    sliders, so the number boxes had no protection. And a naive fix would
    have made every key repeat its own POST and its own NVS write.
    Number boxes now claim the field on focus (exempting it from the poll)
    and debounce the write, so holding an arrow key costs one save at the
    end rather than one per repeat. Arrow handling is explicit rather than
    left to the browser so it clamps to each setting's range and Shift steps
    by 10.
    Also records the outcome of the listening test: the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
    [web.cpp]
2026-09-10 Fix the PTT tail doing nothing on the Flex backend
    flex.cpp kept its own private pttTailMs = 400 for releasing the radio,
    entirely separate from the keyer's cfgTailMs that /tail and the web panel
    write. The keyer's tail sequences the local PTT line; on the Flex backend
    the operator is listening to the radio, so every value tried was
    inaudible and the tail in force was always the hardcoded 400 ms.
    Settings::apply("tail") now drives both timers, and /api/state reports
    flextail beside tail so they can be seen to agree. Measured on the wire
    from the last "cw key 0" to "xmit 0": 150->157 ms, 250->255 ms,
    400->406 ms.
    Also corrects a claim in HANDOVER that the 400 ms tail had been chosen by
    ear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
    [settings.cpp, web.cpp]
2026-09-10 Speak WinKeyer's 1200 8N2, and stop the pot flooding the host link
    RUMlogNG opened the port and nothing happened. stty on the port it was
    holding said why: "speed 1200 baud; cs8 cstopb". A K1EL WinKeyer runs
    1200 baud 8N2 and loggers open it that way without asking, while this
    firmware ran 115200 8N1, so every handshake arrived as noise. No reset
    could help. It went unnoticed because every tool in tools/ defaulted to
    115200 — the protocol had only ever been tested against itself, so
    wk-test.py now defaults to the wire's rate instead.
    Baud is a persisted setting, applied before anything is printed since a
    logger has already sent Host Open by the time setup() runs. The console
    shares the po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
    [config.h, keyer.cpp, main.cpp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]
2026-09-10 Stop the console corrupting the host stream; monitor sent text locally
    With RUMlogNG finally talking to the keyer, two things it surfaced.
    Every Serial.printf in the firmware wrote ASCII to the same wire the
    WinKeyer session was using, so "[FLEX] ..." lines arrived at the logger as
    protocol data and were displayed in its CW window. Console output now goes
    through Log::, muted for the duration of a serial host session. Nothing is
    lost: the web page and MQTT carry the same state and do not share the port.
    And on the Flex backend the operator heard nothing while the rig
    transmitted, because buffered text goes straight to "cwx send" and the
    local keyer generates no elements of its own. The sam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
    [display.cpp, keyer.cpp, main.cpp]
2026-09-10 Restore operator settings when a host session ends; hover help on the page
    Manoj found PTT lead and tail sitting at zero. RUMlogNG had set them via
    WK command 0x04, which is the protocol working as intended — but nothing
    put them back. resetToDefaults() only cleared buffers, so the host's
    values outlived its session and stayed until the next reboot. That is
    precisely the leak the "operator settings persist, host session settings
    do not" rule exists to prevent, running in the wrong direction.
    Settings::restoreKeyer() now runs on host close and on transport drop, so
    a logger can never leave the keyer reconfigured behind it.
    Command 0x04 also set only the keyer's tail and not the Flex one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
    [settings.cpp, web.cpp]
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2026-09-10 Echo hand-sent characters back to the host
    Paddle echo was missing for two independent reasons. applyModeRegister()
    handled bits 5:4, 3 and 2 and ignored bit 6, so there was no path from
    paddle to host at all; and RUMlogNG sets 0x07, which asks for character
    echo but never for this one, so implementing it alone would still have
    been silent. Hence both the feature and an operator override.
    The decode is exact rather than signal decoding: these elements were
    generated by this keyer, so their shape is already known and the only
    judgement is where a character ends. Two dit-times of silence ends a
    character and five ends a word, derived from the element gap so they
    scale with speed for free. Buf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
    [keyer.cpp, main.cpp, settings.cpp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]
2026-09-10 Fix settings page rendering nothing
    The paddle-echo status line landed in the top-level binding block instead
    of inside refresh(), where `s` does not exist. The ReferenceError fired
    before any event handler was attached, so the whole page came up empty
    rather than just that one readout — nothing rendered and no control
    responded.
    Caught only because Manoj tried the page: the build was clean, and a
    clean build says nothing about whether the JavaScript runs.
    Also raises the state document from 1024 to 1536 bytes. It now carries 33
    fields, having been sized at 640 when it had twenty, and ArduinoJson
    truncates silently on overflow — which would have looked like exactly the
    same bug.
    Co-Au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
    [web.cpp]
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2026-09-10 Add a second radio's KEY/PTT, and six message memories
    The second KEY/PTT pair lands on 18/19 with /radio 1|2|both. Both is
    allowed on purpose — a rig plus an amp or monitor — but it keys two
    transmitters together so it is never the default, and switching radios
    drops every line first so a transmission cannot strand the outgoing radio
    keyed.
    Memories are six slots in flash with %C expanding to the callsign, played
    from the CLI, the web page or the API. They cost no GPIO, so front-panel
    buttons can be added later without touching any of this.
    Two things surfaced while building them.
    Text was being sent with Keyer::sendChar(), which stopped working on the
    Flex backend when the sidetone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
    [keyer.cpp, main.cpp, pins.h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]
2026-09-10 Sanitise for publication, and make local settings a prompt not an edit
    Ahead of going public: real shack addresses out of the tracked files —
    broker, radio, keyer and Mac IPs, the network segment map, SSIDs and a
    Flex GUI client handle — replaced with placeholders that keep the shape,
    since the docs teach why the segments matter. No credentials were ever
    committed; secrets.h has always been git-ignored.
    The setup AP password stays as it is: it is already public in
    esp8266-gps-ntp and vu2cpl-as3935-bridge, so changing it here alone would
    buy nothing and break a shack-wide convention. (GitHub's code search
    reported no matches for it; the raw files say otherwise.)
    Local settings now come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
    [config.h]
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2026-09-10 Support 16x2 and 20x4 I2C LCDs alongside the OLEDs
    The point is choice for whoever builds one: OLED panels and HD44780
    backpacks sit at different I2C addresses, so the FAMILY is detectable and
    a single firmware runs whichever is plugged in. Swapping a panel and
    picking Auto-detect re-probes the bus — going back to the OLED after
    trying an LCD needs no reflash, which was the requirement.
    Geometry still cannot be probed: a 16x2 and a 20x4 are the same chip at
    the same address, exactly like SH1106 vs SSD1306. Both stay settings, and
    both fail visibly rather than silently.
    Text panels get their own layout rather than a squeezed graphic one. 20x4
    carries speed, backend, address and link state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
    [display.cpp, settings.cpp, web.cpp]
2026-09-10 Add 16x2/20x4 LCD layouts, and document the 5V problem
    Both LCD sizes now render. 20x4 carries speed, backend, address and link
    state across four rows; 16x2 packs speed, mode, speed-source and backend
    into row 0 and keeps the address on row 1, yielding to KEY/TUNE only
    while sending. An earlier revision of this dropped the address from 16x2
    on a misreading of "no ip address" — it was a report that the line was
    not visible, not a request to remove it.
    The visibility turned out to be electrical, and is worth documenting
    because it presents as a firmware fault. HD44780 modules want 5V; run one
    from 3V3 and the characters are too faint to read at any contrast
    setting, which looks like a broke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
    [display.cpp]
2026-09-10 Show which radio is live on the display, and document every indicator
    /radio 1|2|both could select a second transmitter with nothing on the
    panel to say which one was live — the one status a keyer with two radios
    most needs to show. It now rides the backend as a single token: LOCAL1,
    FLEX2, FLEXB. Attached rather than spaced because the "both" letter B
    would otherwise sit next to the iambic mode letter, which is also A or B,
    and "FLEX B B HOST" is not a readable status line.
    That pushed 16x2 row 0 to 17 columns, which lcdLine would have truncated
    — silently cutting off the very digit being added. The iambic mode letter
    gives way there instead: it changes once a year, the live radio can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
    [display.cpp]
2026-09-10 Shorten FLEX to FLX on the display
    Frees a column on the status row, which matters most on the 16x2 where
    row 0 is at its limit. The three states keep their meanings: FLX ready,
    FLX! connected with no CW slice, FLX? not connected.
    LOCAL is now the widest backend token, so 60WPM FIX LOCAL1 still fills
    all 16 columns and the iambic mode letter stays off the two-line panel.
    [display.cpp]
2026-09-10 Fix random reboots: move the state document off the stack
    The board had begun rebooting at unpredictable intervals. The cause was
    StaticJsonDocument<2560> in handleState() — allocated on loopTask's 8 KB
    stack, alongside six String copies of the message memories and a String
    for the serialised output. The settings page polls that endpoint once a
    second, which is why it looked random rather than reproducible, and why
    nothing in the symptom pointed at JSON.
    I grew that document three times in one session, 640 to 1024 to 1536 to
    2560, each time to fit new fields, and never once checked where it lived.
    Now a DynamicJsonDocument on the heap, with the output String reserved up
    front. Verified a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
    [web.cpp]
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2026-09-10 Run the display bus at 100 kHz by default
    The panel was detected, reported present and enabled, and drew nothing.
    The cause was the bus rate: rendering kept 400 kHz whenever the panel
    answered its address at 400 kHz, and that is not evidence of anything —
    an address probe is one byte, a frame is a thousand. A panel on
    breadboard leads passes the first and fails the second, which is exactly
    the failure that is hardest to read, because every diagnostic the
    firmware offers says the display is fine.
    100 kHz is now the default for everything, with /disp fast to opt into
    400 kHz on wiring that deserves it and /disp slow to go back. The choice
    persists. Frame time goes from ~25 ms to ~100 ms, so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
    [display.cpp, settings.cpp]
2026-09-10 Drive the local PTT line from the radio, and only redraw what changed
    Several things from one testing session.
    PTT held progressively longer on longer transmissions. Not latency, which
    is constant. On the Flex backend the local PTT line was timed by the
    monitor copy of the text running through the local keyer, while the radio
    generated the real CW from "cwx send" — two independent generators, so
    any per-character difference accumulated over the message. The line now
    follows what the radio is actually doing: xmitOn for paddle keying,
    pending() for buffered text, the latter fed by the radio's own "cwx sent="
    reports. Keyer::setPttAuto(false) hands the line over on that backend;
    local keying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
    [display.cpp, keyer.cpp, main.cpp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]
2026-09-10 Skip the I2C bus entirely when the display is disabled
    Disabling the display only stopped it rendering. Display::begin() still
    probed the bus and initialised the panel at every boot, because it runs
    long before the saved settings are read — so "disabled" still meant
    "poke I2C on the way up", which is exactly where a stuck line hangs the
    board before the web server or the host link ever start.
    begin() now takes the persisted enable flag, read directly from NVS ahead
    of the rest of the restore, and returns without touching the bus when the
    panel is off. That makes the setting a real isolation switch: with it off,
    the firmware never probes, never initialises and never renders, so a board
    wit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
    [display.cpp, main.cpp, settings.cpp]
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
